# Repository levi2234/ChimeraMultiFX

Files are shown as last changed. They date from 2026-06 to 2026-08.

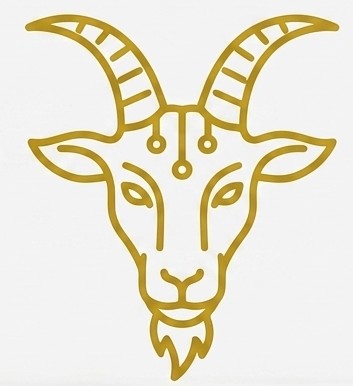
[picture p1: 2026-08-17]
hardware/boards/symbols/GOAT.jpg

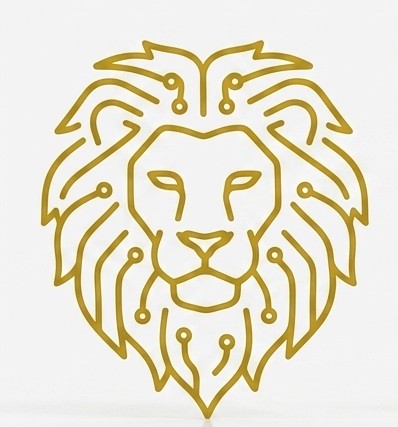
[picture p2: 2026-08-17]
hardware/boards/symbols/LION.jpg

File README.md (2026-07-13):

# ChimeraMultiFX

ChimeraMultiFX is a dual-MCU effects pedal platform. The Daisy Seed handles audio DSP while the ESP32 manages controls, Wi-Fi, and the browser-based UI.

## Repository layout

- [firmware/daisy](firmware/daisy) — Daisy Seed firmware built with libDaisy and DaisySP
- [firmware/esp32](firmware/esp32) — ESP32 control firmware and LittleFS web UI host
- [frontend](frontend) — Preact/Vite touch interface source
- [hardware/boards](hardware/boards) — KiCad PCB and schematic files
- [docs](docs) — repository notes and debugging write-ups

## Quick start

1. Review [firmware/daisy/README.md](firmware/daisy/README.md) for DSP build and flash steps.
2. Review [firmware/esp32/README.md](firmware/esp32/README.md) for ESP32 build, upload, and Wi-Fi setup.
3. Review [frontend/README.md](frontend/README.md) for local UI development.
4. Open [hardware/boards/daisyBoard.kicad_pro](hardware/boards/daisyBoard.kicad_pro) when working on hardware.

## Uploading code

- Daisy Seed: build with the Daisy make targets, then enter DFU bootloader mode and run the flashing command from [firmware/daisy/README.md](firmware/daisy/README.md).
- ESP32: build and upload from PlatformIO with the commands in [firmware/esp32/README.md](firmware/esp32/README.md).
- Frontend UI: build the web assets and upload them to the ESP32 filesystem using the steps in [frontend/README.md](frontend/README.md).

## Notes

- The ESP32 serves the built frontend from its LittleFS data partition.
- The Daisy and ESP32 communicate over UART; the ESP32 exposes a small HTTP/WebSocket bridge for the UI.

## License

MIT — see [LICENSE](LICENSE).

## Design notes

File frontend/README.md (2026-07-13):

# Frontend UI

This is the browser-based control surface for the pedal. It is built with Preact and Vite and is served by the ESP32 from LittleFS.

## Development

```bash
cd frontend
npm install
npm run dev
```

The Vite dev server is useful for UI work. Live DSP commands still depend on the ESP32 endpoints, so production testing should use the device URL.

## Build

```bash
cd frontend
npm run build
```

This writes the production bundle into [firmware/esp32/data](firmware/esp32/data), which the ESP32 serves as the web UI.

## Deploy

```bash
cd frontend
npm run build

cd ../firmware/esp32
pio run --target uploadfs
```

UI-only changes normally need only the filesystem upload step. If you changed the ESP32 firmware itself, run `pio run --target upload` as well.

## Structure

- [frontend/src/main.jsx](frontend/src/main.jsx) — app entry point
- [frontend/src/AppController.jsx](frontend/src/AppController.jsx) — main application state
- [frontend/src/components](frontend/src/components) — UI pieces such as lanes, knobs, and effect nodes

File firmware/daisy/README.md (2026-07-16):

# Daisy firmware

This firmware runs on the Daisy Seed and contains the DSP effect pipeline for the pedal.

## Build

```bash
git submodule update --init --recursive
cd firmware/daisy/deps/libDaisy
make
cd ../DaisySP
make
cd ../../
make
```

## QSPI boot setup

The application uses `BOOT_QSPI`, giving it nearly 8 MB of external flash. The
Daisy bootloader must be installed in internal flash once before QSPI
applications can run.

### DFU modes

The Seed has two different DFU implementations. Both can appear as USB device
`0483:df11`, but they expose different memory and are not interchangeable.

| DFU mode | Provided by | Memory exposed | Purpose | Command |
| --- | --- | --- | --- | --- |
| STM32 ROM DFU | Factory code inside the STM32 | Internal flash at `0x08000000` | Install or recover the Daisy bootloader | `make program-boot` |
| Daisy bootloader DFU | Daisy bootloader stored in internal flash | External QSPI flash from `0x90000000`, including the application at `0x90040000` | Upload the Chimera application | `make program-dfu` |

Enter STM32 ROM DFU by holding BOOT, pressing and releasing RESET, then
releasing BOOT. Enter Daisy bootloader DFU by pressing RESET without holding
BOOT, waiting for the user LED to pulse, then briefly pressing BOOT during the
two-second window.

Use `dfu-util -l` to tell them apart. STM32 ROM DFU reports `@Internal Flash
/0x08000000/...`; Daisy bootloader DFU reports an external `@Flash
/0x90000000/...` map. STM32 ROM DFU cannot upload the Chimera application to
QSPI, while the Daisy bootloader DFU is the normal mode for firmware updates.

### One-time bootloader installation

1. Connect the Daisy Seed to the computer over USB.
2. Enter the STM32 ROM DFU mode:
   - Hold the BOOT button.
   - Press and release RESET.
   - Release BOOT.
3. Install the Daisy bootloader:

```bash
cd firmware/daisy
make program-boot
```

## Upload code

The Daisy bootloader must be active before uploading a QSPI application. This
is different from the STM32 ROM DFU mode used to install the bootloader.

1. Connect the Daisy Seed over USB and release both buttons.
2. Press and release RESET only. Do not hold BOOT while pressing RESET.
3. Wait for the user LED to pulse during the Daisy bootloader's two-second DFU
   window, then briefly press BOOT to keep that window open.
4. Confirm that the Daisy bootloader is exposing QSPI flash:

```bash
dfu-util -l
```

The device description must contain an external flash map similar to:

```text
@Flash /0x90000000/64*4Kg/0x90040000/60*64Kg/...
```

If it reports only `@Internal Flash /0x08000000/...`, the Seed is in STM32 ROM
DFU mode and cannot write the QSPI application. Reset the Seed and repeat the
RESET-only, wait-for-pulse, then BOOT sequence above.

5. Build and upload the QSPI application:

```bash
cd firmware/daisy
make clean
make
make program-dfu
```

`program-dfu` writes the application to QSPI at `0x90040000`. `make program`
is intentionally unavailable for QSPI applications. If upload fails, confirm
that the Daisy bootloader is installed, its LED is pulsing, and `dfu-util` is
installed. The warning `Invalid DFU suffix signature` is harmless. An error
such as `Last page at 0x900... is not writeable`, together with an `Internal
Flash` interface name, means the Seed entered STM32 ROM DFU instead of the
Daisy bootloader.

For later uploads, the bootloader does not need to be reinstalled. If the Daisy
bootloader LED never pulses after a RESET-only press, enter STM32 ROM DFU using
the one-time setup sequence above and run `make program-boot` again.

## Quick test

The bridge protocol helper can exercise the UART command path from a host PC:

```bash
python Utils/bridge_protocol_test.py --serial-port COM9 ping info status "status lane 0"
```

State reads are intentionally split into bounded JSON responses:

- `status` returns only `lane_count` and `max_slots`.
- `status lane <lane>` returns routing and effect topology for one lane, without parameters.
- `status slot <lane> <slot>` returns live values and parameter definitions for one effect.

Clients should refresh only the lane or slot affected by a mutation. This keeps
response size independent of the total number of effect parameters in the rig.

The ESP32 firmware is the normal host for these commands in the finished system.

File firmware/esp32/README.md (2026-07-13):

# ESP32 control firmware

This firmware runs on the ESP32 and provides the pedal's control surface, Wi-Fi bridge, and browser UI host.

## What it does

- Connects to Wi-Fi and exposes a small HTTP/WebSocket API
- Bridges serial commands to the Daisy Seed over UART
- Serves the frontend from LittleFS so the UI can run without Node.js on the device

## Setup

1. Copy [firmware/esp32/src/wifi_credentials.example.h](firmware/esp32/src/wifi_credentials.example.h) to [firmware/esp32/src/wifi_credentials.h](firmware/esp32/src/wifi_credentials.h).
2. Add your local 2.4 GHz Wi-Fi credentials to the new file.
3. Install PlatformIO.

## Build and upload

```bash
cd frontend
npm install
npm run build

cd ../firmware/esp32
pio run
pio run --target upload
pio run --target uploadfs
```

### Upload steps

1. Connect the ESP32 board over USB.
2. Build the frontend assets if you changed the UI:
   ```bash
   cd frontend
   npm install
   npm run build
   ```
3. Upload the firmware:
   ```bash
   cd ../firmware/esp32
   pio run --target upload
   ```
4. Upload the web UI files to LittleFS:
   ```bash
   pio run --target uploadfs
   ```
5. Open the serial monitor if you want to confirm startup:
   ```bash
   pio run --target monitor
   ```

- `upload` flashes the ESP32 firmware.
- `uploadfs` updates the web UI assets in LittleFS.
- `pio run --target buildfs` builds the filesystem image without uploading it.

## Useful endpoints

- `GET /health`
- `GET /api/daisy/command?cmd=ping`
- `GET /api/bridge/selftest`

After boot, the board prints its IP address to the serial monitor. Use that address for the UI and API.

## Quick troubleshooting

If the Daisy bridge times out, run the protocol test from [firmware/daisy/Utils/bridge_protocol_test.py](firmware/daisy/Utils/bridge_protocol_test.py) and verify the UART wiring and ground connection between the two MCUs.

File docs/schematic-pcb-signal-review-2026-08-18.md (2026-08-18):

# ChimeraMultiFX Schematic, PCB, and Guitar Signal Review

**Date:** 2026-08-18  
**Design:** `hardware/boards/daisyBoard.kicad_sch` and `hardware/boards/daisyBoard.kicad_pcb`  
**Revision:** `d1bcdf6`  
**Scope:** Current schematic/PCB review, delta from the August 17 and August 18 reviews, and end-to-end risk of audible contamination of the guitar signal.

**2026-08-19 return-path recheck:** The current PCB has a GND via 0.875 mm from the `/SD_CLK_DAISY` transition and a GND via 1.09 mm from the `/SD_SCK` transition. Both provide a suitably short return path. `/SD_CLK_DAISY` now clears the analyzer; `/SD_SCK` remains reported only because the rule uses a hard 1.0 mm center-distance threshold and is treated as a false positive. No additional SD-clock return vias are required.

## Overview

ChimeraMultiFX is a dual-channel 48 kHz guitar-effects platform built around a Daisy Seed audio DSP and an ESP32 control/Wi-Fi processor. The carrier includes two buffered guitar inputs, two buffered audio outputs, a shared 2.5 V analog reference, expression inputs, two SD interfaces, socketed modules, and off-board audio jacks on a 100 mm x 100 mm four-layer PCB.

## Verdict

The analog signal path is now electrically plausible and should not strongly color the guitar band by itself. The 1 Mohm input bias preserves passive-pickup loading, the input RF poles are about 159 kHz, the output low-pass poles are about 21.9 kHz, and the coupling poles are below 2 Hz. The TL072H devices are valid at a nominal 5 V supply, and all unused op-amp channels are now biased as followers.

The design still has a **moderate, credible risk of audible Wi-Fi- or SD-correlated noise** in a prototype and a **significant unresolved risk for repeatable production or formal EMC testing**. The most likely symptoms are periodic ticks, buzz, discrete FFT spurs, startup pops, or a raised noise floor during ESP32 transmit and SD access. Gross loss of guitar tone is less likely than burst-correlated contamination or clipping on unusually hot inputs.

The static EMC score remains 37/100. This is a conservative layout-risk index, not a 37% pass probability. Sixty-nine of 118 EMC findings are heuristic reference-plane findings, so the score overstates the number of independent faults. The specific VREF, channel-2 audio, SD-clock, antenna, and cable-return mechanisms below remain physically credible.

## Critical Findings

| Priority | Finding | Guitar-signal impact | Required action |
|---|---|---|---|
| High | ESP32 is still represented by two headers with no exact body or antenna keepout | RF current can couple into the carrier, VREF, audio wiring, and enclosure; antenna behavior is not repeatable | Use the exact module/dev-board footprint and vendor keepout. Prefer antenna overhang and keep copper, traces, vias, wiring, and enclosure metal out of the specified volume. |
| High | VREF is 134.2 mm long, uses three layers and eight vias, with 51.3 mm on `In2.Cu` | Shared reference pickup appears at every analog stage and can become common-mode or output noise | Shorten the trunk, keep it over continuous GND, avoid the power layer, and add a GND return via beside each unavoidable transition. |
| Warning | `R24`, the 100 ohm VREF-buffer isolation resistor, was removed in the latest revision | Direct MCP6002 drive of a distributed capacitive net may reduce stability margin; exact load is unverified | Restore a small series isolation resistor close to U3 unless bench testing or a part-specific stability analysis proves direct drive is quiet and stable. Do not add large VREF capacitors downstream without validating the isolation network. |
| Warning | `/AUDIO_IN_2` and `/AUDIO_OUT_2` each change layers without nearby return stitching | RF return current detours can increase pickup and rectification in channel 2 | Keep each net on one outer layer or place a GND via next to the signal via. |
| Warning | `/SD_CLK_DAISY` and `/SD_SCK` change layers and remain on outer layers | Their adjacent GND vias provide short return paths, but clock ringing can still inject conducted or radiated energy | Keep the existing return vias and add source-series resistor footprints, nominally 22-47 ohm and selected from scope measurements. |
| High | Exact MPN coverage is 0% and no project datasheet cache exists | Ferrite current/DCR, bulk-cap effective value, module pinout, LED rating, and analog headroom are not reproducible | Populate Manufacturer/MPN/datasheet fields for all ICs, modules, ferrites, bulk capacitors, LEDs, SD sockets, and connectors. |
| Warning | Eleven via-in-pad findings remain in the ESP32 power/reference cluster | Open vias can wick solder and make power filtering inconsistent between assemblies | Move the vias outside lands or specify filled/capped via-in-pad fabrication. |
| Warning | `D1` with `R32 = 27 ohm` is estimated near 41 mA | Excess LED current can add supply/ground disturbance and threatens the LED | Select the LED and recalculate for about 1-5 mA unless high brightness is explicitly required. |

## Component Summary

The fresh schematic analysis found 112 non-power components across 163 nets: seven ICs, 31 resistors, 34 capacitors, 14 connectors, 19 test points, five LEDs, and two ferrite beads. The PCB contains 118 footprints and 104 physical nets. MPN coverage is 0/35 unique BOM parts, so component ratings and lifecycle status are not production-verified.

## Power Tree

```text
External +5 V
|-- FB2 -> VCC_Daisy
|   |-- Daisy Seed/module rails
|   |-- IC1-IC4 TL072H audio buffers
|   `-- U1-U2 MCP6002 expression buffers
|-- U3 MCP6002
|   `-- 100k/100k filtered midpoint -> U3A -> VREF
`-- FB1 -> VCC_ESP32
  `-- ESP32 module input and local 3.3 V regulation
```

The complete source current, module regulator limits, ferrite drop, and ESP32/SD peak demand cannot be checked without exact module and ferrite MPNs.

## Previous Review Delta

| Status | Item | Current result |
|---|---|---|
| Fixed | Standard TL072 below its minimum supply | `IC1`-`IC4` are `TL072HIDR`, whose family supports a 4.5 V minimum total supply. |
| Fixed | Floating unused TL072 channels | Pins 5 are on VREF and pins 6/7 form local followers on all four devices. |
| Fixed | Floating unused U3B channel | U3B is now a follower referenced to the filtered 2.5 V divider node. |
| Fixed | Residual analog via-in-pad at `C29:1` and `U3:8` | Neither is present in the fresh PCB findings. |
| Improved | Schematic/PCB consistency | No-connect markers fell from 25 to 10; cross-analysis findings fell from eight to seven. |
| Regressed | VREF isolation | `R24 = 100 ohm` was removed and U3A now drives VREF directly. |
| Regressed | VREF route length | The route increased from about 118.7 mm to 134.2 mm and now has eight vias. |
| Open | ESP32 antenna implementation | No keepout or rule area exists; only the two 1x15 header rows define the module. |
| Improved | SD/audio return transitions | Both SD clocks have acceptable adjacent GND vias. `/AUDIO_IN_2` now has a GND via 1.30 mm away; `/AUDIO_OUT_2` has no explicit GND via closer than 5.22 mm. |
| Open | Exact sourcing and ratings | Structured MPN coverage remains 0%. |
| Open | Native release evidence | No saved ERC/DRC report and no current Gerber release were found. |

## Signal Analysis Review

## End-to-End Audio Path

### Input channels

Each guitar input follows this topology:

```text
Jack tip
  -> 100 pF shunt RF capacitor
  -> 1 uF AC-coupling capacitor
  -> 1 kohm series resistor
  -> 1 nF shunt capacitor + 1 Mohm bias to VREF
  -> TL072H unity-gain buffer
  -> Daisy audio input
```

The nominal input coupling pole is:

$$
f_{HP,in} = \frac{1}{2\pi(1\,\text{M}\Omega)(1\,\mu\text{F})} \approx 0.16\,\text{Hz}
$$

The 1 kohm/1 nF RF pole is:

$$
f_{LP,in} = \frac{1}{2\pi(1\,\text{k}\Omega)(1\,\text{nF})} \approx 159\,\text{kHz}
$$

This is a good nominal guitar input impedance and should not remove audible bass or treble. The high-impedance node is nevertheless sensitive to RF, jack wiring, flux contamination, and VREF noise. Keep the off-board run shielded or use a twisted signal/return pair.

### Output channels

Each Daisy output follows this topology:

```text
Daisy audio output
  -> 3.3 kohm series resistor + 2.2 nF shunt capacitor
  -> 1 uF AC-coupling capacitor + 1 Mohm bias to VREF
  -> TL072H unity-gain buffer
  -> 100 ohm output resistor
  -> 1 uF output coupling capacitor
  -> 100 kohm pulldown
  -> output jack
```

The nominal reconstruction pole is:

$$
f_{LP,out} = \frac{1}{2\pi(3.3\,\text{k}\Omega)(2.2\,\text{nF})} \approx 21.9\,\text{kHz}
$$

The final 1 uF/100 kohm coupling pole is about 1.6 Hz. The 21.9 kHz first-order pole is approximately 0.8 dB down at 10 kHz and 2.6 dB down at 20 kHz. That is mild ultrasonic filtering, not severe guitar-band coloration, but capacitor tolerance should be included in an audio sweep.

### Route geometry

| Net | Length | Layers | Vias | Assessment |
|---|---:|---|---:|---|
| `/AUDIO_IN_1` | 70.35 mm | F.Cu | 0 | Long but single-layer; lower risk than channel 2 if continuously referenced to GND. |
| `/AUDIO_IN_2` | 63.49 mm | F.Cu/B.Cu | 1 | Add an adjacent return via. |
| `/AUDIO_OUT_1` | 55.09 mm | F.Cu | 0 | Single-layer and relatively low impedance. |
| `/AUDIO_OUT_2` | 46.58 mm | F.Cu/B.Cu | 1 | Add an adjacent return via. |
| `VREF` | 134.24 mm | F.Cu/B.Cu/In2.Cu | 8 | Highest shared analog coupling concern. |

No direct trace-proximity pairs were reported between audio/VREF and SD, UART, or ESP32 nets at the analyzer threshold. This reduces direct crosstalk risk. It does not cover far-field 2.4 GHz coupling, shared plane impedance, enclosure/cable coupling, or demodulation at op-amp inputs.

## Power and Ground

The four-layer order is `F.Cu / In1.Cu GND / In2.Cu power+GND / B.Cu`. The stored `In1.Cu` GND zone is filled at about 85.8% of board area and is the correct adjacent reference for top-side signals. The schematic calls the analog return `GNDA`, while the PCB intentionally implements it as the single `GND` net; there is not a physical split analog plane.

The connectivity analyzer reports seven GND islands, but most analog pads and 48 GND vias belong to one common island and the stored `In1.Cu` fill is one broad region. The isolated entries are concentrated around ESP power capacitors and SD socket pads and are likely union/zone-model artifacts. Do not accept or dismiss them solely from this analyzer: refill all zones and require native KiCad DRC to show zero unconnected items.

`FB1` isolates the ESP branch and `FB2` isolates the Daisy/analog branch, which is directionally good. Their impedance labels alone do not establish current capacity, DCR, DC bias behavior, or useful attenuation with the actual load-side capacitors. ESP32 current bursts and SD writes must be measured at `VCC_ESP32`, `VCC_Daisy`, and VREF simultaneously.

## PDN Impedance

The idealized analyzer model still indicates small anti-resonance regions near 5 MHz on `VCC_Daisy` and 7.9 MHz on `VCC_ESP32`. These are screening estimates only: generic capacitor parasitics, unknown DC-bias derating, unspecified ferrites, module-local capacitance, and mounting inductance prevent a verified impedance prediction.

## Power Budget

The schematic model estimates roughly 120 mA for the six analog ICs on `VCC_Daisy` and about 20 mA for U3 on +5 V. These coarse defaults exclude Daisy processing load, ESP32 transmit peaks, both SD cards, LEDs, and external loads. Size and measure the 5 V source and ferrites for simultaneous DSP, Wi-Fi transmit, and SD write activity.

## Sleep Current Audit

The design is not presently optimized as a battery-sleep product. Module current is not modeled, and the analyzer's state-based resistor-path estimate is not meaningful for product battery life without defined rail shutdown states. If battery operation is intended, add a hardware power-state budget and controllable rail isolation.

## Bus Topology

The board uses UART between ESP32 and Daisy, two independent SD/SPI-style interfaces, two audio input/output channels, and two expression ADC channels. The SD clocks are the highest-risk digital aggressors because both change layers without adjacent return vias; add source damping footprints and keep the interfaces over continuous GND.

## PCB Layout Analysis

- Board: 100 mm x 100 mm, four copper layers, 118 footprints, 104 PCB nets, 634 track segments, and 98 vias.
- Routing is represented as complete by the parser.
- Cross-analysis still reports `/SD_CLK_DAISY` crossing a `+3.3VD` plane boundary and audio nets crossing `+3.3VA` power-region boundaries. These are not proof of a broken GND return because `In1.Cu` is GND, but they indicate layer-3 power fragmentation and should be visually inspected.
- No enforceable antenna keepout exists anywhere on the PCB.
- `Card2` is reported only 0.32 mm from the board edge. Verify socket body, card insertion, copper clearance, and assembly panelization.
- No front-side fiducials were detected for 82 SMD components.
- Test-point coverage is about 11%. Add UART and both SD clocks; the existing audio, rail, VREF, and GND probes are useful.
- The remaining 11 via-in-pad cases are `C21`, `C22`, `C23`, `FB1`, `R22`, `R23`, and `TP21`, concentrated around ESP power and the reference-divider area.
- The existing fabrication archive predates this revision. It must not be ordered as the current board.

## EMC / Cross-Domain Analysis

The original FCC Class B-oriented static score was 37/100 from 118 findings across seven useful categories. After the return-path edits, a current rerun scores 46/100 with 117 findings. The credible subset is the missing return vias on VREF and `/AUDIO_OUT_2`, outer-layer clock routing, `/SD_CLK_DAISY` proximity to `J13`, and the absent ESP32 antenna keepout. `/AUDIO_IN_2` has a practical return via at 1.30 mm. The remaining `/SD_SCK` return warning is a threshold false positive because its GND via is 1.09 mm away. The repeated `GP-001` plane-coverage findings are heuristic and require visual/native DRC confirmation rather than literal counting.

## Thermal Analysis

The thermal analyzer ran at 40 C ambient but assessed zero components because no part had both quantifiable dissipation and usable MPN/datasheet data. This is a verification gap, not evidence that the ESP regulator, ferrites, SD cards, or analog devices will remain cool under sustained load.

## Test Coverage

Nineteen schematic test points cover about 11% of physical PCB nets, including useful audio, VREF, rail, and ground probes. Add accessible pads for UART, both SD clocks, and any module rail needed to correlate digital activity with audio artifacts.

## Assembly Complexity

The board has 82 front-side SMD components and no detected global fiducials. The main assembly risks are the 11 open via-in-pad cases, generic 100 uF footprints, unspecified socket/module geometry, and the SD socket edge placement rather than raw placement count.

## BOM Optimization

Further passive-value consolidation is not a priority. Preserve the intentional filter, bias, LED, and isolation values; focus BOM work on exact MPN qualification, capacitor technology/derating, ferrite current/DCR, and package consistency.

## How Real Is the Audible-Risk?

| Mechanism | Current risk | Why |
|---|---|---|
| Passive pickup loading / bass loss | Low | 1 Mohm input bias and approximately 0.16 Hz coupling pole. |
| Intended high-frequency rolloff | Low to moderate | About 0.8 dB at 10 kHz and 2.6 dB at 20 kHz from the output RC stage; verify component tolerance. |
| Normal op-amp hiss | Low to moderate | TL072H is appropriate for audio, but total noise depends on source impedance, resistor noise, gain staging, and Daisy converter noise. |
| Clipping with boosted/hot guitar levels | Moderate, unquantified | TL072H operates at 5 V, but input common-mode and output swing margin must be measured at the real load and VREF. |
| Wi-Fi burst ticking/buzz | Moderate | Physical separation and ferrite branches help; absent antenna keepout, long VREF, cable pickup, and shared return paths keep the mechanism credible. |
| SD-correlated tones | Moderate | Both clocks use layer transitions without adjacent return vias; `/SD_CLK_DAISY` also runs near `J13`. |
| Channel-to-channel mismatch | Low to moderate | Topologies match, but channel 2 has two additional signal transitions and different layer usage. |
| Assembly-induced noise/intermittence | Moderate | Eleven open via-in-pad findings and unspecified bulk/ferrite parts can create board-to-board variation. |

For a one-off enclosed prototype, a clean result is plausible and the board is not doomed to be noisy. For a repeatable product, the remaining risks are too dependent on exact module placement, cable routing, component selection, and enclosure bonding to call the audio path clean without measurement.

## Bench Acceptance Plan

1. Terminate the input with a pickup-like source impedance and record 20 Hz-20 kHz FFT/noise with Wi-Fi disabled, associated-idle, continuous transmit, and maximum configured transmit power.
2. Repeat while continuously reading and writing each SD interface. Compare channels separately to expose the channel-2 transition penalty.
3. Drive 100 Hz, 1 kHz, and 10 kHz tones; sweep input amplitude to find clipping at the input buffer, Daisy ADC/DAC, and output buffer. Record THD+N and maximum clean peak-to-peak level.
4. Sweep 20 Hz-24 kHz and compare measured response against the 21.9 kHz nominal output pole.
5. Probe VREF, `VCC_Daisy`, and `VCC_ESP32` during Wi-Fi and SD bursts. Look for correlated ripple, ringing, or sustained oscillation after the removal of `R24`.
6. Test boot, reset, firmware update, cable hot-plug, and Daisy clock loss for pops.
7. Repeat with the final shielded/twisted jack harness and final enclosure. Compare lid open/closed and antenna inside/overhanging the enclosure.
8. Use a near-field probe around the ESP power branch, antenna region, SD clocks, VREF buffer/trunk, and both input filters.

## Analyzer Verification

Fresh artifacts are under `analysis/2026-08-18_signal_review/`.

- Schematic analyzer: 112 components, 163 nets, 82 findings.
- Full PCB analyzer with proximity: 118 footprints, 104 nets, 634 segments, 98 vias, 69 findings.
- Schematic/PCB cross-analysis: seven findings.
- FCC Class B-oriented EMC analysis: 118 findings, 37/100 static score, seven useful categories.
- Thermal analyzer at 40 C: ran but assessed zero components because no usable MPN/dissipation data exist.
- Raw schematic, PCB, current Git delta, prior reports, and current zone/route metrics were inspected.

### Reviewer overrides

- The 69 `GP-001` findings are not 69 independent faults. The broad `In1.Cu` GND fill is real; local return discontinuities still require visual/native DRC inspection.
- The seven reported GND islands are not accepted literally because the connectivity model appears to separate pad/via/zone constructs in the ESP cluster. Native DRC is the deciding check.
- Several `DC-003` findings associate signal capacitors with unrelated IC decoupling. The dedicated local 100 nF capacitors remain the valid bypass evidence.
- Six schematic jacks absent from the PCB are treated as intentional off-board hardware. Mark them excluded from board and document the harness.

## Not Performed / Review Limits

- Native KiCad ERC/DRC was not independently run because `kicad-cli` is unavailable. The latest commit says DRC was checked, but no report is stored for review.
- SPICE was not run because ngspice, LTspice, and Xyce are unavailable.
- Datasheet extraction and lifecycle audit were not possible because no `datasheets/` cache exists and structured MPN coverage is 0%. Except for the previously established TL072H supply-family check, pin, rating, ferrite, and capacitor conclusions are consistency or plausibility checks.
- Thermal analysis had no modelable components; zero findings does not mean zero thermal risk.
- Current Gerbers were not available, so fabrication-layer and paste/drill checks apply only to the stale archive.
- Static analysis cannot predict absolute audible noise or regulatory margin. Final cables, enclosure, antenna placement, firmware activity, and source/load impedances require measurement.

## Recommended Order

1. Implement the exact ESP32 module footprint and antenna keepout/overhang.
2. Shorten VREF, remove it from `In2.Cu`, add transition return vias, and restore or validate output isolation at U3.
3. Keep the existing SD-clock return vias, add a closer return via for `/AUDIO_OUT_2`, and add source damping footprints for the clocks.
4. Qualify exact ferrites, bulk capacitors, modules, LEDs, sockets, and analog IC suffixes with structured MPN fields.
5. Correct `D1` current and resolve the remaining ESP-cluster via-in-pad construction.
6. Refill zones and save clean native ERC/DRC reports.
7. Regenerate and independently inspect Gerber, drill, BOM, and CPL outputs.
8. Pass the Wi-Fi/SD audio test matrix in the final enclosure before calling the signal path production-clean.

## Readiness

**Prototype bring-up:** reasonable after the antenna/VREF/return-via changes, with mandatory audio-noise and clipping tests.  
**Another fabrication order:** not recommended yet.  
**Production or FCC/CE readiness:** not demonstrated.

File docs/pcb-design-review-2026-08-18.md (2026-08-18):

# ChimeraMultiFX Schematic and PCB Review

**Date:** 2026-08-18  
**Design:** `hardware/boards/daisyBoard.kicad_sch` and `hardware/boards/daisyBoard.kicad_pcb`  
**Product intent:** Dual-channel 48 kHz Daisy Seed guitar-effects DSP with ESP32 Wi-Fi/control, browser UI, expression inputs, removable storage, and off-board audio jacks.

## Overview

The board combines a Daisy Seed audio engine, ESP32 network/control processor, dual analog audio conditioning, expression inputs, two SD interfaces, and off-board controls in a 100 mm x 100 mm four-layer design. The review prioritizes audio headroom and noise, reference stability, Wi-Fi/SD return paths, module integration, manufacturability, and repeatable sourcing.

## Verdict

**Not ready for fabrication yet, but materially improved.** `IC1`-`IC4` are now the 4.5 V-qualified `TL072HIDR`, all unused amplifier channels are safely biased, and the broad analog via-in-pad issue is almost completely resolved. Remaining pre-fabrication concerns are the missing ESP32 antenna keepout, two residual analog pad/via overlaps, long VREF routing, unqualified ferrites/bulk capacitors, absent structured MPN fields, and no current native DRC/ERC or Gerber release.

## Previous Review Delta

| Status | Item | Current result |
|---|---|---|
| Fixed | Local op-amp bypassing | All seven analog ICs now have a same-side 100 nF supply bypass about 2.2-3.1 mm from the package center. |
| Fixed | Layer order | `In1.Cu` is now the GND plane and `In2.Cu` is the power layer. The stored GND fill is one region with about 85.6% area coverage. |
| Fixed | TL072 supply range | `IC1`-`IC4` now specify `TL072HIDR`, whose 4.5 V minimum total supply includes the nominal 5 V rail. Pin 8 is VCC+ and pin 4 is GND in the selected SOIC-8 package. |
| Fixed | Unused op-amp channels | `IC1B`-`IC4B` pin 5 is on buffered VREF and each pin 6/7 pair shares a local feedback net. `U3B` pin 5 is on the filtered 2.5 V divider node and pins 6/7 share a local feedback net. |
| Improved | Analog via-in-pad | Analog-related VP-001 findings fell from 23 to 2; all four TL072H supply-pad overlaps were removed. |
| Improved | Overall via-in-pad | VP-001 findings fell from 84 to 13. Most remaining cases are in the ESP power cluster; `C29:1` and `U3:8` are the two remaining analog cases. |
| New | Analog rail ferrite | `FB2` replaces `NT1` between +5 V and VCC_Daisy. Connectivity is correct, but its current rating and DCR are unspecified. |
| Improved | EMC static score | Analyzer score increased from 13/100 to 37/100. This is a relative risk metric, not a compliance prediction. |
| Open | ESP32 antenna implementation | ESP32 remains two 1x15 headers with no body, antenna outline, courtyard, or copper/routing keepout. |
| Open | VREF distribution | About 118.7 mm long, six layer changes, and about 52.7 mm routed on the inner power layer. |
| Open | Sourcing/verification | MPN coverage remains 0%; exact pinout, ratings, capacitor derating, and ferrite suitability cannot be fully verified. |
| New | LED current | `D1` uses `R32 = 27 ohm`; static analysis estimates about 41 mA, excessive for a 0201 indicator LED. |

## Critical Findings

| Severity | Issue | Action before fabrication |
|---|---|---|
| High | No enforced ESP32 antenna keepout | Use the exact module/dev-board footprint and clear copper, tracks, vias, components, wiring, and enclosure metal around the antenna. Prefer antenna overhang. |
| High | No exact MPNs | Add MPN/manufacturer fields for ICs, modules, ferrites, LEDs, bulk capacitors, connectors, and SD sockets. |
| Warning | Two analog pad/via overlaps remain | Move the GND via out of `C29:1` and the supply via out of `U3:8`, or specify filled/capped via-in-pad. |
| Warning | `C18` and `C31` return vias are about 3.1/3.0 mm away | Bring each true bypass return via adjacent to the capacitor ground pad without putting the drill inside the solder land. |
| Warning | `FB2` is unqualified | Select an exact 0805 ferrite with sufficient current rating, low DCR, and impedance curve for the Daisy plus analog load. |
| Warning | VREF is long and changes layers six times | Keep it on an outer layer where practical, shorten the trunk, and place a GND return via beside each unavoidable transition. |
| Warning | Four nominal 100 uF capacitors use generic 1206 footprints | Select exact parts and validate package, polarity, voltage rating, effective capacitance under DC bias, leakage, and assembly orientation. |
| Warning | `D1` current is excessive | Recalculate for the chosen LED. A status LED usually needs roughly 1-5 mA, not about 41 mA. |
| Warning | Current Gerbers were not regenerated | Export a fresh fabrication set after all changes and inspect it in an independent CAM viewer. |

## Component Summary

The schematic analyzer found 113 non-power components: 7 ICs, 32 resistors, 34 capacitors, 14 connectors, 19 test points, 5 LEDs, and 2 ferrite beads across 174 schematic nets. The PCB contains 119 footprints, including intentional module/header and mechanical content. Exact sourcing data remain absent from structured MPN properties for all 35 unique BOM parts.

## Power Tree

```text
External +5 V
├── FB2, 600 ohm @ 100 MHz → VCC_Daisy
│   ├── Daisy Seed/module rails
│   ├── IC1-IC4 TL072HIDR audio op amps
│   └── U1-U2 expression buffers
├── U3 MCP6002
│   └── 100k/100k midpoint → U3A buffer → 100R → VREF
└── FB1 → VCC_ESP32
	└── ESP32 module input and local 3.3 V rail
```

The exact source current capability, ferrite drop, module regulator limits, and peak ESP32 demand remain unverified because source/module/ferrite MPNs are missing.

## Signal Analysis Review

Static analysis recognized the VREF divider/filter, analog RC networks, op-amp stages, SD/UART buses, and local decoupling. The op-amp configuration detector could not classify the stages reliably, so the critical analog conclusions below come from raw pin/net inspection rather than topology labels alone. SPICE confirmation is unavailable.

## VREF Review

The buffered-reference topology is directionally good:

- `R22 = 100 kohm` and `R23 = 100 kohm` create a nominal 2.5 V midpoint from 5 V.
- `C19 = 100 uF` and `C20 = 100 nF` filter the midpoint before `U3A`.
- `U3A` (MCP6002) is wired as the buffer.
- `R24 = 100 ohm` isolates the buffer output from the distributed VREF load and its parasitic capacitance.
- The four audio bias feeds use 1 Mohm resistors, so DC loading and drop across `R24` should be small.

With a 50 kohm Thevenin source and nominal 100 uF, the low-frequency pole is approximately:

$$
f_c = \frac{1}{2\pi(50\,\text{k}\Omega)(100\,\mu\text{F})} \approx 0.032\,\text{Hz}
$$

Do not add a large capacitor directly to the MCP6002 output by default. A capacitive load can reduce phase margin; the existing 100 ohm isolation resistor is the right kind of mitigation. If local VREF capacitors are added at remote stages, validate the total capacitance and isolation network against the exact op-amp datasheet or simulation.

### VREF layout observations

- Total routed length is about 118.7 mm: 51.4 mm on B.Cu, 14.9 mm on F.Cu, and 52.4 mm on `In2.Cu`.
- Six VREF transitions have no GND stitching via within 1 mm.
- Routing VREF on the power layer cuts and constrains power copper. Prefer a short outer-layer trunk over continuous `In1.Cu` GND.
- Keep VREF away from ESP32 antenna/current-burst paths and SD clocks.
- Probe VREF at `TP5` during Wi-Fi transmit and full-scale audio. Check DC level, startup settling, audio-band noise, and burst-correlated ripple.

## Local Decoupling

The new bypass network is a clear improvement and the net assignments are correct.

| IC | Bypass | Nets | Approx. distance | Assessment |
|---|---|---|---:|---|
| `IC1` | `C18`, 100 nF | VCC_Daisy-GND | 2.61 mm | Good |
| `IC2` | `C27`, 100 nF | VCC_Daisy-GND | 3.07 mm | Acceptable; move slightly closer if easy |
| `IC3` | `C26`, 100 nF | VCC_Daisy-GND | 2.31 mm | Good |
| `IC4` | `C28`, 100 nF | VCC_Daisy-GND | 2.51 mm | Good |
| `U1` | `C29`, 100 nF | VCC_Daisy-GND | 2.17 mm | Good |
| `U2` | `C30`, 100 nF | VCC_Daisy-GND | 2.78 mm | Good |
| `U3` | `C31`, 100 nF | +5V-GND | 2.17 mm | Good |

For the next layout pass:

- Prefer 0402 or 0603 for 100 nF high-frequency bypassing unless hand assembly dictates otherwise. A 1206 has higher connection inductance and is physically harder to place tight to SOIC supply pins.
- Route supply pin to capacitor first, then into the rail; connect the ground pad immediately to `In1.Cu` with an adjacent via.
- Avoid open vias centered in IC or capacitor lands. Tented opposite-side vias still can wick solder unless the fabricator fills/caps them.
- The revised layout clears this condition for nearly every analog IC and bypass capacitor. Move the remaining `C29:1` and `U3:8` vias as well.
- `C18` and `C31` are close to their ICs, but their nearest vias are now about 3.1 mm and 3.0 mm away. Put a GND via immediately beside each capacitor ground pad.
- Keep one local 1 uF per analog cluster and bulk capacitance at the rail entry.

## Op-Amp Suitability

### TL072HIDR

`IC1`-`IC4` now specify TI `TL072HIDR`. TI rates TL07xH for 4.5-40 V total supply, so nominal 5 V operation is valid. The selected `D` package is SOIC-8 and matches the existing footprint and pin map: pin 8 VCC+, pin 4 VCC-. The part is not rail-to-rail output, so clean input/output headroom around the 2.5 V reference still requires bench verification with worst-case boosted guitar levels.

The current schematic value identifies the exact part, but the structured MPN field remains empty and the Datasheet property incorrectly points to `tl074a`. Set Manufacturer=`Texas Instruments`, MPN=`TL072HIDR`, LCSC=`C4370389`, and Datasheet=`https://www.ti.com/lit/gpn/TL072H` on `IC1`-`IC4`.

### MCP6002

Microchip identifies MCP6002 as an in-production 1 MHz low-power op amp operating from 1.8 V. Its use at 5 V is plausible and the 100 ohm VREF output isolation is helpful. At about 28 nV/sqrt(Hz), it is not an especially low-noise audio amplifier, but it is reasonable for expression buffering and a low-current reference. Exact suffix/temperature/package MPNs are still required.

### Unused channels

All unused channels are now configured as followers at a valid 2.5 V bias. `IC1B`-`IC4B` have pin 5 on VREF and pins 6/7 on one local feedback net. `U3B` has pin 5 on the filtered divider node shared with `U3A` pin 3, `R22`, `R23`, `C15`, `C19`, and `C20`; pins 6/7 share one local feedback net. The unused outputs are not paralleled with VREF, which is correct.

## PCB Layout Analysis

### Positive findings

- Four-layer 100 mm x 100 mm board with `F.Cu / In1.Cu GND / In2.Cu power / B.Cu` ordering.
- Stored `In1.Cu` GND fill is one region and covers about 85.6% of the board area.
- ESP32 power remains isolated through `FB1` with local bulk and ceramic capacitance.
- Analog and digital regions are physically separated to a useful degree.
- Parser reports all routed nets complete.
- Analog-related via-in-pad findings dropped from 23 to 2; all TL072H solder lands are now clear of drilled vias.

### Remaining risks

- No keepout zones exist anywhere on the PCB. Copper remains under the probable ESP32 antenna area.
- VREF, audio, expression, and SD nets still change layers without nearby GND return vias.
- `/SD_CLK_DAISY` and `/SD_SCK` change layers without adjacent return vias and run on outer layers. Add source damping footprints if supported by the module interface and measured edge rate.
- The default net class permits 0.127 mm clearance and includes 0.127 mm routing. Use explicit classes for audio, power, SD clocks, and general signals instead of one permissive class.
- `Card2` is reported about 0.32 mm from the board edge. Verify the connector body, card insertion geometry, and fabricator copper-to-edge rules.
- No front-side fiducials were detected for 83 SMD parts. Add three global fiducials if using automated assembly.
- Test coverage is about 10%. Add accessible points for all rails, VREF, UART, SD clocks, and audio stage inputs/outputs.
- Two analog overlaps remain: `C29:1` and `U3:8`. Eleven additional VP-001 cases remain in the ESP power/reference cluster and should be reviewed before stencil assembly.

## EMC / Cross-Domain Analysis

The static FCC Class B-oriented risk score improved to 37/100 after the GND-first stack and local bypass changes. The remaining deterministic concerns are layer transitions without adjacent GND vias, outer-layer SD clocks, SD clock proximity to `J13`, and the absent ESP32 antenna keepout. The score cannot predict compliance or account for the final enclosure and cable harnesses; use it to prioritize bench and pre-compliance measurements.

### How impactful the 37/100 score is

The score is a conservative layout-risk index, not a percentage chance of passing, a 37% compliance result, or a measured dB margin. A value below 50 means the analyzer found enough common EMC failure patterns to justify another layout pass and bench testing. It does not by itself prove that this pedal will fail FCC or CE testing.

For this board, the score is more pessimistic than the raw layout evidence supports:

- 69 of 117 findings are `GP-001` reference-plane coverage findings: 59 errors and 10 warnings.
- The raw `In1.Cu` GND zone is filled as one region at about 85.8% board-area coverage, so the reported signal-by-signal plane gaps and 10 GND islands are not accepted literally.
- The scoring algorithm caps repeated findings from one rule, but `GP-001` still dominates the report and should be visually checked rather than counted as 69 independent faults.
- Only 7 of the analyzer's 18 EMC categories ran with useful data. The generated frequency-band plan reports no identified sources because exact module clocks, edge rates, switching frequencies, cable lengths, and enclosure geometry are unavailable. That is a coverage gap, not evidence of no emissions.

The credible residual risk is **moderate for a one-off enclosed prototype and significant for a product intended for sale or formal FCC/CE testing**. The likely first symptom is not necessarily a regulatory failure. For a guitar pedal, RF susceptibility and internal coupling can become audible before radiated emissions exceed a legal limit:

- Wi-Fi or SD activity can be demodulated by high-impedance audio inputs or VREF and appear as ticking, buzz, or a raised noise floor.
- Long guitar, amplifier, expression, USB, and power cables can carry common-mode current and become much better antennas than the 100 mm PCB itself.
- A metal enclosure can reduce direct electric-field radiation, but cable exits, unbonded jack grounds, seams, and the ESP32 antenna opening remain important.
- The ESP32 is an intentional 2.4 GHz radiator. Module approval helps only when the approved antenna/layout conditions are preserved; it does not certify the complete carrier, cables, clocks, or power network.

The highest-risk nets from the current analysis are `/SD_CLK_DAISY` with four rule hits and `/SD_SCK` with three. They combine outer-layer routing, reference-plane concerns, and missing return vias at layer changes. VREF, audio channel 2, expression inputs, and other SD signals have lower-severity transition findings that matter primarily because they can couple RF into the audio path.

### EMC improvement priority

1. **Implement the exact ESP32 antenna keepout.** Use the real module footprint, place the antenna at or beyond the board edge, and prohibit copper, traces, vias, components, wiring, and enclosure metal in the vendor-defined volume on every layer.
2. **Verify a continuous return plane under both SD clock routes.** Keep `/SD_CLK_DAISY` and `/SD_SCK` on one outer layer over uninterrupted `In1.Cu` GND where practical. Do not cross plane slots, power-zone boundaries, or antenna keepouts.
3. **Add return vias at every high-speed transition.** Put a GND via within about 1 mm of each SD/UART signal via. Also add nearby return vias for VREF, audio, and expression transitions to reduce RF loop area.
4. **Provide source-series damping footprints.** Place optional `22-47 ohm` resistors at the driving end of each SD clock and other fast single-ended lines. Start unpopulated or around 33 ohm, then select the value from oscilloscope edge/ringing measurements rather than treating one value as universal.
5. **Separate clocks from analog and connectors.** Increase spacing between SD clocks and VREF, audio inputs, expression inputs, and cable/header regions. The current `/SD_CLK_DAISY` proximity to `J13` is a credible coupling path.
6. **Finish the bypass-via cleanup.** Move `C29:1` and `U3:8` vias out of the lands and put the `C18` and `C31` GND vias directly beside their capacitor pads. Compact supply loops reduce both emissions and RF susceptibility.
7. **Control cable common mode.** Route each off-board audio/expression signal with an adjacent return conductor, preferably as shielded cable or twisted signal/ground. Add low-capacitance ESD protection at the connector and preserve the existing input RF filtering. Bond jack sleeves and enclosure deliberately instead of relying on incidental mechanical contact.
8. **Qualify `FB1` and `FB2`.** Select exact ferrites using impedance-versus-frequency, current rating, and DCR. Place local bulk plus 100 nF capacitance on the load side and verify that ESP32 transmit or Daisy load steps do not modulate analog rails.
9. **Add targeted ground stitching.** Stitch around connector regions and digital/analog boundaries. Near a 2.4 GHz antenna keepout boundary, approximately 3 mm spacing is a conservative RF fence target, but never place stitching inside the antenna keepout.
10. **Keep explicit net classes.** Give clocks, analog, and power intentional width/clearance rules rather than relying on the permissive default class.

### Practical EMC and audio-noise test plan

- Compare the audio FFT/noise floor with Wi-Fi disabled, associated but idle, continuous transmit, and maximum configured transmit power.
- Repeat while reading and writing both SD interfaces. Listen and measure specifically for clock-correlated tones and periodic bursts.
- Probe VREF, VCC_Daisy, VCC_ESP32, and the op-amp outputs simultaneously during Wi-Fi and SD load steps.
- Use a small H-field probe around the ESP power branch, SD clocks, FB1/FB2, VREF buffer, and audio input stages. Start with 30-300 MHz and inspect 2.4 GHz behavior with suitable equipment.
- Attach the final guitar, amplifier, expression, USB, and power cables during testing; cable radiation and susceptibility cannot be evaluated with the board alone.
- Test inside the final enclosure with all jack hardware and shields installed. Compare lid open/closed and antenna near/far from enclosure metal.
- Before commercial release, perform radiated and conducted pre-compliance scans. The static score is useful for prioritization but cannot replace measurement.

### Analyzer overrides

- The reported 10 GND islands are not accepted literally. The raw stored zone has one filled `In1.Cu` GND region at about 85.8% fill. The connectivity graph appears to count isolated pads/tracks as islands.
- Many GP-001 findings are similarly inflated. The corrected GND-first stack is real; local void crossings still need KiCad DRC and visual inspection.
- The two remaining analog via-in-pad warnings are geometric and real. Most prior findings were resolved by moving the vias beside the pads.
- Six schematic jacks (`J6`-`J11`) missing from the PCB appear to be off-board hardware. Mark them excluded from board and document the harness so this is intentional rather than ambiguous.

## Audio/Product Insights

- Preserve approximately 1 Mohm input impedance for passive guitar pickups. Verify the complete input network at audio frequencies, including ESD parts and jack wiring.
- Design analog headroom from worst-case guitar/boost-pedal levels, not nominal pickup output. Measure clipping onset at every analog stage and at the Daisy ADC.
- Add input protection that does not add excessive capacitance or leakage: series resistance, rail clamps/low-capacitance protection, and defined behavior for hot-plug transients.
- Keep Wi-Fi burst current out of analog supply and ground paths. Validate with Wi-Fi disabled, idle, and continuous maximum-power transmit while monitoring audio FFT, VCC_Daisy, and VREF.
- Route off-board audio as shielded or twisted signal/return pairs. Avoid sharing return conductors with LED, SD, or ESP32 currents.
- Consider relay or analog-switch mute behavior during boot, reset, firmware update, and loss of Daisy clocks to avoid loud pops.
- Document maximum input/output level, input impedance, output impedance, latency, sample rate, bypass behavior, and expression-pedal electrical standard as product requirements.

## Manufacturing and Sourcing

- MPN coverage is 0%, so the lifecycle audit and full pin/rating verification are blocked.
- `IC1`-`IC4` contain the correct `TL072HIDR` text value but still need Manufacturer/MPN/LCSC properties and the correct TI datasheet URL.
- `C13`, `C15`, `C19`, and `C21` are nominal 100 uF polarized capacitors assigned to generic 1206 footprints. Select real parts before relying on those values.
- `FB1` needs an exact impedance curve, current rating, saturation behavior, and DCR suitable for ESP32 transmit peaks.
- `FB2` needs the same qualification for the complete Daisy/analog branch. Its connectivity from +5 V to VCC_Daisy is correct.
- Set the intended copper finish; the KiCad stack currently records `None`.
- Add assembly notes for socketed Daisy/ESP32 modules, SD sockets, off-board jacks, and polarity/orientation-sensitive parts.

## PDN Impedance

The idealized model sees 9 capacitors totaling 100.8 uF on VCC_Daisy, 3 totaling 100.2 uF on VCC_ESP32, 10.1 uF on each modeled 3.3 V rail, and only 100 nF directly on +5 V at U3. It predicts small anti-resonances near 5.0 MHz on VCC_Daisy and 7.9 MHz on VCC_ESP32. Treat these values as screening estimates: generic package parasitics, missing MPNs, MLCC DC bias, ferrite impedance, module capacitance, and PCB mounting inductance are not modeled accurately.

## Power Budget

The analyzer estimates about 120 mA for the six analog ICs on VCC_Daisy and 20 mA for U3 on +5 V. These are coarse defaults, not datasheet totals, and exclude Daisy/ESP32 peak demand, SD-card transients, LEDs, and external loads. Measure the complete board and size the 5 V source and FB1 for ESP32 transmit and SD write peaks with margin.

## Sleep Current Audit

The heuristic worst case is 69.84 mA and the state-aware estimate is about 0.59 mA, dominated by pull paths. This pedal is not presently optimized as a battery-sleep product, and module currents are not modeled. If battery operation is planned, define a power-state budget and add hardware rail shutdown rather than relying on MCU sleep alone.

## Bus Topology

The schematic uses UART between ESP32 and Daisy, SD/SPI-style buses for removable storage, two audio channels, and two expression channels. No graphical KiCad bus objects are used. Give SD clocks explicit source-series resistor footprints, keep each bus over continuous GND, and document which MCU owns each card and chip-select during reset.

## Test Coverage

Nineteen test points cover 13 nets, including +5 V, VCC_Daisy, VCC_ESP32, VREF, expression references, audio jack pads, and ground. Missing key coverage includes +3.3VA, +3.3VD, ESP-3.3V, VIN, UART, and SD SPI nets. Add compact accessible pads before fabrication.

## Assembly Complexity

The analyzer rates assembly complexity low at 26/100: 111 SMD and 16 THT placements, mostly 0805, 1206, and SOIC. Five 0201-class parts are the hard placements. The via moves substantially reduce assembly risk; the residual concerns are 13 pad/via overlaps, ambiguous module geometry, generic 100 uF footprints, missing fiducials, and absent exact assembly part numbers.

## BOM Optimization

The passive set is already modest: 10 resistor values, 7 capacitor values, and one single-use passive value. Do not consolidate values at the expense of filter response, LED current, VREF noise, or stability. The priority is exact MPN qualification and package consistency, not further line-count reduction.

## Thermal Analysis

The thermal analyzer ran at 40 C ambient but assessed zero parts because no component had both quantifiable dissipation and usable MPN/datasheet data. This is a review gap, not evidence of low temperature. Check the 5 V source path, FB1, module regulators, SD cards, and any enclosure hot spots during sustained Wi-Fi and DSP load.

## Gerber Verification

The only complete fabrication archive is dated 2026-08-10 and predates the present revision. It contains all four copper layers, mask, paste, silk, edge cuts, PTH, and NPTH files. Analyzer warnings about differing copper extents and 43% front-paste-to-front-copper flash count require CAM inspection but may be benign. Regenerate all outputs after the design is frozen.

## Analyzer Verification

### Analyses performed

- Current schematic analyzer: 113 components, 174 nets, 78 findings.
- Current full PCB analyzer with proximity: 119 footprints, 115 PCB nets, 620 track segments, 98 vias, 72 findings.
- Schematic/PCB cross-analysis: 8 findings.
- FCC Class B-oriented EMC risk analysis: 117 findings, static risk score 37/100.
- Thermal analyzer at 40 C ambient: ran but skipped modeling because no MPN/power data were available.
- Archived Gerber/drill analyzer: three warnings; package is dated 2026-08-10 and predates this revision.
- Raw schematic, PCB, project settings, Git delta, firmware architecture, and manufacturer product pages inspected.

### Not performed / limits

- Native KiCad ERC and DRC were not run because `kicad-cli` is unavailable. Run both in KiCad after refilling all zones.
- SPICE was not run because ngspice, LTspice, and Xyce are unavailable.
- No project datasheet cache exists and no exact MPNs are populated. Most pin-level and rating checks are consistency-only.
- Thermal analysis produced no component temperatures because dissipative part data are missing.
- Lifecycle analysis was not meaningful with 0% MPN coverage.
- Current Gerbers do not exist; the reviewed fabrication archive is stale.

## Priority Order

1. Create the exact ESP32 module footprint and all-layer antenna keepout/overhang.
2. Move the remaining `C29:1` and `U3:8` vias; place the `C18` and `C31` GND vias adjacent to, but outside, their pads.
3. Add exact Manufacturer/MPN/LCSC/datasheet properties for TL072HIDR and qualify `FB2` current/DCR.
4. Shorten VREF, keep it off the inner power layer where practical, and add adjacent GND return vias.
5. Correct `D1` current and select exact bulk capacitors/ferrite/LED/module MPNs.
6. Add explicit net classes, fiducials, test points, and off-board harness documentation.
7. Refill zones, run native ERC/DRC, regenerate Gerbers/CPL/BOM, and inspect in CAM.
8. Perform bench noise, clipping, startup-pop, Wi-Fi transmit, RSSI, and final-enclosure tests.

## Final Readiness Checklist

- [x] TL072H supply range and SOIC-8 pin mapping valid at nominal 5 V
- [x] All unused amplifier channels safely biased
- [x] One local 100 nF bypass per analog IC
- [x] GND plane adjacent to F.Cu
- [ ] Exact ESP32 footprint and enforced antenna keepout
- [ ] No unapproved open via-in-pad construction (`C29:1` and `U3:8` still open in analog section)
- [ ] VREF transitions have adjacent return vias and reduced route length
- [ ] LED currents recalculated
- [ ] Exact MPNs and ratings populated
- [ ] Native ERC/DRC clean after zone refill
- [ ] Fresh Gerber, drill, BOM, and CPL files inspected
- [ ] Wi-Fi-correlated audio noise and final-enclosure RF tests passed

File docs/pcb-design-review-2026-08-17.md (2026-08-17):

# ChimeraMultiFX Schematic and PCB Review

**Date:** 2026-08-17  
**Design:** `hardware/boards/daisyBoard.kicad_sch` + `hardware/boards/daisyBoard.kicad_pcb`  
**Purpose reviewed:** Daisy Seed audio DSP, ESP32 Wi-Fi/control/UI, UART bridge, dual-channel audio input/output conditioning, expression inputs, and SD interfaces.

## Verdict

**Not ready for another fabrication run without changes.** The architecture matches the project purpose, and the ESP32 power branch already includes useful conducted-noise isolation. The principal blockers are:

1. Four ordinary TL072 devices are powered from a nominal 5 V single supply, below TI's 7 V minimum total supply specification.
2. All four unused TL072 B channels are left floating.
3. Local op-amp decoupling is inadequate: six analog ICs share only a small number of bypass capacitors placed far from several ICs.
4. The ESP32 dev-board antenna is not represented by a physical footprint or enforced keepout. Inner-layer copper extends beneath the probable antenna area.
5. Audio and reference nets change layers without nearby ground-return vias, and the four-layer stack has a fragmented power plane—not GND—adjacent to top-layer signals.

These issues can plausibly cause clipping/distortion, instability, idle noise, Wi-Fi-correlated ticking/buzzing, degraded ESP32 range, and board-to-board variation.

## Review Basis

### Analyses run

- KiCad schematic analyzer
- Full PCB analyzer with trace proximity and connectivity analysis
- Schematic ↔ PCB cross-analysis
- FCC Class B-oriented EMC risk analysis
- Thermal analyzer
- Gerber/drill analyzer on the archived production ZIP
- Raw schematic, PCB, BOM, CPL, project settings, and README inspection
- Manufacturer web documentation checks for TL072 supply range and ESP32 layout guidance

Generated evidence is under `analysis/2026-08-17_1502/`.

### Not performed / limits

- Native KiCad ERC and DRC were not run because `kicad-cli` is unavailable. Run both in KiCad before fabrication.
- SPICE was not run because ngspice, LTspice, and Xyce are unavailable.
- Thermal analysis ran but returned no modelable dissipative parts; this is a modeling gap, not proof of zero thermal risk.
- Lifecycle analysis was not useful because MPN coverage is effectively 0% in the schematic.
- Full per-component manufacturer pinout verification was not possible because no datasheet cache exists and most exact MPNs are absent.
- The exact ESP32 dev-board variant and antenna orientation are not encoded in the design. Antenna location is inferred from the header pin mapping and common 30-pin ESP32 DevKit geometry.

## Design Summary

- 100 mm × 100 mm, four-layer, nominal 1.6 mm FR-4 board.
- Stack: F.Cu / In1.Cu power / In2.Cu GND / B.Cu.
- 106 schematic components and 174 schematic nets.
- Daisy Seed and ESP32 are socketed modules with breakout headers.
- The ESP32 receives 5 V through `FB1`; `C21` (100 µF), `C22` (100 nF), and `C23` (100 nF) provide branch capacitance.
- `U3` buffers the midrail `VREF`; TL072 and MCP6002 stages condition audio/expression signals.
- Audio I/O routes between the analog stages and Daisy headers; physical jacks appear intended to be off-board/wired through test-point pads.

## Critical and High-Priority Findings

### 1. TL072 supply voltage is outside its specified operating range — CRITICAL

**Evidence basis:** raw schematic/PCB verified + TI product specification.

`IC1`–`IC4` have pin 8 on `VCC_Daisy` and pin 4 on analog ground. `VCC_Daisy` is tied to the nominal +5 V source through `NT1`. TI lists the standard TL072 minimum total supply voltage as 7 V. Therefore, 5 V single-supply operation is outside the guaranteed range.

This is not merely an audio-quality optimization. The op amps may have poor output swing, common-mode violations, distortion, phase reversal-like behavior, startup problems, or large unit-to-unit variation.

**Required action:**

- Replace `IC1`–`IC4` with a pin-compatible dual op amp explicitly specified for 5 V single-supply operation.
- Select for low noise, adequate GBW/slew rate, input common-mode range that includes the actual signal range around `VREF`, output swing under the real load, and stability at unity gain.
- Alternatively, redesign the analog supply to meet TL072 requirements, but this is less attractive for a 5 V digital/audio module system.
- Recalculate all stage headroom after selecting the replacement.

Reference: TI TL072 product page states a 7 V minimum total supply voltage: https://www.ti.com/product/TL072

### 2. Four unused TL072 amplifier channels float — HIGH

**Evidence basis:** raw PCB pad-net verification.

For each of `IC1`, `IC2`, `IC3`, and `IC4`, pads 5, 6, and 7 are unconnected. These are the B-channel non-inverting input, inverting input, and output. Floating unused op-amp inputs can allow oscillation or rail chatter, injecting noise into the shared supply and substrate.

**Required action:** configure each unused channel as a defined unity-gain follower:

- non-inverting input → `VREF`
- output → inverting input
- do not short the output directly to a rail

Follow the selected replacement op amp's unused-channel guidance.

### 3. Analog IC bypassing is inadequate and physically remote — HIGH

**Evidence basis:** schematic inventory + deterministic PCB placement checks.

The `VCC_Daisy` rail supplies four TL072s and two MCP6002s. The board does not provide one local 100 nF capacitor per IC. Existing rail capacitors `C16` and `C17` are near the Daisy/power area rather than beside every audio IC. Automated geometry checks found:

- no decoupling capacitor within 10 mm of `U2`
- nearest candidate to `U1` approximately 9.3 mm away
- nearest candidates to `IC1` and `IC2` approximately 5 mm away

Some automatically associated capacitors are actually signal-path parts, so the true bypass situation is worse than the raw detector summary.

**Required action:**

- Add one 100 nF X7R capacitor directly between pins 8 and 4 of every dual op amp.
- Place each capacitor on the same side, ideally within 2–3 mm of the pins.
- Give the ground pad an adjacent via to the In2.Cu GND plane.
- Add local 1 µF near each analog cluster and retain suitable bulk capacitance at the rail entry.
- Keep each bypass loop compact; do not route power from the IC pin to a remote capacitor and back.

This change is one of the highest-value ways to reduce Wi-Fi-correlated audio noise through shared impedance.

### 4. ESP32 antenna keepout is absent and copper extends beneath the likely antenna — HIGH

**Evidence basis:** raw PCB/analyzer geometry + Espressif layout guidance; antenna orientation is inferred.

The ESP32 is modeled only as two 1×15 socket rows (`J1` and `J2`). There is no module body, courtyard, antenna graphic, or copper/routing keepout. The PCB analyzer found zero keepout zones.

The probable module envelope spans approximately x=64.23–89.63 mm and y=53.51–89.07 mm. The `ESP-3.3V` plane on In1.Cu spans x=65.755–91.255 mm and y=50.28–90.78 mm, while the In2.Cu GND plane spans essentially the entire board. Therefore, both inner copper layers extend under the probable antenna end.

Espressif recommends putting a module antenna beyond the baseboard edge. If that is impossible, the antenna should be at the edge with baseboard material/copper cleared around and below it; at least 15 mm housing clearance is recommended in all directions.

**Required action:**

1. Identify and document the exact ESP32 dev-board model and orientation.
2. Replace the two-header-only representation with a real module/dev-board footprint containing:
   - complete body outline
   - pin-1/orientation marker
   - antenna outline
   - component courtyard
   - all-layer copper/track/via keepout under and around the antenna
3. Prefer letting the antenna end overhang the carrier-board edge.
4. If it cannot overhang, cut the carrier board back beneath/beside the antenna per the exact module guidance.
5. Keep metal enclosure walls, displays, cables, jack bodies, and wiring at least 15 mm away where practical.
6. Add GND stitching at the keepout boundary, but never put stitching vias inside the antenna keepout.

Reference: Espressif ESP32 Hardware Design Guidelines, module positioning and antenna keepout: https://docs.espressif.com/projects/esp-hardware-design-guidelines/en/latest/esp32/pcb-layout-design.html

### 5. Layer stack/reference arrangement increases coupling risk — HIGH

**Evidence basis:** raw-file/analyzer-derived.

Top-layer traces see In1.Cu first, but In1.Cu is a collection of power regions (`VCC_Daisy`, `ESP-3.3V`, etc.), not a continuous ground plane. The continuous GND plane is In2.Cu, farther from F.Cu. This creates reference changes and gaps for fast ESP32/SD/UART edges and weakens electrostatic shielding of high-impedance analog traces.

Cross-analysis reported signals crossing power/GND plane discontinuities, including audio, UART, SD clock/data, `VREF`, and expression ADC nets. The EMC score of 13/100 is pessimistic and includes false-positive amplification, but the stackup concern itself is real.

**Preferred action for the next revision:**

- Change the stack to F.Cu / solid GND / power or GND / B.Cu.
- Keep layer 2 unbroken except for the intentional antenna keepout.
- Route power as polygons/traces on layer 3, with GND fill in unused space.
- Do not route signals across power-island boundaries on the adjacent reference layer.
- Keep SD clock/data together over one continuous reference and add source series damping where supported by the module/interface.

This matches Espressif's recommended four-layer ordering: top signal, layer-2 solid GND, layer-3 power/GND, bottom signal.

### 6. Audio and `VREF` layer transitions lack adjacent return vias — HIGH

**Evidence basis:** deterministic PCB topology.

Detected transitions without a GND stitching via within 1 mm include:

- `/AUDIO_IN_2`
- `/AUDIO_OUT_2`
- `Net-(U1B-+)`
- six transitions on `VREF`
- both expression ADC inputs
- multiple SD/UART-related nets

At audio frequency this is not a transmission-line problem, but the same copper can receive or rectify 2.4 GHz RF. A tight high-frequency return path reduces the loop area and RF-to-audio conversion.

**Required action:**

- Keep high-impedance analog nets on one layer wherever possible.
- Add a GND via immediately beside every unavoidable analog signal via.
- Avoid long `VREF` routing. Treat it as a low-noise analog supply/reference, not an ordinary signal.
- Add local `VREF` bypassing at each destination cluster if permitted by `U3` stability requirements.

## ESP32-to-Audio Noise Assessment

### What is already good

1. **Physical partitioning is directionally good.** The likely antenna is near the top board edge; primary audio stages are mostly around y≈99–141 mm, providing useful separation.
2. **ESP32 conducted-noise branch exists.** `FB1` separates +5 V from `VCC_ESP32`, with 100 µF and two 100 nF capacitors on the ESP branch.
3. **A solid In2.Cu GND fill exists.** The zone itself is filled as one region with about 86% area coverage.
4. **Input networks include RF attenuation.** Series resistance and shunt capacitance around the analog inputs reduce demodulation of RF at op-amp inputs.
5. **Analog and digital supply nets are named and intentionally partitioned.** This is a good basis for controlled return-current design.

### What still allows audible Wi-Fi artifacts

- Unsupported TL072 operation and floating channels can rectify or amplify RF and supply disturbances.
- Sparse/remote bypassing raises analog supply impedance during ESP32 current bursts.
- Copper beneath the antenna alters the antenna and drives stronger RF currents into the carrier board.
- The top-layer adjacent reference is fragmented power, encouraging larger return loops.
- Long audio traces (approximately 48–70 mm) and the 121 mm `VREF` route offer coupling area.
- Analog layer changes lack local GND-return vias.
- Exact ferrite current rating and DCR are unknown because `FB1` has no MPN. A “600 Ω @ 100 MHz” value alone is insufficient; verify current rating for ESP32 transmit peaks and low enough DCR to avoid brownout.

### Recommended priority order

1. Replace the TL072s and terminate unused channels.
2. Add local bypassing to every analog IC.
3. Create and enforce the exact ESP32 antenna keepout/overhang.
4. Put solid GND on layer 2 and move power partitioning to layer 3.
5. Shorten/re-route high-impedance audio and `VREF`; add return vias.
6. Move the ESP ferrite/bulk network closer to the module 5 V entry if the dev board's own local input capacitance is insufficient.
7. Verify `FB1` current rating/DCR and measure the ESP branch at maximum TX power.

## Schematic Function Review

### Architecture fit

The schematic broadly matches the project:

- ESP32 handles Wi-Fi/control and communicates with Daisy.
- Daisy receives and outputs two audio channels.
- Analog front-end stages buffer/filter/level-shift external audio around `VREF`.
- Expression inputs are buffered before Daisy ADC inputs.
- Separate SD interfaces and module breakout headers support development and expansion.

### Additional schematic concerns

- Exact module MPNs are absent for the ESP32 dev board and Daisy Seed. Connector pinout correctness cannot be guaranteed without these identities.
- `FB1`–`FB3` have impedance values but no current/DCR/voltage ratings or manufacturer parts.
- Rail-source warnings exist because power inputs rely on passive connectors/net ties without explicit `PWR_FLAG` declarations. Add correct flags after verifying the intended source direction so ERC becomes useful.
- Six jack symbols (`J6`–`J11`) exist in the schematic but not on the PCB. This appears intentional for off-board jacks, but mark them explicitly as excluded from board and document the wiring harness/pinout.
- MPN coverage is below the pre-fabrication threshold. Exact parts are essential for pinout, package, voltage rating, ferrite current, and assembly verification.

## PCB / EMC Findings

### Ground-plane finding triage

The connectivity analyzer reported “42 GND islands,” but the raw GND zone is filled as one In2.Cu region. The island count likely includes isolated pads/tracks or an analyzer limitation and should not be treated literally without native KiCad DRC and visual inspection.

The following residual findings remain valid despite that likely overcount:

- In1.Cu is fragmented power and is adjacent to F.Cu.
- Multiple signals cross adjacent-layer power boundaries.
- GND return vias are absent beside many signal transitions.
- Copper exists under the probable ESP32 antenna.

### Routing and DFM

- Routing is represented as complete by the parser, but native KiCad DRC must confirm no unconnected copper.
- Several 0.127 mm analog/power traces are narrow but electrically adequate for op-amp signals; they are less robust for fabrication and return-path control than 0.20–0.25 mm routing.
- `Card2` is approximately 0.32 mm from the board edge and `Card1` approximately 0.82 mm. Verify connector-body and fab edge-clearance requirements.
- No front-side fiducials were detected despite 76 SMD placements. Add three global fiducials for automated assembly.
- Test-point coverage is approximately 10%. Add accessible points for ESP 5 V, ESP 3.3 V, Daisy 5 V, analog 5 V, `VREF`, GND, UART, SD clocks, and each audio stage input/output.
- The analyzer flagged many untented via-in-pad cases. Many are likely ordinary zone/via overlaps rather than true component-pad vias; inspect native DRC and fabrication outputs before accepting the warning.

## Gerber / Manufacturing Review

The archived production package contains:

- all four copper layers
- front/back mask, paste, and silkscreen
- edge cuts
- PTH and NPTH drill files
- 100 mm × 100 mm outline

Warnings requiring visual CAM confirmation:

1. Copper/edge extents vary by roughly 6.6 mm × 6.3 mm. This may be legitimate copper not reaching the board edge, so treat it as a likely analyzer false positive unless CAM visualization shows actual layer offsets.
2. Front paste flashes are 43% of front copper flashes. Through-hole pads and non-pasted copper explain much of this, but compare every SMD BOM item against paste apertures before ordering.
3. Project stackup says copper finish “None.” Explicitly set/document the intended finish (for example ENIG or lead-free HASL) before generating final outputs.
4. Re-export Gerbers after all electrical/layout corrections; the present archive is not suitable for ordering because it predates the required fixes.

## Verification and Bring-Up Plan

After revision:

1. Run KiCad ERC and DRC with all zones refilled.
2. Re-run schematic, PCB, cross, EMC, thermal, and Gerber analysis.
3. Power from a current-limited bench supply with the ESP32 removed; verify +5 V, `VCC_Daisy`, and `VREF`.
4. Install Daisy only and measure audio noise/distortion.
5. Install ESP32 and compare audio FFT/noise floor with Wi-Fi disabled, idle, continuous transmit, and maximum TX power.
6. Probe `VCC_ESP32`, `VCC_Daisy`, and `VREF` simultaneously. Look for Wi-Fi burst-correlated ripple.
7. Near-field probe the antenna area, ESP power branch, `VREF`, op-amp inputs, and audio connector wiring.
8. Check ESP32 throughput/RSSI with the final enclosure, display, wiring, and jacks installed.
9. Perform an A/B test with the ESP32 antenna physically outside the carrier edge. A large noise or RSSI improvement confirms antenna/copper coupling.

## Final Readiness Checklist

- [ ] TL072 replacement selected and validated at 5 V
- [ ] Every unused op-amp channel terminated safely
- [ ] 100 nF local bypass at every analog IC
- [ ] Exact ESP32 and Daisy module identities documented
- [ ] ESP32 footprint includes antenna/body/courtyard/keepout
- [ ] No copper/tracks/vias under antenna on any layer
- [ ] Antenna overhang or exact vendor-approved edge clearance implemented
- [ ] Layer 2 changed to solid GND or equivalent continuous adjacent reference demonstrated
- [ ] Analog signal transitions have adjacent GND vias
- [ ] `VREF` routing shortened and locally bypassed
- [ ] Ferrite MPN/current/DCR verified
- [ ] Off-board jack/harness intent documented
- [ ] Native ERC/DRC clean after zone refill
- [ ] Final Gerbers visually inspected and regenerated
- [ ] Wi-Fi TX audio-noise test passed in the final enclosure

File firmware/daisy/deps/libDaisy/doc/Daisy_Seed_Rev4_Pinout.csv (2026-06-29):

 | SCH name | Pin name | ADC | Arduino D# | Arduino A# | I2C | UART | SPI
1 | USB_HS_ID | PB12 | x | D0 |  |  | UART5_RX | SPI2_NSS/I2S2_WS | TIM1_BKIN |  |  | DFSDM1_DATIN1 | USART3_CK | FDCAN2_RX | OTG_HS_ULPI_D5 | ETH_MII_TXD0/ETH_RMII_TXD0 | OTG_HS_ID | TIM1_BKIN_COMP12 |  | EVENTOUT
2 | SDMMC1_D3 | PC11 | x | D1 |  |  | USART3_RX/UART4_RX | SPI3_MISO/ I2S3_SDI | HRTIM_FLT2 | DFSDM1_DATIN5 |  |  |  | QUADSPI_BK2_NCS | SDMMC1_D3 | DCMI_D4 | EVENTOUT
3 | SDMMC1_D2 | PC10 | x | D2 |  |  | USART3_TX/UART4_TX | SPI3_SCK/I2S3_CK | HRTIM_EEV1 | DFSDM1_CKIN5 |  |  |  | QUADSPI_BK1_IO1 | SDMMC1_D2 | DCMI_D8 | LCD_R2 | EVENTOUT
4 | SDMMC1_D1 | PC9 | x | D3 |  | I2C3_SDA |  |  | MCO2 | TIM3_CH4 | TIM8_CH4 |  | I2S_CKIN | UART5_CTS | QUADSPI_BK1_IO0 | LCD_G3 | SWPMI_SUSPEND | SDMMC1_D1 | DCMI_D3 | LCD_B2 | EVENTOUT
5 | SDMMC1_D0 | PC8 | x | D4 |  |  |  |  | TRACED1 | HRTIM_CHB1 | TIM3_CH3 | TIM8_CH3 | USART6_CK | UART5_RTS/UART5_DE | FMC_NE2/FMC_NCE | SWPMI_RX | SDMMC1_D0 | DCMI_D2 | EVENTOUT
6 | SDMMC1_CMD | PD2 | x | D5 |  |  | UART5_RX |  | TRACED2 | TIM3_ETR |  | SDMMC1_CMD | DCMI_D11 | EVENTOUT
7 | SDMMC1_CK | PC12 | x | D6 |  |  | UART5_TX | SPI3_MOSI/I2S3_SDO | TRACED3 | HRTIM_EEV2 |  |  |  | SDMMC1_CK | DCMI_D9 | EVENTOUT
8 | SPI1_NSS | PG10 | x | D7 |  |  |  | SPI1_NSS/I2S1_WS | HRTIM_FLT5 |  | LCD_G3 |  | FMC_NE3 | DCMI_D2 | LCD_B2 | EVENTOUT
9 | SPI1_SCK | PG11 | x | D8 |  |  |  | SPI1_SCK/I2S1_CK | LPTIM1_IN2 | HRTIM_EEV4 |  | SPDIFRX1_IN1 | SDMMC2_D2 | ETH_MII_TX_EN/ETH_RMII_TX_ EN | DCMI_D3 | LCD_B3 | EVENTOUT
10 | SPI1_MISO | PB4 | x | D9 |  |  | UART7_TX | SPI1_MISO/I2S1_SDI/SPI3_MISO/I2S3_SDI/SPI2_NSS/I2S2_WS/SPI6_MISO | NJTRST | TIM16_BKIN | TIM3_CH1 | HRTIM_EEV6 |  |  |  |  | SDMMC2_D3 |  | EVENTOUT
11 | SPI1_MOSI | PB5 | x | D10 |  |  | UART5_RX | SPI1_MOSI/I2S1_SDO/SPI3_MOSI/I2S3_SDO/SPI6_MOSI | TIM17_BKIN | TIM3_CH2 | HRTIM_EEV7 |  |  |  |  |  | FDCAN2_RX | OTG_HS_ULPI_D7 | ETH_PPS_OUT | FMC_SDCKE1 | DCMI_D10 |  | EVENTOUT
12 | I2C1_SCL | PB8 | x | D11 |  | I2C1_SCL/I2C4_SCL | UART4_RX |  | TIM16_CH1 | TIM4_CH3 | DFSDM1_CKIN7 |  |  | SDMMC1_CKIN |  | FDCAN1_RX | SDMMC2_D4 | ETH_MII_TXD3 | SDMMC1_D4 | DCMI_D6 | LCD_B6 | EVENTOUT
13 | I2C1_SDA | PB9 | x | D12 |  | I2C1_SDA/I2C4_SDA | UART4_TX | SPI2_NSS/I2S2_WS | TIM17_CH1 | TIM4_CH4 | DFSDM1_DATIN7 |  |  |  | SDMMC1_CDIR |  | FDCAN1_TX | SDMMC2_D5 |  | SDMMC1_D5 | DCMI_D7 | LCD_B7 | EVENTOUT
14 | USART1_TX | PB6 | x | D13 |  | I2C1_SCL/I2C4_SCL | USART1_TX/LPUART1_TX/UART5_TX |  | TIM16_CH1N | TIM4_CH1 | HRTIM_EEV8 |  | CEC |  |  |  | FDCAN2_TX | QUADSPI_BK1_NCS | DFSDM1_DATIN5 | FMC_SDNE1 | DCMI_D5 |  | EVENTOUT
15 | USART1_RX | PB7 | x | D14 |  | I2C1_SDA/I2C4_SDA | USART1_RX/LPUART1_RX |  | TIM17_CH1N | TIM4_CH2 | HRTIM_EEV9 |  |  |  |  | FDCAN2_TXFD_MODE | DFSDM1_CKIN5 | FMC_NL | DCMI_VSYNC | EVENTOUT
16 | AUDIO IN L | x | x | NC |  |  |  |  | x
17 | AUDIO INR | x | x | NC |  |  |  |  | x
18 | AUDIO OUT L | x | x | NC |  |  |  |  | x
19 | AUDIO OUT R | x | x | NC |  |  |  |  | x
20 | AGND | x | x | NC
21 | 3v3A | x | x | NC |  |  |  |  | x
22 | ADC_INP10 | PC0 | ADC12_INP10 | D15 | A0 |  |  |  | DFSDM1_CKIN0 | DFSDM1_DATIN4 |  | OTG_HS_ULPI_STP | FMC_SDNWE | LCD_R5 | EVENTOUT
23 | ADC_INP15 | PA3 | ADC12_INP15 | D16 | A1 |  | USART2_RX |  | TIM2_CH4 | TIM5_CH4 | LPTIM5_OUT | TIM15_CH2 |  | LCD_B2 | OTG_HS_ULPI_D0 | ETH_MII_COL | LCD_B5 | EVENTOUT
24 | ADC_INP5 | PB1 | ADC12_INP5 | D17 | A2 |  |  |  | TIM1_CH3N | TIM3_CH4 | TIM8_CH3N | DFSDM1_DATIN1 | LCD_R6 | OTG_HS_ULPI_D2 | ETH_MII_RXD3 | LCD_G0 | EVENTOUT
25 | ADC_INP7 | PA7 | ADC12_INP7 | D18 | A3 |  |  | SPI1_MOSI/I2S1_SDO/SPI6_MOSI | TIM1_CH1N | TIM3_CH2 | TIM8_CH1N |  |  | TIM14_CH1 | ETH_MII_RX_DV/ETH_RMII_CRS _DV | FMC_SDNWE | EVENTOUT
26 | ADC_INP3 | PA6 | ADC12_INP3 | D19 | A4 |  |  | SPI1_MISO/I2S1_SDI/SPI6_MISO | TIM1_BKIN | TIM3_CH1 | TIM8_BKIN |  |  | TIM13_CH1 | TIM8_BKIN_COMP12 | MDIOS_MDC | TIM1_BKIN_COMP12 | DCMI_PIXCLK | LCD_G2 | EVENTOUT
27 | ADC_INP11 | PC1 | ADC123_INP11 | D20 | A5 |  |  | SPI2_MOSI/I2S2_SDO | TRACED0 | SAI1_D1 | DFSDM1_DATIN0 | DFSDM1_CKIN4 |  | SAI1_SD_A | SAI4_SD_A | SDMMC2_CK | SAI4_D1 | ETH_MDC | MDIOS_MDC | EVENTOUT
28 | ADC1_INP4 | PC4 | ADC12_INP4 | D21 | A6 |  |  |  | DFSDM1_CKIN2 | I2S1_MCK | SPDIFRX1_IN3 | ETH_MII_RXD0/ETH_RMII_RXD0 | FMC_SDNE0 | EVENTOUT
29 | DAC1_OUT2 | PA5 | ADC12_INP19 | D22 | A7 |  |  | SPI1_SCK/I2S1_CK/SPI6_SCK | D2PWREN | TIM2_CH1/TIM2_ETR | TIM8_CH1N |  |  | OTG_HS_ULPI_CK | LCD_R4 | EVENTOUT
30 | DAC1_OUT1 | PA4 | ADC12_INP18 | D23 | A8 |  |  | SPI1_NSS/I2S1_WS/SPI3_NSS/I2S3_WS/SPI6_NSS | D1PWREN | TIM5_ETR |  |  | USART2_CK |  | OTG_HS_SOF | DCMI_HSYNC | LCD_VSYNC | EVENTOUT
31 | SAI2_MCLK_B | PA1 | ADC1_INP17 | D24 | A9 |  | UART4_RX |  | TIM2_CH2 | TIM5_CH2 | LPTIM3_OUT | TIM15_CH1N | USART2_RTS/USART2_DE |  | QUADSPI_BK1_IO3 |  | ETH_MII_RX_CLK/ETH_RMII_RE F_CLK | LCD_R2 | EVENTOUT
32 | SAI2_SD_B | PA0 | ADC1_INP16 | D25 | A10 |  | UART4_TX |  | TIM2_CH1/TIM2_ETR | TIM5_CH1 | TIM8_ETR | TIM15_BKIN | USART2_CTS/USART2_NSS |  | SDMMC2_CMD |  | ETH_MII_CRS | EVENTOUT
33 | SAI2_SD_A | PD11 | x | D26 |  |  |  |  | LPTIM2_IN2 |  | USART3_CTS/USART3_NSS | QUADSPI_BK1_IO0 |  | FMC_A16 | EVENTOUT
34 | SAI2_FS_B | PG9 | x | D27 |  |  | USART6_RX | SPI1_MISO/I2S1_SDI |  |  | SPDIFRX1_IN4 | QUADSPI_BK2_IO2 |  | FMC_NE2/FMC_NCE | DCMI_VSYNC | EVENTOUT
35 | SAI2_SCK_B | PA2 | ADC12_INP14 | D28 | A11 |  | USART2_TX |  | TIM2_CH3 | TIM5_CH3 | LPTIM4_OUT | TIM15_CH1 |  |  | ETH_MDIO | MDIOS_MDIO | LCD_R1 | EVENTOUT
36 | USB_HS_D_- | PB14 | x | D29 |  |  | USART1_TX | SPI2_MISO/I2S2_SDI | TIM1_CH2N | TIM12_CH1 | TIM8_CH2N |  |  | DFSDM1_DATIN2 | USART3_RTS/USART3_DE | UART4_RTS/UART4_DE | SDMMC2_D0 | OTG_HS_DM | EVENTOUT
37 | USB_HS_D_+ | PB15 | x | D30 |  |  | USART1_RX | SPI2_MOSI/I2S2_SDO | RTC_REFIN | TIM1_CH3N | TIM12_CH2 | TIM8_CH3N |  |  | DFSDM1_CKIN2 | UART4_CTS | SDMMC2_D1 | OTG_HS_DP | EVENTOUT
38 | 3v3D | x | x |  |  |  |  |  | x
39 | VIN | x | x |  |  |  |  |  | x
40 | GND | x | x |  |  |  |  |  | x
INTERNAL
MEM1 | QSPI | QSPI FLASH 8MB
MEM2 | SDRAM | SDRAM 64MB
 | USB FS D+ | USB FS
 | USB FS D- | USB FS
 |  |  |  |  |  |  |  |  |  |  |  |  |  | LPUART1_TX
internal SAI | I2C2 |  |  |  |  |  |  |  |  |  |  |  |  | LPUART1_RX
 | SAI1_MCLK_A | PE2 |  |  |  |  |  |  |  |  |  |  |  | UART4_RX
 | SAI1_SD_B | PE3 |  |  |  |  |  |  |  |  |  |  |  | UART4_TX
 | SAI1_FS_A | PE4 |  |  |  |  |  |  |  |  |  |  |  | UART5_RX
 | SAI1_SCK_A | PE5 |  |  |  |  |  |  |  |  |  |  |  | UART5_TX
 | SAI1_SD_A | PE6 |  |  |  |  |  |  |  |  |  |  |  | UART7_RX
 |  |  |  |  |  |  |  |  |  |  |  |  |  | UART7_TX
 |  |  |  |  |  |  |  |  |  |  |  |  |  | USART1_RX
On Board User LED | PC7 |  |  | D31 |  |  |  |  |  |  |  |  |  | USART1_TX
On Board Test Point | PG14 |  |  |  |  |  |  |  |  |  |  |  |  | USART2_RX
 |  |  |  |  |  |  |  |  |  |  |  |  |  | USART2_TX
BOOT | PG3 |  |  |  |  |  |  |  |  |  |  |  |  | USART3_RX
QSPI GPIO |  |  |  |  |  |  |  |  |  |  |  |  |  | USART3_TX
IO0 | PF8 |  |  |  |  |  |  |  |  |  |  |  |  | USART6_RX
IO1 | PF9
IO2 | PF7
IO3 | PF6
CLK | PF10
NCS | PG6

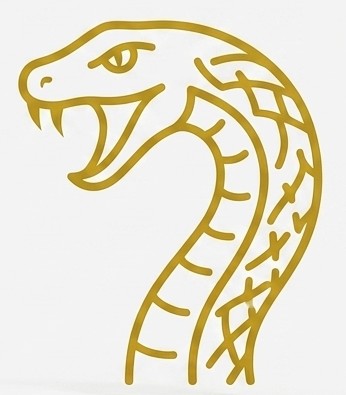
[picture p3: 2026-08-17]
hardware/boards/symbols/SNAKE.jpg

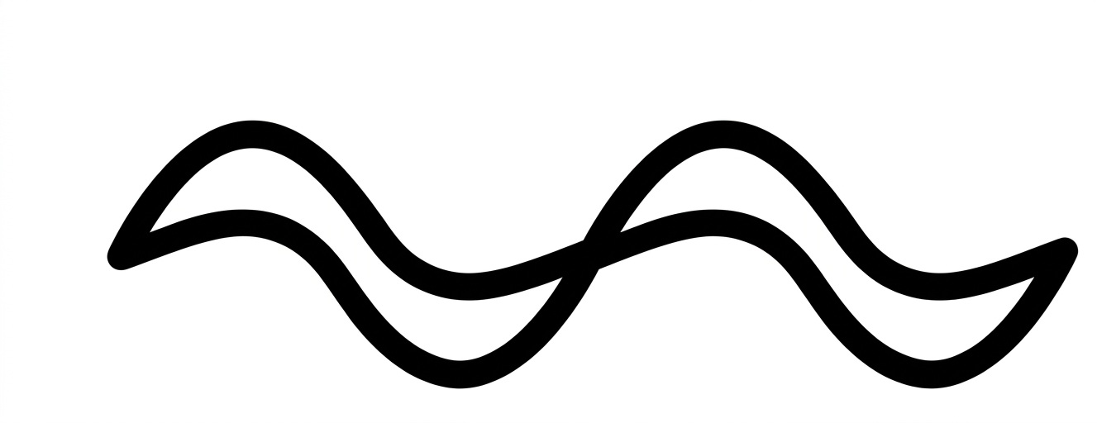
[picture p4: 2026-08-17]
hardware/boards/symbols/WAVE.jpg

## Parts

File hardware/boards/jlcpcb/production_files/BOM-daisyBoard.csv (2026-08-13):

Comment | Designator | Footprint | LCSC | Quantity
0.1uF | C14 | C_1206_3216Metric | C454377 | 1
100R | R11,R18,R21,R24,R7 | R_0805_2012Metric | C1015 | 5
100k | R12,R22,R23,R8 | R_0805_2012Metric | C25611 | 4
100n | C16,C17,C20,C22,C23 | C_1206_3216Metric | C24497 | 5
100p | C1,C4 | C_0805_2012Metric | C1790 | 2
100u | C13,C15,C19,C21 | C_1206_3216Metric | C15008 | 4
10K | R13,R14,R15,R16,R17,R25,R26,R27 | R_0805_2012Metric | C17414 | 8
10uF | C18 | C_1206_3216Metric | C13585 | 1
1M | R10,R2,R4,R6 | R_0805_2012Metric | C17514 | 4
1k | R1,R3 | R_0805_2012Metric | C17513 | 2
1n | C3,C6 | C_1206_3216Metric | C9196 | 2
1u | C11,C12,C2,C5,C8,C9 | C_1206_3216Metric | C1848 | 6
2M | R19,R20 | R_0805_2012Metric | C26112 | 2
2n2 | C10,C7 | C_1812_4532Metric | C2915766 | 2
600R @ 100MHz | FB1,FB2,FB3 | L_0805_2012Metric | C405006 | 3
Daisy PIN Breakout RIGHT | J16 | PinHeader_1x20_P2.54mm_Vertical | C124410 | 1
Daisy Pin Breakout LEFT | J15 | PinHeader_1x20_P2.54mm_Vertical | C124410 | 1
ESP32 Pin Breakout LEFT | J4 | PinHeader_1x15_P2.54mm_Vertical | C25503138 | 1
ESP32 Pin Breakout RIGHT | J3 | PinHeader_1x15_P2.54mm_Vertical | C25503138 | 1
LEFT Pin ROW | J1 | PinSocket_1x15_P2.54mm_Vertical | C2897378 | 1
LEFT Pin ROW Daisy | J13 | PinSocket_1x20_P2.54mm_Vertical | C53202183 | 1
MCP6002-xSN | U1,U2,U3 | SOIC-8_3.9x4.9mm_P1.27mm | C7377 | 3
RIGHT Pin ROW DAISY | J14 | PinSocket_1x20_P2.54mm_Vertical | C53202183 | 1
RIGHT Pin Row | J2 | PinSocket_1x15_P2.54mm_Vertical | C2897378 | 1
TL072 | IC1,IC2,IC3,IC4 | SOIC-8_3.9x4.9mm_P1.27mm | C1346149 | 4
Micro_SD_Card | J5 | microSD_HC_Molex_104031-0811 |  | 1
3R3 | R5 | R_0805_2012Metric |  | 1
3R3 | R9 | R_0805_2012Metric |  | 1
Micro_SD_Card | J12 | microSD_HC_Molex_104031-0811 |  | 1

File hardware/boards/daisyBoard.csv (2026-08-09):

Reference | Qty | Value | DNP | Exclude from BOM | Exclude from Board | Footprint | Datasheet
C1,C4 | 2 | 100p |  |  |  | Capacitor_SMD:C_1206_3216Metric
C2,C5,C8,C9,C11,C12 | 6 | 1u |  |  |  | Capacitor_SMD:C_1206_3216Metric
C3,C6 | 2 | 1n |  |  |  | Capacitor_SMD:C_1206_3216Metric
C7,C10 | 2 | 2n2 |  |  |  | Capacitor_SMD:C_1206_3216Metric
C13,C15,C19,C21 | 4 | 100u |  |  |  | Capacitor_SMD:C_1206_3216Metric
C14 | 1 | 0.1uF |  |  |  | Capacitor_SMD:C_1206_3216Metric
C16,C17,C20,C22,C23 | 5 | 100n |  |  |  | Capacitor_SMD:C_1206_3216Metric
C18 | 1 | 10uF |  |  |  | Capacitor_SMD:C_1206_3216Metric
FB1,FB2,FB3 | 3 | 600R @ 100MHz |  |  |  | Inductor_SMD:L_0805_2012Metric
IC1,IC2,IC3,IC4 | 4 | TL072 |  |  |  | Package_SO:SOIC-8_3.9x4.9mm_P1.27mm | http://www.ti.com/lit/ds/symlink/tl071.pdf
J1 | 1 | LEFT Pin ROW |  |  |  | Connector_PinSocket_2.54mm:PinSocket_1x15_P2.54mm_Vertical
J2 | 1 | RIGHT Pin Row |  |  |  | Connector_PinSocket_2.54mm:PinSocket_1x15_P2.54mm_Vertical
J3 | 1 | ESP32 Pin Breakout RIGHT |  |  |  | Connector_PinHeader_2.54mm:PinHeader_1x15_P2.54mm_Vertical
J4 | 1 | ESP32 Pin Breakout LEFT |  |  |  | Connector_PinHeader_2.54mm:PinHeader_1x15_P2.54mm_Vertical
J5,J12 | 2 | Micro_SD_Card |  |  |  | Connector_Card:microSD_HC_Molex_104031-0811 | https://www.we-online.com/components/products/datasheet/693072010801.pdf
J13 | 1 | LEFT Pin ROW Daisy |  |  |  | Connector_PinSocket_2.54mm:PinSocket_1x20_P2.54mm_Vertical
J14 | 1 | RIGHT Pin ROW DAISY |  |  |  | Connector_PinSocket_2.54mm:PinSocket_1x20_P2.54mm_Vertical
J15 | 1 | Daisy Pin Breakout LEFT |  |  |  | Connector_PinHeader_2.54mm:PinHeader_1x20_P2.54mm_Vertical
J16 | 1 | Daisy PIN Breakout RIGHT |  |  |  | Connector_PinHeader_2.54mm:PinHeader_1x20_P2.54mm_Vertical
R1,R3 | 2 | 1k |  |  |  | Resistor_SMD:R_0805_2012Metric
R2,R4,R6,R10 | 4 | 1M |  |  |  | Resistor_SMD:R_0805_2012Metric
R5,R9 | 2 | 3R3 |  |  |  | Resistor_SMD:R_0805_2012Metric
R7,R11,R18,R21,R24 | 5 | 100R |  |  |  | Resistor_SMD:R_0805_2012Metric
R8,R12,R22,R23 | 4 | 100k |  |  |  | Resistor_SMD:R_0805_2012Metric
R13,R14,R15,R16,R17,R25,R26,R27 | 8 | 10K |  |  |  | Resistor_SMD:R_0805_2012Metric
R19,R20 | 2 | 2M |  |  |  | Resistor_SMD:R_0805_2012Metric
TP1 | 1 | Global Ground - Functional |  |  |  | TestPoint:TestPoint_THTPad_D2.5mm_Drill1.2mm
TP2 | 1 | Global power 5V Input field - Functional |  |  |  | TestPoint:TestPoint_THTPad_D2.5mm_Drill1.2mm
TP5 | 1 | Reference voltage for the op amps - Probe |  |  |  | TestPoint:TestPoint_Pad_2.0x2.0mm
TP6 | 1 | Processed input power at 5V Daisy- Probe |  |  |  | TestPoint:TestPoint_Pad_2.0x2.0mm
TP7 | 1 | Jack Input 1 Pad |  |  |  | TestPoint:TestPoint_THTPad_D2.5mm_Drill1.2mm
TP8 | 1 | Jack Input 2 Pad |  |  |  | TestPoint:TestPoint_THTPad_D2.5mm_Drill1.2mm
TP9 | 1 | Jack Input 2 Pad GND |  |  |  | TestPoint:TestPoint_THTPad_D2.5mm_Drill1.2mm
TP10 | 1 | Jack Input 1 Pad GND |  |  |  | TestPoint:TestPoint_THTPad_D2.5mm_Drill1.2mm
TP11 | 1 | Jack Output 2 Signal Pad |  |  |  | TestPoint:TestPoint_THTPad_D2.5mm_Drill1.2mm
TP12 | 1 | Jack Output 2 GND Pad |  |  |  | TestPoint:TestPoint_THTPad_D2.5mm_Drill1.2mm
TP15 | 1 | Jack Output 1 GND Pad |  |  |  | TestPoint:TestPoint_THTPad_D2.5mm_Drill1.2mm
TP16 | 1 | Jack Output 1 Signal Pad |  |  |  | TestPoint:TestPoint_THTPad_D2.5mm_Drill1.2mm
TP17 | 1 | Exp Jack Input 1 Pad GND |  |  |  | TestPoint:TestPoint_THTPad_D2.5mm_Drill1.2mm
TP18 | 1 | Exp Jack Input 1 Signal |  |  |  | TestPoint:TestPoint_THTPad_D2.5mm_Drill1.2mm
TP19 | 1 | Exp Jack Input 2 GND |  |  |  | TestPoint:TestPoint_THTPad_D2.5mm_Drill1.2mm
TP20 | 1 | Exp Jack Input 2 Signal |  |  |  | TestPoint:TestPoint_THTPad_D2.5mm_Drill1.2mm
TP21 | 1 | Processed input power at 5V ESP32 - Probe |  |  |  | TestPoint:TestPoint_Pad_2.0x2.0mm
TP22 | 1 | EXPR REF 1 |  |  |  | TestPoint:TestPoint_THTPad_D2.5mm_Drill1.2mm
TP23 | 1 | EXPR Ref 2 |  |  |  | TestPoint:TestPoint_THTPad_D2.5mm_Drill1.2mm
U1,U2,U3 | 3 | MCP6002-xSN |  |  |  | Package_SO:SOIC-8_3.9x4.9mm_P1.27mm | http://ww1.microchip.com/downloads/en/DeviceDoc/21733j.pdf

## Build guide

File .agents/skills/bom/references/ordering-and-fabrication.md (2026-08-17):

# Ordering & Fabrication Reference

## Distributor Order Formats

Each distributor has a paste/upload format for adding parts to a cart. The `bom_manager.py order` subcommand generates these automatically.

### DigiKey — Bulk Add to Cart

Paste into the bulk-add box at [digikey.com/ordering/shoppingcart](https://www.digikey.com/ordering/shoppingcart):

```
3, 490-10698-1-ND, C1/C2/C5
1, ESP32-S3-WROOM-1-N16R8-ND, U1
5, 311-10.0KCRCT-ND, R1/R2/R3/R4/R5
```

Format: `quantity, DigiKey_PN, customer_reference` — comma or tab delimited, one line per part.

**FastAdd URL** — programmatic cart building:
```
https://www.digikey.com/classic/ordering/fastadd.aspx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
```
GET supports ~1700 chars; POST supports 400+ parts.

**BOM Manager** — [digikey.com/en/resources/bom-manager](https://www.digikey.com/en/resources/bom-manager). Upload CSV/XLS/XLSX, map columns interactively. Accepts both DigiKey PNs and MPNs.

### Mouser — Part List Import

Paste at [mouser.com/tools/part-list-import.aspx](https://www.mouser.com/tools/part-list-import.aspx) (requires login):

```
595-TPS63020DSJR|10
81-GRM155R71C104KA8D|3
```

Format: `Mouser_PN|quantity` — pipe delimited.

**FORTE BOM Tool** — [mouser.com/bomtool](https://www.mouser.com/bomtool/). Upload CSV/XLS/XLSX, auto-matching MPNs.

### LCSC / JLCPCB Assembly

Upload at [lcsc.com/bom](https://www.lcsc.com/bom) (max 800 lines):

```csv
Comment,Designator,Footprint,LCSC Part #
100nF,"C1,C2,C5",0402,C14663
ESP32-S3-WROOM-1,U1,ESP32-S3-WROOM-1,C2913202
```

Same format for JLCPCB assembly orders — see the `jlcpcb` skill.

### Newark / Farnell / element14

Paste at [newark.com/quick-order](https://www.newark.com/quick-order):

```
94AK6875,3
82AC7952,10
```

Format: `Newark_OrderCode, quantity` — comma or tab delimited.

**BOM Upload** — [newark.com/bom-upload-landing](https://www.newark.com/bom-upload-landing). Accepts both Newark PNs and MPNs.

### Arrow (Volume / Price Comparison)

**BOM Tool** — [arrow.com/en/bom-management-tool](https://www.arrow.com/en/bom-management-tool). Upload CSV/XLS/XLSX (max 3,000 lines). Accepts MPNs, Arrow PNs. Can purchase or request quotes directly.

### Quick Reference

| Distributor | Format | Delimiter |
|---|---|---|
| DigiKey | `qty, DK_PN, ref` | comma/tab |
| Mouser | `Mouser_PN\|qty` | pipe |
| LCSC | `Comment,Designator,Footprint,LCSC Part #` | comma |
| Newark | `OrderCode, qty` | comma/tab |
| Arrow | file upload only | — |

---

## Gerber & Stencil Export

### Required Gerber Layers

Export from KiCad: Fabrication > Plot (format: Gerber, coordinate format: 4.6 mm).

| KiCad Layer | Description |
|---|---|
| F.Cu / B.Cu | Front/back copper |
| F.Paste / B.Paste | Solder paste (stencil) |
| F.SilkS / B.SilkS | Silkscreen |
| F.Mask / B.Mask | Solder mask |
| Edge.Cuts | Board outline |

Also generate Excellon drill files (Fabrication > Generate Drill Files). Zip all together for upload.

### CPL (Component Placement List)

Export from KiCad: Fabrication > Generate Placement Files (CSV format).

| Column | Description |
|---|---|
| `Designator` | Reference designator |
| `Mid X` / `Mid Y` | Component center (mm) |
| `Rotation` | Angle (degrees) |
| `Layer` | `Top` or `Bottom` |

Both JLCPCB and PCBWay use the same CPL format.

### Stencil Ordering

Order a **framed stencil** alongside bare prototype PCBs (~$7 from JLCPCB). Generated from F.Paste gerber layer. Rigid frame for use with a stencil jig.

---

## Cost Summary Template

```
BOM Summary — Project: <name>
===================================
Unique parts:     23
Total components:  87
DNP:               3

Prototype (1 board, DigiKey):
  Parts:       $45.23
  PCB (JLC):   ~$7 (5 boards min, 2-layer)
  Stencil:     ~$7 (framed, from JLC)
  Shipping:    ~$5-12
  Total:       ~$64-71

Production (100 boards, JLCPCB assembled):
  Parts/board:     $8.50
  PCB fab/board:    $0.80
  Assembly/board:   $2.50
  Extended fees:    $0.09/board (3 extended x $3 / 100)
  Per board:        ~$11.89
  Total (100):      ~$1,189
```

Always query current pricing via the `digikey`, `mouser`, and `lcsc` skills — prices change frequently.

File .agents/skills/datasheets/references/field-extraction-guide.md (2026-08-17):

# Field Extraction Guide

How to find each schema field in a typical datasheet PDF. Covers section naming conventions by vendor, what language to look for, and common mistakes.

The extraction workflow starts with `datasheet_page_selector.py` identifying the relevant pages (pin table, absolute maximum ratings, operating conditions, electrical characteristics, application circuit). This guide describes what to look for once you have those pages.

Use `null` for any field the datasheet does not specify. Do not guess or interpolate.

---

## Page Selection Overview

The page selector uses a three-strategy approach:

1. **TOC present** — scans the first 1–3 pages for section headings with page numbers. TOC references to "Pin Configuration", "Absolute Maximum Ratings", "Electrical Characteristics", and "Typical Application" are automatically resolved to target pages.
2. **No TOC** — scores every page by keyword density. Pages containing "absolute maximum", "pin configuration", "electrical characteristics", and "application circuit" score highest.
3. **No pdftotext** — returns pages 1–5 plus evenly distributed pages.

Default page budget: 10 pages (15 for microcontrollers, FPGAs, SoCs). Always includes page 1 and the last page.

---

## Vendor Section Naming

Different manufacturers use different section titles for the same content. Recognizing these saves time.

### Texas Instruments (TI)

| Content | Typical Section |
|---|---|
| Pin table | §6 "Pin Configuration and Functions" or §7 |
| Absolute maximum ratings | §7.1 "Absolute Maximum Ratings" |
| Operating conditions | §7.2 "ESD Ratings" / §7.3 "Recommended Operating Conditions" |
| Electrical characteristics | §7.4 or §7.5 "Electrical Characteristics" |
| Application circuit | §9 "Application and Implementation" → §9.1 "Typical Application" |

### STMicroelectronics (ST)

| Content | Typical Section |
|---|---|
| Pin table | §4 "Pinouts" or "Pin definition" |
| Absolute maximum ratings | §5 or §6 "Absolute maximum ratings" |
| Operating conditions | Embedded in electrical characteristics table |
| Electrical characteristics | §6 or §7 "Electrical characteristics" |
| Application circuit | "Application schematics" or "Reference circuit" (late in doc) |

### NXP / Freescale

| Content | Typical Section |
|---|---|
| Pin table | §7 "Pinning information" |
| Absolute maximum ratings | §11 "Limiting values" or "Absolute maximum ratings" |
| Operating conditions | §12 "Recommended operating conditions" or "Characteristics" |
| Electrical characteristics | §12 "Characteristics" |
| Application circuit | "Application diagram" or "Typical application circuit" |

### Microchip / Atmel

| Content | Typical Section |
|---|---|
| Pin table | "Pin Diagrams" + "Pin Description" (separate pages) |
| Absolute maximum ratings | "Absolute Maximum Ratings*" (with footnote) |
| Operating conditions | Embedded in DC characteristics tables |
| Electrical characteristics | "DC Characteristics" / "AC Characteristics" |
| Application circuit | "Typical Application Circuit" or "Demo Board Schematic" |

### Espressif

| Content | Typical Section |
|---|---|
| Pin table | Pin description tables in early sections (often §2 or §3) |
| Absolute maximum ratings | "Absolute Maximum Ratings" — often a brief table |
| Operating conditions | "Recommended Operating Conditions" |
| Electrical characteristics | Peripheral-specific tables scattered through the document |
| Application circuit | "Typical Application Schematic" or hardware design guidelines doc |

Note: Espressif often separates the datasheet (pin specs, electrical) from a hardware design guidelines document (application circuit, decoupling). If the PDF is the datasheet only, the application circuit section may be minimal.

### Analog Devices / Maxim

| Content | Typical Section |
|---|---|
| Pin table | "PIN CONFIGURATION" + "PIN DESCRIPTION" (often on page 2) |
| Absolute maximum ratings | "ABSOLUTE MAXIMUM RATINGS" (all caps, early in doc) |
| Operating conditions | Part of main specifications table |
| Electrical characteristics | "ELECTRICAL CHARACTERISTICS" or "DC Specifications" |
| Application circuit | "Typical Application Circuit" or "Applications Information" |

---

## Field-by-Field Guidance

### `mpn`

Use the exact part number from the datasheet's title or ordering information page, including the package and temperature suffix (e.g., `TPS61023DRLR`, not `TPS61023`). Omit marketing names or family names.

### `manufacturer`

Use the company name as it appears on the datasheet header. For acquisitions (e.g., Maxim by Analog Devices, Linear Technology by Analog Devices), use the name on the datasheet being read, not the current parent company.

### `category`

Match to the category list in extraction-schema.md. The category determines which scoring rules apply. If the part spans categories (e.g., a PMIC with multiple regulators), use the primary function.

### `package`

Format: `"<package_name> (<pin_count>-pin)"`. Examples: `"TSSOP-14 (14-pin)"`, `"SOT-23-6 (6-pin)"`, `"QFN-32 (32-pin, 5x5mm)"`. The pin count is used to validate coverage in the scorer. Found in the ordering information or package outline section.

### `pins[].number`

Copy exactly as printed in the pin description table: `"1"`, `"2"`, `"A1"`, `"EP"` (exposed pad). Do not renumber or convert to integers.

### `pins[].name`

Copy from the pin name column. When the datasheet shows alternative names (e.g., `SW/VOUT`), use the primary name for the operating mode you're documenting.

### `pins[].type`

Map from the datasheet's function column:

| Datasheet language | Schema type |
|---|---|
| VDD, VCC, VIN, VSUPPLY | `power` |
| GND, AGND, PGND, VSS | `ground` |
| FB, COMP, VREF, VSET (analog) | `analog` |
| EN, SCL, SDA, TX, RX, CS, INT, ALERT | `digital` |
| NC, No Connect | `no_connect` |
| SDA/SCL (bidirectional bus), IO | `bidirectional` |

### `pins[].voltage_abs_max`

Found in the pin description table (individual pin limits) or the absolute maximum ratings table. Individual pin limits take precedence over the global abs max. Common traps:

- **SW pin on switching regulators**: often has a lower abs max than VIN (e.g., VIN = 6V, SW = 6V, but separate footnote limits SW to 5.6V during startup)
- **ESD clamp pins**: may have a negative lower limit (e.g., `-0.3V to 6V`) — store only the upper limit in this field
- **I/O pins on MCUs**: often have a separate `VDDIO` limit distinct from the main supply

### `pins[].threshold_high_v` / `pins[].threshold_low_v`

Look in the electrical characteristics table under "Logic Input Threshold" or similar. Common naming:

- `V_IH`, `VIH`, `V_IL`, `VIL` — standard logic threshold names
- `V_EN(H)`, `V_EN(L)` — enable pin thresholds (device-specific naming)
- `V_IN(H)`, `V_IN(L)` — input pin thresholds

Trap: Do not confuse `V_IH` (recommended minimum high input) with `V_OL`/`V_OH` (output levels). The extraction wants input thresholds — what the pin recognizes as logic high or low.

Trap: Some datasheets list thresholds as fractions of VDD (e.g., "0.7 × VDD"). Record the fraction notation in the description, and store the absolute value calculated at the nominal operating voltage in the field.

### `pins[].required_external`

This is the most important field for design review automation. Sources:

1. Pin description "External components required" columns
2. Application circuit notes referencing specific pins
3. Recommended operating conditions footnotes (e.g., "Bypass VIN to GND with 100nF")
4. Absolute maximum ratings notes (e.g., "Place clamp diode on boot pin for inductive loads")

Write in the datasheet's own language when possible. Include values and placement constraints where specified.

---

### `absolute_maximum_ratings`

Found in the "Absolute Maximum Ratings" table, usually near the front of the datasheet. Key naming conventions:

| Datasheet label | Suggested key | Unit |
|---|---|---|
| VIN(max), Input Voltage | `vin_max_v` | V |
| VOUT(max), Output Voltage | `vout_max_v` | V |
| TJ(max), Junction Temperature | `junction_temp_max_c` | °C |
| TSTG, Storage Temperature | `storage_temp_min_c`, `storage_temp_max_c` | °C |
| ESD (HBM) | `esd_hbm_v` | V |
| ESD (CDM) | `esd_cdm_v` | V |

Trap: **Absolute maximum ratings are not operating conditions**. Exposing a pin to its abs max continuously will shorten device lifetime. Do not use abs max values as operating targets.

Trap: Some datasheets list separate abs max for each pin in the pin description table. Capture those in `pins[].voltage_abs_max`, not here. The top-level absolute_maximum_ratings covers supply voltage and temperature.

---

### `recommended_operating_conditions`

Found in the "Recommended Operating Conditions" or "Operating Conditions" table. This is the range where the device is guaranteed to perform per the electrical characteristics.

Key traps:

- **VIN vs VOUT vs VDD**: multi-rail devices may have separate operating ranges for each supply. Use the most restrictive or the primary input.
- **Temperature grades**: datasheets may show industrial (−40 to +85°C) and commercial (0 to +70°C) variants in the same table. Extract for the grade you are using.
- **"Conditions" column**: some electrical characteristics tables embed operating conditions as conditions on specific rows. These are test conditions for that row, not the device operating range.

---

### `electrical_characteristics.*`

Found in the "Electrical Characteristics" table. This table is usually organized with columns: Parameter, Min, Typ, Max, Unit, Test Conditions.

Which value to record:

- Use **Typ** for `vref_v`, `switching_frequency_khz` (nominal specs)
- Use **Max** for threshold voltages, quiescent current limits, propagation delay
- Use **Min** for `dropout_mv` (worst case is what matters for design margin)
- Use **Typ** for SPICE model parameters (behavioral accuracy)

Key field lookup:

| Field | What to find in the table |
|---|---|
| `vref_v` | Reference voltage or feedback threshold; labeled "VREF", "VFB", "Feedback Voltage" |
| `switching_frequency_khz` | "Oscillator frequency", "Switching frequency", "fSW" |
| `quiescent_current_ua` | "IQ", "IDD (quiescent)", "Supply current (no load)" — exclude gate drive and switching losses |
| `dropout_mv` | "Dropout voltage" at rated output current; labeled "VDO", "VIN-VOUT" |
| `gbw_hz` | "Gain Bandwidth Product", "GBW", "Unity gain frequency" |
| `slew_vus` | "Slew rate", "SR" — use the slower of rising/falling |
| `prop_delay_ns` | "Propagation delay", "tPD" — use the worst case across all measurement conditions |
| `clamping_voltage_v` | "VC", "Clamping voltage" at the specified IEC 61000-4-2 test current |

Trap: **Gain Bandwidth vs Unity Gain Bandwidth**. Some datasheets list both. Use the unity-gain stable bandwidth for `gbw_hz`.

Trap: **Quiescent vs active supply current**. Record the quiescent (no-load, static) current, not the active switching current, unless the datasheet doesn't distinguish.

---

### `application_circuit.*`

Found in the typical application circuit section. This section often spans multiple pages with a reference schematic, a component table, and layout notes.

**topology**: Look for how the circuit is described in the section title or opening sentence: "boost converter", "buck converter", "buck-boost", "flyback", "SEPIC", "inverting buck-boost", "LDO". Use lowercase.

**inductor_recommended**: Usually in a "Inductor Selection" subsection or a component table. Capture value, saturation current requirement, and DCR guidance if given.

**input_cap_recommended / output_cap_recommended**: Labeled in the component table or application notes. Common format: `"10µF, X5R or X7R, 10V rating"`. Include dielectric and voltage rating if specified.

**vout_formula**: Look for a formula in the "Setting the Output Voltage" or "Programming Output Voltage" section. Record the exact formula; do not simplify.

**notes**: Capture layout-critical guidance: copper pour requirements, trace width recommendations, component placement distance constraints, feedback routing warnings.

Trap: Some datasheets have minimal application sections and instead reference an application note (SLVA XXXX, AN1234, etc.). If the datasheet itself has no circuit recommendations, set `application_circuit` to null and note the reference in `extraction_metadata`.

---

### `spice_specs.*`

SPICE specs come from the same electrical characteristics table as `electrical_characteristics`. The difference is that `spice_specs` uses the exact key names from `spice_part_library.py` for direct model generation.

For opamps: `gbw_hz`, `slew_vus`, `vos_mv`, `aol_db`, `rin_ohms` come from the electrical characteristics table. `supply_min`/`supply_max` come from recommended operating conditions. `rro`/`rri` come from the features list or the output swing specification (if the output swings within a few mV of the rail, `rro = true`).

For regulators: `vref` comes from the reference voltage spec. `dropout_mv` from the dropout table. `iq_ua` from quiescent current. `iout_max_ma` from the maximum output current rating.

---

## Common Mistakes

**Mixing abs max with operating conditions.** The schematic verifier compares pin voltages against `voltage_abs_max`; an incorrectly low value will generate false positives.

**Using the wrong table row.** Electrical characteristics tables often have multiple rows for the same parameter under different test conditions (temperature range, load current, VIN). Pick the row matching typical operation, not the extreme test condition.

**Leaving required fields null when the datasheet has them.** If the pin table has a voltage limit column, populate `voltage_abs_max` for every pin — not just the ones that look interesting. The scorer deducts points for name-only pins.

**Truncating the MPN.** `TPS61023` and `TPS61023DRLR` may have different specs (package parasitics, temperature grade). Extract from the correct datasheet and record the full part number.

**Copying from a different variant's table.** Datasheets often cover a family. Check that the table row applies to the specific part number you are extracting.

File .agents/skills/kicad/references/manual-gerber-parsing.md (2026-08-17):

# Manual Gerber & Drill Parsing (Script Fallback)

When `analyze_gerbers.py` fails (unsupported format, newer KiCad version, non-KiCad gerbers), fall back to direct file parsing. Gerber and Excellon are simpler line-oriented text formats compared to KiCad S-expressions, but correct coordinate handling and X2 attribute state tracking require care.

## Table of Contents

1. [When to Use Manual Parsing](#when-to-use-manual-parsing)
2. [Gerber RS-274X Parsing](#gerber-rs-274x-parsing)
3. [X2 Attribute Extraction](#x2-attribute-extraction)
4. [Excellon Drill Parsing](#excellon-drill-parsing)
5. [Layer Identification](#layer-identification)
6. [Gerber Job File (.gbrjob)](#gerber-job-file-gbrjob)
7. [Cross-Reference with KiCad Source](#cross-reference-with-kicad-source)
8. [Validation Methodology](#validation-methodology)

---

## When to Use Manual Parsing

Use manual parsing when:
- `analyze_gerbers.py` crashes or returns unexpected results
- The gerbers are from non-KiCad EDA tools (Altium, Eagle, OrCAD)
- You need to validate script output against raw file data
- You need specific data the script doesn't extract (arc geometry, region vertices)
- The file is partially corrupt but still readable

Always try the script first — it handles coordinate conversion, X2 attribute state tracking, drill classification, and layer identification automatically.

---

## Gerber RS-274X Parsing

Gerber files are line-oriented text. Each file represents one PCB layer. Parse line by line maintaining state.

### Step 1: Extract Format and Units

These appear in the file header and are required for coordinate conversion.

```python
import re

with open(gerber_path) as f:
    content = f.read()
    lines = content.splitlines()

# Format specification: %FSLAX46Y46*%
fs_match = re.search(r'%FS([LT])([AI])X(\d)(\d)Y(\d)(\d)\*%', content)
if fs_match:
    x_decimals = int(fs_match.group(4))  # typically 6
    y_decimals = int(fs_match.group(6))

# Units: %MOMM*% or %MOIN*%
units_mm = '%MOMM*%' in content  # True for mm, False for inch
```

**Coordinate conversion:** Raw integer coordinates divide by `10^decimals` to get the value in the declared unit. With `%FSLAX46Y46*%` and `%MOMM*%`:
- `X150000000` = 150000000 / 10^6 = 150.0 mm
- `X76687500Y-150250000` = (76.6875 mm, -150.25 mm)

With `%MOIN*%`, divide by 10^decimals to get inches, then multiply by 25.4 for mm.

### Step 2: Parse Aperture Definitions

Apertures define the "pen" shape for drawing and flashing. They appear in the header as `%AD` commands.

```python
apertures = {}
for line in lines:
    s = line.strip()
    m = re.match(r'%AD(D\d+)(\w+),?([^*]*)\*%', s)
    if m:
        d_code = m.group(1)      # e.g., "D10"
        shape = m.group(2)       # C (circle), R (rect), O (obround), RoundRect (macro)
        params = m.group(3)      # e.g., "0.200000" or "1.000000X0.600000"
        apertures[d_code] = {'shape': shape, 'params': params}
```

**Aperture shapes and dimensions:**

| Shape | Params | Dimension extraction |
|---|---|---|
| `C` | `diameter` | Trace width = diameter |
| `R` | `widthXheight` | Pad size (split on X) |
| `O` | `widthXheight` | Obround pad size |
| `RoundRect` | `radiusX...coords...` | Complex — 2x radius is a lower bound |

For trace width analysis, focus on `C` (circle) apertures used with D01 (draw) commands — the diameter directly gives the trace width.

### Step 3: Stateful Command Parsing

Parse draw/flash/move operations maintaining current position and aperture state.

```python
current_aperture = None
current_x, current_y = 0, 0
flash_count = 0
draw_count = 0
region_count = 0
x_min = y_min = float('inf')
x_max = y_max = float('-inf')

x_div = 10 ** x_decimals
y_div = 10 ** y_decimals

for line in lines:
    s = line.strip()

    # Aperture select: D10*
    m = re.match(r'D(\d+)\*$', s)
    if m and int(m.group(1)) >= 10:
        current_aperture = f"D{m.group(1)}"
        continue

    # Region start/end
    if s == 'G36*':
        region_count += 1

    # Coordinate + operation
    m = re.match(r'(?:X(-?\d+))?(?:Y(-?\d+))?D0([123])\*', s)
    if m:
        if m.group(1):
            current_x = int(m.group(1)) / x_div
        if m.group(2):
            current_y = int(m.group(2)) / y_div
        op = int(m.group(3))

        if op == 3:  # Flash
            flash_count += 1
        elif op == 1:  # Draw
            draw_count += 1
        # op == 2 is move (pen up)

        # Track extents
        x_min = min(x_min, current_x)
        x_max = max(x_max, current_x)
        y_min = min(y_min, current_y)
        y_max = max(y_max, current_y)
```

**Key operation codes:**

| Code | Name | Action |
|---|---|---|
| `D01` | Draw | Draw line from current position to coordinates |
| `D02` | Move | Move without drawing (pen up) |
| `D03` | Flash | Stamp aperture shape at coordinates |
| `D10+` | Select | Switch to aperture N |
| `G01` | Linear | Straight line interpolation (default) |
| `G02` | CW arc | Clockwise circular arc |
| `G03` | CCW arc | Counter-clockwise circular arc |
| `G36` | Region start | Begin filled polygon |
| `G37` | Region end | End filled polygon |
| `G75` | Multi-quadrant | Arc mode (usually set once) |

**Coordinates may omit X or Y** if unchanged from the previous command. `Y-150250000D03*` means flash at (previous_X, -150.25).

### Step 4: Arc Parsing

Arc commands use I/J offsets from the current position to the arc center:

```
G75*                         ; Multi-quadrant mode
G02*                         ; Clockwise
X160000000Y100000000I5000000J0D01*  ; Arc to (160,100) with center offset (5,0)
```

- `I` and `J` are offsets (not absolute coords) — arc center = (current_x + I, current_y + J)
- Arc radius = sqrt(I^2 + J^2)
- Arc appears in Edge.Cuts for rounded board corners and occasionally in copper for curved traces

For board outline analysis, you mainly need arc endpoints for bounding box calculation. For precise geometry (closed polygon verification), compute the arc center and trace the path.

---

## X2 Attribute Extraction

X2 attributes are the most valuable data in modern gerber files. They come in three levels: file (`TF`), aperture (`TA`), and object (`TO`).

### File Attributes (TF) — All KiCad Versions

File attributes identify the layer and provide metadata. **KiCad 5 and 6+ both emit them**, but in different syntax:

```python
x2_attrs = {}

# Modern format (KiCad 6+): %TF.Key,Value*%
for m in re.finditer(r'%TF\.(\w+),([^*]*)\*%', content):
    x2_attrs[m.group(1)] = m.group(2)

# KiCad 5 comment format: G04 #@! TF.Key,Value*
for m in re.finditer(r'G04 #@! TF\.(\w+),([^*]*)\*', content):
    key = m.group(1)
    if key not in x2_attrs:  # Don't override modern format
        x2_attrs[key] = m.group(2)
```

**Critical TF attributes:**

| Attribute | Example | Purpose |
|---|---|---|
| `FileFunction` | `Copper,L1,Top` | Layer identification |
| `FilePolarity` | `Positive` / `Negative` | Mask layers are Negative |
| `GenerationSoftware` | `KiCad,Pcbnew,9.0.7` | KiCad version detection |
| `CreationDate` | `2026-02-24T01:31:01-08:00` | File generation timestamp |
| `SameCoordinates` | `Original` | Alignment verification |

### Aperture Attributes (TA) — KiCad 6+ Only

Aperture attributes classify aperture function. They appear **before** the `%AD` definition they apply to:

```python
pending_aper_function = None
aperture_functions = {}  # D-code -> function string

for line in lines:
    s = line.strip()

    # TA sets pending function
    m = re.match(r'%TA\.AperFunction,([^*]*)\*%', s)
    if m:
        pending_aper_function = m.group(1)
        continue

    # AD consumes pending function
    m = re.match(r'%AD(D\d+)', s)
    if m and pending_aper_function:
        aperture_functions[m.group(1)] = pending_aper_function
        continue

    # TD clears pending
    if s == '%TD*%':
        pending_aper_function = None
```

**TA.AperFunction values and meaning:**

| AperFunction | Description | Analysis use |
|---|---|---|
| `SMDPad,CuDef` | SMD pad copper | Count unique apertures = pad variety |
| `ViaPad` | Via pad | Usually 1-2 apertures; count flashes = via count |
| `ComponentPad` | Through-hole pad | Cross-ref with drill ComponentDrill |
| `HeatsinkPad` | Thermal/exposed pad | QFN ground slugs, power pads |
| `Conductor` | Traces | Circle diameter = trace width |
| `NonConductor` | Non-electrical | Fiducials, logos |

**KiCad 5 has no TA attributes.** Classify heuristically: small circle apertures used with D01 = traces; apertures used with D03 only = pads.

### Object Attributes (TO) — KiCad 6+ Only

Object attributes map copper features to schematic components and nets. This is the most powerful X2 feature — it enables reverse-engineering the netlist from gerber files alone.

**TO attributes are stateful:** once set, they apply to all subsequent D01/D02/D03 commands until cleared by `%TD*%` or overwritten by a new `%TO*%`.

```python
current_component = None
current_net = None
components = {}       # ref -> {pads, nets}
pin_mappings = []     # [{ref, pin, pin_name, net}]

for line in lines:
    s = line.strip()

    # TO.C sets current component reference
    m = re.match(r'%TO\.C,([^*]*)\*%', s)
    if m:
        current_component = m.group(1)
        if current_component not in components:
            components[current_component] = {'pads': 0, 'nets': set()}
        continue

    # TO.N sets current net name
    m = re.match(r'%TO\.N,([^*]*)\*%', s)
    if m:
        current_net = m.group(1)
        if current_component and current_component in components:
            components[current_component]['nets'].add(current_net)
        continue

    # TO.P records pin mapping (ref, pin_number, pin_name)
    m = re.match(r'%TO\.P,([^,]*),([^,*]*)(?:,([^*]*))?\*%', s)
    if m:
        pin_mappings.append({
            'ref': m.group(1),
            'pin': m.group(2),
            'pin_name': m.group(3) or '',
            'net': current_net or '',
        })
        continue

    # TD clears all object attributes
    if s == '%TD*%':
        current_component = None
        current_net = None
        continue

    # On flash (D03), count pad for current component
    if 'D03' in s and current_component and current_component in components:
        components[current_component]['pads'] += 1
```

**Important state management rules:**
- `%TO.C,R1*%` sets component context — all subsequent features belong to R1
- `%TO.N,GND*%` sets net context — often changes within the same component
- `%TO.P,R1,1,PAD*%` records a pin mapping — pin 1 of R1 is named "PAD"
- `%TD*%` clears ALL TO attributes — resets component, net, and pin
- The same component may appear multiple times (e.g., different pads on different draw passes)
- TO attributes appear on **copper layers only** — mask/paste/silk layers don't have them

**KiCad 5 has no TO attributes.** Component and net mapping requires the `.kicad_pcb` source file.

### Component Side Detection

Components that appear only on B.Cu (back copper) TO.C attributes but not F.Cu are back-side components. Those appearing on F.Cu are front-side. Through-hole components appear on both layers (front pad + back pad).

```python
front_components = set()
back_components = set()

for gerber in parsed_gerbers:
    layer = gerber['layer_type']
    to_components = gerber.get('x2_objects', {}).get('component_refs', [])
    if layer == 'F.Cu':
        front_components.update(to_components)
    elif layer == 'B.Cu':
        back_components.update(to_components)

back_only = back_components - front_components  # True back-side SMD
```

---

## Excellon Drill Parsing

Drill files have a header (tool definitions) and body (drill hits). The coordinate format differs significantly between KiCad versions.

### Step 1: Detect Units

```python
units_mm = True  # default assumption

for line in lines:
    s = line.strip()
    if 'METRIC' in s:
        units_mm = True
    elif 'INCH' in s:
        units_mm = False
```

### Step 2: Parse Tool Definitions

Tools are defined in the header section (before `%` end-of-header marker):

```python
tools = {}
pending_aper_function = None

for line in lines:
    s = line.strip()

    # Per-tool TA function (KiCad 6+ only)
    ta_match = re.match(r';\s*#@!\s*TA\.AperFunction,(.*)', s)
    if ta_match:
        pending_aper_function = ta_match.group(1).strip()
        continue

    # Tool definition: T1C0.300 or T01C0.800000
    m = re.match(r'T(\d+)C([\d.]+)', s)
    if m:
        tool_num = int(m.group(1))
        diameter = float(m.group(2))
        if not units_mm:
            diameter *= 25.4  # Convert inches to mm
        tools[tool_num] = {
            'diameter_mm': diameter,
            'function': pending_aper_function,  # None for KiCad 5
            'hits': [],
        }
        pending_aper_function = None
```

### Step 3: Parse Drill Hits

```python
current_tool = None

for line in lines:
    s = line.strip()

    # Tool select: T1 or T01
    m = re.match(r'^T(\d+)$', s)
    if m:
        current_tool = int(m.group(1))
        continue

    # Drill hit coordinate
    m = re.match(r'X(-?[\d.]+)Y(-?[\d.]+)', s)
    if m and current_tool:
        x, y = float(m.group(1)), float(m.group(2))
        if not units_mm:
            x, y = x * 25.4, y * 25.4
        elif x > 1000:  # METRIC integer microns (no decimal point)
            x, y = x / 1000, y / 1000
        tools[current_tool]['hits'].append((x, y))
```

### KiCad 5 vs 6+ Coordinate Differences

| Aspect | KiCad 5 | KiCad 6+ |
|---|---|---|
| Units header | `INCH` | `METRIC` or `METRIC,TZ` |
| Format hint | `; FORMAT={-:-/ absolute / inch / decimal}` | `; FORMAT={-:-/ absolute / metric / decimal}` |
| Coordinate format | Decimal inches: `X1.3875Y-2.77` | Integer microns: `X150000Y100000` |
| Decimal point | Present | Absent |
| Negative Y values | Common (inverted Y-axis) | Rare |
| Tool size | Inches: `T1C0.0157` (=0.399mm) | mm: `T1C0.300` |

**Reliable detection:** If coordinates contain a decimal point (`.`), they're decimal inches/mm. If they're large integers without decimals, divide by 1000 for mm.

### Drill Classification

**With TA.AperFunction (KiCad 6+):**
- `Plated,PTH,ViaDrill` — via
- `Plated,PTH,ComponentDrill` — through-hole component pad
- `NonPlated,NPTH,BoardEdge` — board cutout or slot

**Without TA.AperFunction (KiCad 5) — use heuristics:**

| Diameter | Likely function |
|---|---|
| <= 0.45mm | Via drill |
| 0.45 - 1.3mm | Component hole (THT pads) |
| > 1.3mm | Mounting hole or connector |
| NPTH file | All holes are mounting/mechanical |

**Layer span** from `TF.FileFunction`:
- `Plated,1,2,PTH` — 2-layer board, holes span layers 1-2
- `Plated,1,4,PTH` — 4-layer board, through-holes span all layers

---

## Layer Identification

### From X2 FileFunction (Preferred)

Parse `TF.FileFunction` from file attributes (works for both KiCad 5 and 6+):

```python
file_function = x2_attrs.get('FileFunction', '').lower()

if 'copper' in file_function:
    if 'top' in file_function:
        layer = 'F.Cu'
    elif 'bot' in file_function:
        layer = 'B.Cu'
    else:
        # Inner copper: "copper,l2,inr" → In1.Cu
        m = re.search(r'copper,l(\d+),inr', file_function)
        if m:
            abs_pos = int(m.group(1))
            inner_idx = abs_pos - 1  # L2→In1, L3→In2
            layer = f'In{inner_idx}.Cu'
```

**Inner layer naming pitfall:** X2 FileFunction uses absolute copper position (`L2` = second copper layer from top), but KiCad names inner layers starting from `In1.Cu`. For a 4-layer board: L1=F.Cu, **L2=In1.Cu**, **L3=In2.Cu**, L4=B.Cu. Subtract 1 from the absolute position to get the KiCad inner layer index.

### From Filename Patterns (Fallback)

When X2 attributes are missing or unparseable:

```python
name = filename.lower()

# Check inner layers first (avoid false positive on "in" substring)
m = re.search(r'in(\d+)[_.]cu', name)
if m:
    layer = f'In{m.group(1)}.Cu'

# Outer layers and non-copper
patterns = {
    'f_cu': 'F.Cu', 'f.cu': 'F.Cu',
    'b_cu': 'B.Cu', 'b.cu': 'B.Cu',
    'f_mask': 'F.Mask', 'b_mask': 'B.Mask',
    'f_paste': 'F.Paste', 'b_paste': 'B.Paste',
    'f_silkscreen': 'F.SilkS', 'f_silks': 'F.SilkS',
    'b_silkscreen': 'B.SilkS', 'b_silks': 'B.SilkS',
    'edge_cuts': 'Edge.Cuts',
}
```

**KiCad version from filenames:** `_SilkS` suffix = KiCad 5, `_Silkscreen` suffix = KiCad 6+.

### Protel Extension Mapping

Some fabs prefer Protel-style extensions:

| Extension | Layer |
|---|---|
| `.GTL` | F.Cu |
| `.GBL` | B.Cu |
| `.G1`-`.G4` | Inner layers |
| `.GTS` | F.Mask |
| `.GBS` | B.Mask |
| `.GTP` | F.Paste |
| `.GBP` | B.Paste |
| `.GTO` | F.SilkS |
| `.GBO` | B.SilkS |
| `.GKO` / `.GM1` | Edge.Cuts |

---

## Gerber Job File (.gbrjob)

**KiCad 6+ only.** JSON format with board metadata. Parse before individual gerbers — it's the most reliable source for board dimensions, layer count, and design rules.

```python
import json

with open(gbrjob_path) as f:
    job = json.load(f)

specs = job.get('GeneralSpecs', {})
size = specs.get('Size', {})
board_width = size.get('X', 0)   # mm
board_height = size.get('Y', 0)  # mm
layer_count = specs.get('LayerNumber', 0)
thickness = specs.get('BoardThickness', 0)  # mm

# Design rules
for rule in job.get('DesignRules', []):
    min_trace = rule.get('MinLineWidth', 0)     # mm
    min_clearance = rule.get('PadToPad', 0)      # mm

# Expected files list
for f_attr in job.get('FilesAttributes', []):
    path = f_attr.get('Path', '')
    function = f_attr.get('FileFunction', '')
    polarity = f_attr.get('FilePolarity', '')

# Stackup
for layer in job.get('MaterialStackup', []):
    layer_type = layer.get('Type', '')      # "Copper" or "Dielectric"
    thickness = layer.get('Thickness', 0)   # mm (0.035 = 1oz copper)
    material = layer.get('Material', '')    # "FR4", etc.
```

**When .gbrjob is absent (KiCad 5):**
- Board dimensions: compute from Edge.Cuts gerber coordinate bounding box
- Layer count: count inner copper gerber files + 2 (F.Cu + B.Cu), or check drill `TF.FileFunction` layer span
- Design rules: not available from gerber files; check `.kicad_pro` source

---

## Cross-Reference with KiCad Source

### What Can Be Verified from Gerbers Alone

| Check | KiCad 5 | KiCad 6+ |
|---|---|---|
| Board dimensions | Edge.Cuts extents | .gbrjob or Edge.Cuts |
| Layer count | Inner copper file count + drill span | .gbrjob or same |
| Layer completeness | Filename matching | .gbrjob expected list |
| Drill sizes | Tool definitions | Same + TA classification |
| Trace widths | Aperture dimensions (heuristic) | TA.AperFunction Conductor |
| Component list | Not available | TO.C attributes |
| Net list | Not available | TO.N attributes |
| Pin-to-net map | Not available | TO.P + TO.N attributes |
| Pad count | Flash count (heuristic) | TA.AperFunction classification |

### Cross-Reference Against PCB Analyzer

When both gerber and PCB analysis outputs are available:

1. **Component count**: Gerber `component_analysis.total_unique` vs PCB footprint count. Difference = non-electrical footprints (logos, mounting holes without copper)
2. **Net count**: Gerber `net_analysis.total_unique` vs PCB net count. Should match closely (gerber may miss nets that are zone-only with no pads/traces)
3. **Via count**: Gerber drill `vias.count` vs PCB via count
4. **Trace widths**: Gerber `trace_widths.unique_widths_mm` vs PCB track width distribution
5. **Board dimensions**: Gerber `board_dimensions` vs PCB Edge.Cuts extents
6. **THT vs SMD ratio**: Gerber `pad_summary.smd_ratio` vs PCB component `attr` counts

### Cross-Reference Against Schematic Analyzer

1. **Component list**: Gerber component refs (from TO.C) should be a subset of schematic BOM. Missing = DNP components or power symbols (expected). Extra = fabrication-only components
2. **Net names**: Named nets from gerber TO.N should match schematic net names. Unnamed gerber nets (`Net-(...)`) are auto-generated and may differ
3. **Pin count per component**: Gerber pad count should match schematic pin count for each reference designator

---

## Validation Methodology

### Quick Sanity Checks

1. **File count**: Typical 2-layer board = 9 gerbers + 2 drills + 1 gbrjob. 4-layer = 11 gerbers + 2 drills + 1 gbrjob
2. **Coordinate alignment**: All `TF.SameCoordinates` values should be `Original`
3. **Date consistency**: All `TF.CreationDate` values should match — different dates = risk of misaligned files
4. **Software consistency**: All `TF.GenerationSoftware` should match
5. **Solder mask polarity**: Must be `Negative` (`TF.FilePolarity,Negative`)

### Layer Consistency Checks

- **Paste <= Mask**: F.Paste flash count should be <= F.Mask flash count (no paste on vias)
- **Empty B.Paste**: Correct for single-side assembly
- **B.Cu flashes ~ via count**: Back copper pad flashes should roughly equal PTH via drill count (plus any back-side SMD)
- **Copper balance**: F.Cu and B.Cu draw counts within ~10x of each other (extreme imbalance = potential warping)
- **Edge.Cuts non-empty**: Must have draws (board outline)

### Drill Verification

- **PTH minimum**: >= 0.2mm (JLCPCB standard)
- **NPTH minimum**: >= 0.5mm (JLCPCB standard)
- **Via count cross-check**: Drill via count should match B.Cu via pad flash count (when TA.AperFunction is available)
- **Layer span**: Drill `TF.FileFunction` span should match copper layer count (e.g., `Plated,1,4,PTH` for 4-layer)

### Known Edge Cases

- **KiCad 5 mask/paste uses regions**: D03 flash count may be 0 on mask/paste layers — count G36/G37 region pairs instead
- **Large B.Mask file size**: Normal when back has ground plane — mask must define tenting pattern over entire zone fill
- **Negative Y in KiCad 5 drills**: KiCad 5 used inverted Y-axis for drill coordinates
- **Non-KiCad gerbers**: May lack X2 attributes entirely; rely on filename patterns for layer identification
- **Merged drill files**: Some workflows produce a single drill file with both PTH and NPTH — check `TF.FileFunction` for `MixedPlating`
- **Protel extensions**: Some fabs require `.GTL`/`.GBL` extensions instead of KiCad's `-F_Cu.gbr` naming
- **Inner layer L2 != In2.Cu**: X2 FileFunction uses absolute position (L2 = second physical copper), KiCad uses inner-relative naming (In1.Cu = first inner copper). L2 maps to In1.Cu, L3 maps to In2.Cu

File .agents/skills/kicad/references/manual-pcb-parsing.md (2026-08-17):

# Manual PCB Parsing (Script Fallback)

When `analyze_pcb.py` fails (unsupported format, newer KiCad version, corrupted file), fall back to direct file parsing. This is more expensive (reading raw S-expressions) but always works as long as the file is valid KiCad.

## Table of Contents

1. [When to Use Manual Parsing](#when-to-use-manual-parsing)
2. [Performance: Line-by-Line Parsing](#performance-line-by-line-parsing)
3. [Net Extraction](#net-extraction)
4. [Footprint Extraction](#footprint-extraction)
5. [Track and Via Extraction](#track-and-via-extraction)
6. [Zone Extraction](#zone-extraction)
7. [Board Outline](#board-outline)
8. [Connectivity Analysis](#connectivity-analysis)
9. [KiCad 5 Legacy Format](#kicad-5-legacy-format)
10. [Validation Methodology](#validation-methodology)

---

## When to Use Manual Parsing

Use manual parsing when:
- `analyze_pcb.py` crashes or returns unexpected results on a file you know is valid
- The PCB is from a KiCad version newer than the script supports
- You need to validate script output against raw file data
- You need to extract data the script doesn't provide (e.g., specific filled_polygon vertices)
- The file is partially corrupt but still readable

Always try the script first — it handles coordinate transforms, via classification, connectivity analysis, and 25+ analysis stages automatically.

---

## Performance: Line-by-Line Parsing

KiCad PCB files can be 20K-70K+ lines, with zones containing thousands of polygon vertices. **Never use full-content regex with `re.DOTALL` on the entire file** — it causes catastrophic backtracking on large files. Use line-by-line state-machine parsing instead for top-level extraction. `re.DOTALL` is acceptable on small, pre-extracted blocks (e.g., a single footprint or pad block) where the input size is bounded.

### Buffer Accumulation Pattern

For simple blocks (segments, vias):

```python
import re

with open(pcb_file) as f:
    lines = f.readlines()

segments = []
buf = None
for line in lines:
    if '\t(segment' in line:
        buf = line
    elif buf:
        buf += line
        if line.strip() == ')':
            m_s = re.search(r'\(start\s+([\d.-]+)\s+([\d.-]+)\)', buf)
            m_e = re.search(r'\(end\s+([\d.-]+)\s+([\d.-]+)\)', buf)
            m_w = re.search(r'\(width\s+([\d.]+)\)', buf)
            m_l = re.search(r'\(layer\s+"([^"]+)"\)', buf)
            # KiCad ≤9: (net 7), KiCad 10: (net "NetName")
            m_n = re.search(r'\(net\s+(\d+)\)', buf) or re.search(r'\(net\s+"([^"]+)"\)', buf)
            if all([m_s, m_e, m_w, m_l, m_n]):
                net_val = m_n.group(1)
                segments.append({
                    'sx': float(m_s.group(1)), 'sy': float(m_s.group(2)),
                    'ex': float(m_e.group(1)), 'ey': float(m_e.group(2)),
                    'w': float(m_w.group(1)), 'layer': m_l.group(1),
                    'net': int(net_val) if net_val.isdigit() else net_val
                })
            buf = None
```

### Depth-Tracked Parsing

For nested blocks (footprints, zones), track parenthesis depth:

```python
footprints = {}
current_fp = None
fp_text = []
depth = 0

for line in lines:
    if line.startswith('\t(footprint '):
        current_fp = True
        fp_text = [line]
        depth = line.count('(') - line.count(')')
    elif current_fp:
        fp_text.append(line)
        depth += line.count('(') - line.count(')')
        if depth <= 0:
            block = ''.join(fp_text)
            # Extract data from the bounded block (regex is safe here)
            m_ref = re.search(r'\(property\s+"Reference"\s+"([^"]+)"', block)
            m_at = re.search(r'\n\t\t\(at\s+([\d.-]+)\s+([\d.-]+)(?:\s+([\d.-]+))?\)', block)
            if m_ref and m_at:
                ref = m_ref.group(1)
                footprints[ref] = {
                    'x': float(m_at.group(1)),
                    'y': float(m_at.group(2)),
                    'angle': float(m_at.group(3)) if m_at.group(3) else 0,
                    'block': block
                }
            current_fp = None
```

---

## Net Extraction

**KiCad ≤9:** Net declarations are single-line entries near the top of the file:

```python
nets = {}
for line in lines:
    m = re.match(r'\s*\(net\s+(\d+)\s+"([^"]*)"\)', line)
    if m:
        nets[int(m.group(1))] = m.group(2)
```

Net 0 is always the unconnected net (empty name).

**KiCad 10:** No net declarations section. Nets are referenced by name string directly in pads, tracks, vias, and zones. Collect unique net names from those elements instead.

Power nets typically have names like `GND`, `+3V3`, `+5V`, `VBUS`.

---

## Footprint Extraction

After extracting footprint blocks with depth-tracking (see above), extract pads from each block:

```python
for ref, fp in footprints.items():
    # KiCad ≤9: (net 5 "+3V3"), KiCad 10: (net "+3V3")
    pads = re.findall(
        r'\(pad\s+"([^"]+)"\s+(\w+)\s+\w+\s+'
        r'\(at\s+([\d.-]+)\s+([\d.-]+).*?\)'
        r'\s+\(size\s+([\d.-]+)\s+([\d.-]+)\).*?'
        r'\(net\s+(?:(\d+)\s+)?"([^"]*)"',
        fp['block'], re.DOTALL)
    # pads: list of (pad_num, type, rel_x, rel_y, size_w, size_h, net_id_or_empty, net_name)
```

### Absolute Pad Positions

Pad coordinates are relative to footprint origin. Transform to board coordinates:

```python
import math

def pad_to_absolute(fp_x, fp_y, fp_angle_deg, pad_rx, pad_ry):
    rad = math.radians(-fp_angle_deg)  # KiCad: CW positive in layout
    abs_x = fp_x + pad_rx * math.cos(rad) - pad_ry * math.sin(rad)
    abs_y = fp_y + pad_rx * math.sin(rad) + pad_ry * math.cos(rad)
    return abs_x, abs_y
```

### Key Footprint Fields

| Field | Where | Purpose |
|---|---|---|
| `(property "Reference" "U1")` | Footprint block | Component designator |
| `(property "Value" "STM32F407")` | Footprint block | Component value |
| `(at X Y ANGLE)` | 2nd-level child | Position and rotation |
| `(layer "F.Cu")` | 1st-level child | Board side (F.Cu = front, B.Cu = back) |
| `(attr smd)` | 1st-level child | SMD vs through-hole |
| `(path "/uuid")` | 1st-level child | Link to schematic symbol |
| `(sheetname "Power")` | 1st-level child | Source schematic sheet |
| `(pad ...)` | Nested children | Pads with net assignments |

### Courtyard Extraction

Courtyard shapes define the component's keep-out area:

```python
# From footprint block:
crtyd_lines = re.findall(
    r'\(fp_(?:line|rect)\s+\(start\s+([\d.-]+)\s+([\d.-]+)\)\s+'
    r'\(end\s+([\d.-]+)\s+([\d.-]+)\).*?'
    r'\(layer\s+"[FB]\.CrtYd"\)',
    fp['block'], re.DOTALL)
```

Build a bounding box from all courtyard primitives, then transform to absolute coordinates.

---

## Track and Via Extraction

### Tracks (Segments)

See the buffer accumulation pattern above. KiCad 7+ also has `(arc ...)` blocks with `(start)`, `(mid)`, `(end)` for curved tracks.

For arc length calculation:
```python
import math

def arc_length(sx, sy, mx, my, ex, ey):
    """Calculate arc length from start/mid/end points."""
    # Find circle center from 3 points
    ax, ay = sx - mx, sy - my
    bx, by = ex - mx, ey - my
    D = 2 * (ax * by - ay * bx)
    if abs(D) < 1e-10:
        return math.hypot(ex - sx, ey - sy)  # Degenerate: straight line
    ux = (by * (ax*ax + ay*ay) - ay * (bx*bx + by*by)) / D + mx
    uy = (ax * (bx*bx + by*by) - bx * (ax*ax + ay*ay)) / D + my
    radius = math.hypot(sx - ux, sy - uy)
    # Angle subtended
    a1 = math.atan2(sy - uy, sx - ux)
    a2 = math.atan2(ey - uy, ex - ux)
    angle = abs(a2 - a1)
    if angle > math.pi:
        angle = 2 * math.pi - angle
    return radius * angle
```

### Vias

```python
vias = []
buf = None
for line in lines:
    if '\t(via' in line and '(via' in line:
        buf = line
    elif buf:
        buf += line
        if line.strip() == ')':
            m_at = re.search(r'\(at\s+([\d.-]+)\s+([\d.-]+)\)', buf)
            m_sz = re.search(r'\(size\s+([\d.]+)\)', buf)
            m_dr = re.search(r'\(drill\s+([\d.]+)\)', buf)
            m_ly = re.search(r'\(layers\s+"([^"]+)"\s+"([^"]+)"\)', buf)
            # KiCad ≤9: (net 5) with numeric ID; KiCad 10: (net "NetName") with string
            m_n = re.search(r'\(net\s+(\d+)\)', buf)
            m_nn = re.search(r'\(net\s+"([^"]+)"\)', buf)
            via_type = 'through'
            if '(via blind' in buf: via_type = 'blind'
            elif '(via buried' in buf: via_type = 'buried'
            elif '(via micro' in buf: via_type = 'micro'
            if all([m_at, m_sz, m_dr]) and (m_n or m_nn):
                vias.append({
                    'x': float(m_at.group(1)), 'y': float(m_at.group(2)),
                    'size': float(m_sz.group(1)), 'drill': float(m_dr.group(1)),
                    'type': via_type,
                    'layers': (m_ly.group(1), m_ly.group(2)) if m_ly else ('F.Cu', 'B.Cu'),
                    'net': int(m_n.group(1)) if m_n else m_nn.group(1),
                    'free': '(free yes)' in buf
                })
            buf = None
```

### Annular Ring Check

```python
for via in vias:
    annular_ring = (via['size'] - via['drill']) / 2
    if annular_ring < 0.125:  # JLCPCB standard minimum
        print(f"Annular ring violation: {annular_ring:.3f}mm at ({via['x']}, {via['y']})")
```

---

## Zone Extraction

Zones are the trickiest part — they contain massive `filled_polygon` blocks. For most analyses, extract only the header:

```python
zones = []
in_zone = False
zone_info = {}
for line in lines:
    stripped = line.strip()
    if re.match(r'\(zone\s*$', stripped) or re.match(r'\(zone\s+\(', stripped):
        in_zone = True
        zone_info = {}
    elif in_zone:
        m = re.search(r'\(net\s+(\d+)\)', line)
        if m: zone_info['net'] = int(m.group(1))
        m = re.search(r'\(net_name\s+"([^"]*)"', line)
        if m: zone_info['net_name'] = m.group(1)
        m = re.search(r'\(layer\s+"([^"]+)"', line)
        if m: zone_info['layer'] = m.group(1)
        m = re.search(r'\(priority\s+(\d+)\)', line)
        if m: zone_info['priority'] = int(m.group(1))
        if '(keepout' in line:
            zone_info['is_keepout'] = True
        if '(polygon' in line or '(filled_polygon' in line:
            zones.append(zone_info)
            in_zone = False
```

### Zone Fill Polygon Extraction

Only extract filled polygon data when you actually need zone containment tests:

```python
def extract_zone_polygon(lines, zone_net, zone_layer):
    """Extract filled_polygon vertices for a specific zone."""
    in_target_zone = False
    in_filled_poly = False
    points = []
    depth = 0

    for line in lines:
        if '(zone' in line:
            in_target_zone = False
            # Check if this is our target zone
        if in_target_zone and '(filled_polygon' in line:
            if f'(layer "{zone_layer}")' in line:
                in_filled_poly = True
                depth = line.count('(') - line.count(')')
                continue
        if in_filled_poly:
            for m in re.finditer(r'\(xy\s+([\d.-]+)\s+([\d.-]+)\)', line):
                points.append((float(m.group(1)), float(m.group(2))))
            depth += line.count('(') - line.count(')')
            if depth <= 0:
                return points
    return points
```

---

## Board Outline

Extract graphical primitives on the `Edge.Cuts` layer:

```python
outline_segments = []
for line in lines:
    if 'Edge.Cuts' in line:
        # Check parent block for gr_line, gr_arc, gr_rect, gr_circle
        pass

# Simpler: use buffer accumulation for gr_line blocks
buf = None
for line in lines:
    if '(gr_line' in line or '(gr_arc' in line or '(gr_rect' in line:
        buf = line
    elif buf:
        buf += line
        if line.strip().endswith(')'):
            if 'Edge.Cuts' in buf:
                if '(gr_line' in buf:
                    m = re.search(r'\(start\s+([\d.-]+)\s+([\d.-]+)\).*?\(end\s+([\d.-]+)\s+([\d.-]+)\)', buf, re.DOTALL)
                    if m:
                        outline_segments.append({
                            'type': 'line',
                            'start': (float(m.group(1)), float(m.group(2))),
                            'end': (float(m.group(3)), float(m.group(4)))
                        })
            buf = None

# Bounding box from all outline segments
if outline_segments:
    all_x = [s['start'][0] for s in outline_segments] + [s['end'][0] for s in outline_segments]
    all_y = [s['start'][1] for s in outline_segments] + [s['end'][1] for s in outline_segments]
    width = max(all_x) - min(all_x)
    height = max(all_y) - min(all_y)
```

---

## Connectivity Analysis

### Unrouted Net Detection

Checking whether a net has *any* routing is insufficient — nets can be partially routed with breaks. A proper connectivity analysis builds a graph per net and checks if all pads are in a single connected component.

#### Algorithm

1. **Extract pad positions** (absolute coordinates) — transform relative pad coords using footprint position/angle
2. **Extract routing elements per net** — segments, vias, and zone filled polygons
3. **Build union-find graph** for each net:
   - Union segment endpoints (each segment connects its start and end)
   - Union coincident points within ~50µm tolerance on the same copper layer
   - Union pad-to-trace (segment endpoint within pad area)
   - Union via connections (vias exist on multiple layers)
   - Union zone connections (point-in-polygon for filled areas)
4. **Count connected components** among pad points:
   - All pads in same component → fully routed
   - Multiple components → net has breaks (ratsnest lines)

#### Common False Positives

- ESP32/QFN ground slug pads may appear disconnected if they're just outside the zone fill boundary
- Zone fills may need to be re-poured after component moves
- Nets named `unconnected-(...)` are explicitly marked no-connect — skip these

---

## KiCad 5 Legacy Format

KiCad 5 PCB files use `(module ...)` instead of `(footprint ...)`, and `(fp_text reference ...)` instead of `(property "Reference" ...)`.

### Key Differences

| Modern (KiCad 6+) | Legacy (KiCad 5) |
|---|---|
| `(footprint "Lib:Name" ...)` | `(module "Lib:Name" ...)` |
| `(property "Reference" "U1" ...)` | `(fp_text reference "U1" ...)` |
| `(property "Value" "STM32" ...)` | `(fp_text value "STM32" ...)` |
| `(uuid "...")` | `(tstamp HEXID)` |
| Layer numbers: F.Cu=0, B.Cu=2 | Layer numbers: F.Cu=0, B.Cu=31 |

### Net Classes (KiCad 5 only)

KiCad 5 stores net classes directly in the PCB file:

```
(net_class Default "Default net class"
  (clearance 0.2)
  (trace_width 0.25)
  (via_dia 0.6)
  (via_drill 0.3)
  (uvia_dia 0.3)
  (uvia_drill 0.1)
  (add_net "GND")
  (add_net "+3V3")
)
```

### Dimension Annotations (KiCad 5)

```
(dimension 50.0
  (width 0.12)
  (layer "F.SilkS")
  (gr_text "50 mm" (at X Y ANGLE) ...)
  (feature1 (pts (xy X1 Y1) (xy X2 Y2)))
  (feature2 (pts (xy X3 Y3) (xy X4 Y4)))
  (crossbar (pts (xy X5 Y5) (xy X6 Y6)))
)
```

---

## Validation Methodology

When verifying analyzer output (or your own manual parse):

### Component Count Validation

1. Count all `(footprint ...)` or `(module ...)` top-level blocks
2. Compare against the analyzer's footprint count — should match exactly
3. Check for `(attr board_only)` or `(attr virtual)` components that may be excluded from counts

### Net Count Validation

1. Count all `(net N "name")` declarations (subtract net 0)
2. Compare against analyzer's net count
3. Spot-check 3-5 nets by finding all pads/segments/vias with that net ID

### Routing Completeness

1. Collect all unique net IDs from pads
2. For each net, check if it has at least one segment, via, or zone
3. Nets with multiple pads but no routing elements are unrouted
4. Nets with routing but disconnected islands need the full union-find analysis

### Known Edge Cases

- **Test points**: Single-pad footprints appear as "unrouted" nets — they only have one endpoint, which is correct
- **Mounting holes**: Non-plated holes (`np_thru_hole`) have no net and should be excluded
- **Board-only components**: Logos, fiducials with `(attr board_only)` may not have nets
- **Zone-only routing**: Some nets (especially GND) are routed entirely through copper pours with no tracks — check zone net assignments
- **Multi-layer zones**: A zone on F.Cu doesn't connect to the same zone on B.Cu unless there are vias between them

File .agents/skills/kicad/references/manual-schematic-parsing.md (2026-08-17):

# Manual Schematic Parsing (Script Fallback)

When `analyze_schematic.py` fails (unsupported format, newer KiCad version, corrupted file), fall back to direct file parsing. This is more expensive (reading raw S-expressions) but always works as long as the file is valid KiCad.

## Table of Contents

1. [When to Use Manual Parsing](#when-to-use-manual-parsing)
2. [File Format Quick Reference](#file-format-quick-reference)
3. [Component Extraction](#component-extraction)
4. [Net Building](#net-building)
5. [Signal Analysis Patterns](#signal-analysis-patterns)
6. [Legacy .sch Format](#legacy-sch-format)
7. [Validation Methodology](#validation-methodology)

---

## When to Use Manual Parsing

Use manual parsing when:
- `analyze_schematic.py` crashes or returns 0 components on a file you know has content
- The schematic is from a KiCad version newer than the script supports
- You need to validate script output against raw file data
- The file is partially corrupt but still readable

Always try the script first — it handles coordinate transforms, multi-unit symbols, hierarchical sheets, and net building automatically.

---

## File Format Quick Reference

### Modern `.kicad_sch` (KiCad 6+)

S-expression format. Key sections in order:

```
(kicad_sch (version N) (generator ...) (uuid ...)
  (lib_symbols ...)        ; Library symbol definitions (pin data, shapes)
  (junction ...)           ; Wire junction points
  (no_connect ...)         ; Explicit no-connect markers
  (wire ...)               ; Wire segments (coordinate pairs)
  (label ...)              ; Local net labels
  (global_label ...)       ; Cross-sheet net labels
  (hierarchical_label ...) ; Sheet-to-sheet pin labels
  (symbol ...)             ; Placed component instances
  (sheet ...)              ; Sub-sheet references (hierarchical designs)
)
```

### Legacy `.sch` (KiCad 4/5)

Line-based format. Key block types:

```
EESchema Schematic File Version N
$Comp / $EndComp          ; Component blocks
Wire Wire Line / x1 y1 x2 y2  ; Wire segments
Text Label / Text GLabel   ; Labels
NoConn ~ x y              ; No-connect markers
$Sheet / $EndSheet         ; Sub-sheet references
```

---

## Component Extraction

### Modern Format

Each placed component is a `(symbol ...)` block after the `(lib_symbols)` section:

```lisp
(symbol (lib_id "Device:R") (at 152.4 176.53 90) (unit 1)
  (property "Reference" "R13" ...)
  (property "Value" "10k" ...)
  (property "Footprint" "Resistor_SMD:R_0402_1005Metric" ...)
  (property "Datasheet" "~" ...)
  (pin "1" (uuid ...))
  (pin "2" (uuid ...))
)
```

**Extract for each component:**
- `lib_id` — library:symbol name
- `at` — placement position (X, Y, rotation angle)
- `unit` — which unit of a multi-unit symbol (1-based, e.g., LM324 unit 1-4 + power unit 5)
- Properties: Reference, Value, Footprint, Datasheet, MPN, Manufacturer, etc.

**Filtering:**
- Skip power symbols: `lib_id` contains `:power:` or the lib_symbol has a `(power)` flag
- Skip power flag markers: Reference starts with `#PWR` or `#FLG`
- Respect DNP: check for `(dnp yes)` attribute or `"DNP"` property

**Multi-unit symbols (critical):**
Symbols like LM324 (quad op-amp), STM32 (multi-bank MCU), dual inductors, relays — each unit is a separate `(symbol ...)` placement sharing the same Reference. Count unique References for BOM, not placements.

The `lib_symbols` section contains sub-symbols named `SymName_U_V` where U = unit number. `_0_1` sub-symbols contain pins shared by ALL units (typically power pins).

### Legacy Format

Components are in `$Comp`/`$EndComp` blocks:

```
$Comp
L library:SymbolName Reference
U unit_number convert_num timestamp
P x y
F 0 "R1" ...          ; Reference
F 1 "10k" ...         ; Value
F 2 "footprint" ...   ; Footprint
F 3 "datasheet" ...   ; Datasheet
F 4 "custom" ...      ; Custom field (MPN, Manufacturer, etc.)
    1    x y
$EndComp
```

**Custom fields (F4+):** May contain MPN (`manf#`, `MPN`, `MFG Part`), Manufacturer (`Manufacturer`, `MFG`), distributor part numbers (`DigiKey`, `Mouser`, `LCSC`), or DNP flag.

---

## Net Building

### Coordinate-Based Union-Find (Modern Format)

KiCad schematics don't store netlists — connectivity is implicit through coordinate matching. Build nets by:

1. **Extract all wire endpoints** from `(wire (pts (xy X1 Y1) (xy X2 Y2)))` blocks
2. **Compute absolute pin positions** for each component (see `net-tracing.md` for transforms)
3. **Union-find**: merge coordinate groups connected by wires, junctions, and shared endpoints
4. **Assign net names** from labels (local, global, hierarchical) and power symbols at group endpoints

**Critical rules:**
- **Y-axis inversion**: `absolute_Y = symbol_Y - pin_Y` (not `+`)
- **Sheet isolation**: Each sheet has a separate coordinate space. Only global labels and power symbols connect across sheets. Local labels are scoped to their sheet.
- **Junctions**: Wires crossing at a point only connect if there's an explicit `(junction (at X Y))`. T-junctions (wire endpoint touching mid-wire) also connect.
- **Power symbols connect globally**: All instances of `GND`, `+3V3`, etc. are the same net regardless of sheet.

### Net Names

Nets are named by (priority order):
1. Power symbol name (e.g., `GND`, `+3V3`, `+5V`)
2. Global label name
3. Local label name
4. Hierarchical label name
5. Unnamed (auto-generated `__unnamed_N`)

### Legacy Format

Wires: `Wire Wire Line` followed by `X1 Y1 X2 Y2` on next line.
Labels: `Text Label X Y orientation 0 ~ 0 "NetName"` or `Text GLabel ...`.
No-connects: `NoConn ~ X Y`.

---

## Signal Analysis Patterns

When scripts can't detect subcircuits, look for these patterns manually in the component/net data.

### Power Regulators

**LDO pattern:** IC with pins named VIN, VOUT, GND (and optionally EN, PG, ADJ/FB). VIN and VOUT connect to different named power nets.

**Switching regulator pattern:** IC with SW/LX/PH pin connected to an inductor. May also have FB pin with voltage divider, BOOT/BST pin with bootstrap capacitor.

**Pin name variants:**
| Function | Pin names |
|---|---|
| Input | VIN, VI, IN, PVIN, AVIN, INPUT |
| Output | VOUT, VO, OUT, OUTPUT |
| Feedback | FB, VFB, ADJ, VADJ (may have numeric suffix: FB1, ADJ2) |
| Switch | SW, PH, LX (may have numeric suffix: SW1, SW2) |
| Enable | EN, ENABLE, ON, ~{SHDN}, SHDN, ~{EN} |
| Bootstrap | BOOT, BST, BOOTSTRAP, CBST |

**Custom library detection:** If the IC has both VIN and VOUT connected to distinct recognized power nets (e.g., +5V and +3V3), it's almost certainly a regulator even without keyword matches in the library name.

### Voltage Dividers

Two resistors in series: R1_pin1→Net_top, R1_pin2→R2_pin1→Mid_net, R2_pin2→Net_bottom. The mid-point net should NOT be a power rail with many connections (that's pull-ups sharing a bus, not a divider).

`ratio = R_bottom / (R_top + R_bottom)`

### Op-Amp Circuits

Look for ICs with `+IN`/`IN+`, `-IN`/`IN-`, `OUT` pins (or bare `+`, `-`, `~` pin names for KiCad standard library op-amps).

**Multi-unit op-amps (LM324, TL082, etc.):** Each unit has its own +IN/-IN/OUT pins with different pin numbers. When analyzing manually, check the `lib_symbols` section for `SymName_N_1` sub-symbols to identify which pins belong to which unit.

**Configurations:**
- **Buffer**: OUT connected directly to -IN
- **Inverting**: Feedback R from OUT to -IN, input R to -IN, +IN to reference/ground
- **Non-inverting**: Feedback R from OUT to -IN, +IN to signal, -IN to ground via R
- **Comparator/open-loop**: No feedback resistor from OUT to -IN

**Common false positives:**
- Current sense amps (INA180/181/185/186/190/199): Have IN+/IN- pins but are fixed-gain, not user-configurable op-amps
- Digital power monitors (INA219/226/229): Have I2C interface, not analog op-amp pins
- Analog front-ends (AD8233): Complex ICs with internal op-amps that don't follow standard topology

### Transistor Circuits

**N-channel MOSFET:** Look for Q references with `NMOS`/`N-Channel` in lib_id or ki_keywords. Gate→drive signal, Drain→load, Source→GND (low-side switch).

**P-channel MOSFET:** `PMOS`/`P-Channel` in lib_id or ki_keywords. Source→power rail, Drain→load, Gate→control (inverted logic). Used as high-side switches.

**Reliable P-channel detection (priority order):**
1. `ki_keywords` from lib_symbol containing "P-Channel" — most reliable
2. lib_id containing `pmos`, `p-channel`, `q_pmos`
3. Value containing unambiguous P-channel family names (DMP series from Diodes Inc)

**Bridge circuits:** Look for transistor pairs where one drain connects to another's source (half-bridge mid-point). Two such pairs = H-bridge. Three = 3-phase.

### Protection Devices

TVS/ESD diodes: Keywords `TVS`, `ESD`, `PESD`, `PRTR`, `USBLC`, `SMAJ`, `SMBJ`, `LESD` in value or lib_id. Connected between signal line and ground/power.

ESD protection ICs: `USBLC6`, `PRTR5V`, `SP0502`, `TPD4E05` etc. Multi-channel protection arrays.

### Bus Detection

**I2C:** Nets named `SDA`/`SCL` (or containing these substrings), or IC pins named `SDA`/`SCL`. Look for pull-up resistors (2.2k-10k) to VCC. Exclude `SCLK`/`SCK` pins (SPI, not I2C).

**SPI:** Nets named `MOSI`/`MISO`/`SCK`/`CS` or `COPI`/`CIPO`/`SCK`/`CS`.

**UART:** Nets named `TX`/`RX`/`TXD`/`RXD` (exclude nets also containing `CAN`, `SPI`, `I2C`).

**CAN:** Nets named `CANH`/`CANL` or CAN transceiver ICs (MCP2551, SN65HVD230, TJA1050, etc.). Don't confuse with RS-485 (SN65HVD75 is RS-485, not CAN).

---

## Legacy .sch Format

### What the Analyzer Provides

The analyzer now parses `.lib` files (cache libraries and project libs) to populate pin data for legacy schematics. When `.lib` files are available:

- All component references, values, footprints, lib_ids
- Pin positions, pin names, and pin types (from `.lib` files)
- Pin-to-net mapping via wire connectivity + pin positions
- Signal analysis (voltage dividers, regulators, op-amp circuits, etc.)
- Subcircuit detection (IC + 1-hop neighbors)
- Net names from labels, power symbols, and pin associations
- Custom properties (F4+ fields: MPN, manufacturer, distributor PNs)

### Remaining Limitations

- **Pin coverage depends on `.lib` availability** — components whose `.lib` files aren't in the repo (standard KiCad system libs like `power`, `device`, `conn`) use built-in fallbacks for common symbols (R, C, L, D, LED, transistors). Uncommon standard library symbols may lack pin data.
- **No ki_keywords** — P-channel detection relies on lib_id and value only

### Hierarchical Legacy Designs

Top-level `.sch` has `$Sheet` blocks with `F1 "subsheet.sch"` pointing to sub-sheet files. Parse all sub-sheets. Hierarchical labels in sub-sheets connect to pins on the sheet block in the parent.

---

## Validation Methodology

When verifying analyzer output (or your own manual parse) against the raw schematic:

### Component Count Validation

1. Count all `(symbol (lib_id ...))` blocks after `(lib_symbols)` section
2. Subtract power symbols (`#PWR`, `#FLG` references)
3. Result should exactly match the analyzer's `component_count`

### Net Count Validation

1. Count all `(wire ...)` blocks to verify wire count
2. The number of unique named nets should match approximately (unnamed nets may differ in grouping)
3. Spot-check 3-5 specific nets by tracing pins → wires → labels manually

### Signal Analysis Validation

For each detected subcircuit:
1. Verify the component IS what the analyzer says (check lib_id, value)
2. Verify the pin connections are as reported (trace through nets)
3. Check for false positives: is this detection actually correct?
4. Check for false negatives: are there obvious subcircuits the analyzer missed?

**Severity guide:**
- **HIGH**: Wrong component data (extraction bug) or grossly incorrect detection
- **MEDIUM**: Misleading detection (regulator classified wrong topology, wrong gain)
- **LOW**: Minor cosmetic issue (missing unit number, suboptimal configuration label)

### Known Edge Cases

- **Custom libraries**: Components from project-specific libraries may lack keywords that standard KiCad libraries have. Regulators, op-amps, and transistors from custom libs may not be detected.
- **Multi-unit symbols**: LM324 (quad op-amp), dual inductors, relays — each unit needs separate analysis. Pin numbers are unit-specific.
- **Unit-0 shared pins**: In KiCad lib_symbols, `_0_1` sub-symbols contain pins shared by all units (typically power: VCC, GND). These must be included with every placed unit.
- **Rescue libraries**: KiCad creates `*-rescue` libraries during migration. Check for `lib_prefix == "power"` exactly, not substring match (e.g., `dc-power-supply-rescue` is NOT a power library).
- **Eagle .sch files**: Not KiCad format — will output 0 components. These are XML or binary and require separate tools.

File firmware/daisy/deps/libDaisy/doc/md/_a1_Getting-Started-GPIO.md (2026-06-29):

# Getting Started - GPIO

GPIO stands for General Purpose Input/Output. These are common to microcontrollers of all sizes, and are one of the many ways to work with external components.

GPIO are used as the basis for several interface components including switches, LEDs, encoders, etc.

The Daisy exposes several GPIO on its pinout. Most of these pins can do much more than just be a digital input or output, but we'll keep it simple for now.

Below, we'll discuss the code, hardware, and provide a few examples of how to use the GPIO within the Daisy ecosystem.

## The CPP Objects Used

We'll be using the `DaisySeed`, `Pin`, and `GPIO` objects in the following sections.

If you're using a different Daisy SOM (i.e. DaisyPatchSM, etc.) this still applies, but some of the pin names will be different.

The `DaisySeed` object is a class that manages all of the hardware on the Seed board. All we need to do with it for now is initialize it.

The `Pin` class is used to describe a specific physical pin on the hardware. These objects are used to initialize GPIO, but are also used in the configuration of more complex peripherals and devices (i.e. ADCs, Shift Registers, etc.).

The `GPIO` class is used for the basic reading/writing of a digital signal.

When we talk about "digital" signals, we mean a signal that has only two states, HIGH and LOW.

## The Hardware Connections

For the examples below we'll be using a few components. These can be replaced with a number of similar alternatives.

* [Mini Pushbutton](https://www.electro-smith.com/parts/pushbuttons)
* [3mm LED](https://www.electro-smith.com/parts/3mm-leds)
* Resistor(s) any low value (1-10K should work okay in the examples discussed below)

## GPIO Input

One of the simplest uses of a GPIO is to read the state of a button.

For this example we'll use a simple [mini pushbutton](https://www.electro-smith.com/parts/pushbuttons) to read the state of a button.

The easiest way to wire up a switch like this is to connect one set of legs (pins 1 and 2) to the GPIO input, and connect the other two legs (pins 3 and 4) to GND.

A very short example of a program to do this looks like:

```cpp
#include "daisy_seed.h"

using namespace daisy;
using namespace daisy::seed;

DaisySeed hw;

int main(void) {
  // Initialize the Daisy Seed
  hw.Init();

  // Create a GPIO object
  GPIO my_button;

  // Initialize the GPIO object
  my_button.Init(D0, GPIO::Mode::INPUT, GPIO::Pull::PULLUP);

  while(1) {
    // And let's store the state of the button in a variable called "button_state"
    bool button_state = my_button.Read();
  }
}
```

If you haven't followed the guides on [setting up your development environment](https://github.com/electro-smith/DaisyWiki/wiki/1.-Setting-Up-Your-Development-Environment) and [creating a new project](https://github.com/electro-smith/DaisyWiki/wiki/How-To:-Create-a-New-Project) now would be a perfect time to catch up, and create a new project to work with the GPIO.

Compiling this example, you might get a warning, for an "unused variable button_state", but we'll get to using that shortly!

## Breaking Down the Init function

Let's look at that GPIO init function in a bit more detail, shall we? First, we'll breakdown the full Initialization definition:

```cpp
void Init(Pin p, Mode m=Mode::INPUT, Pull pu=Pull::NOPULL, Speed sp=Speed::LOW);
```

The first thing you may be wondering, if you're not used to C++ is the `::` characters all over the place. These are used for the configuration settings so that the compiler will only allow you to use the correct inputs instead of being able to pass the wrong thing to the input, or even just mis-order the arguments, and end up scratching your head for hours wondering what's not working.

These `::` are also used for namespaces, which we handle in the above example with the `using namespace` lines. Without that we'd have to use `daisy::GPIO` instead of `GPIO`, `daisy::seed::D0` instead of `D0`, etc.

### Pin Argument

So, the first argument: `Pin p` describes the daisy pin to assign to our GPIO, this ties our new GPIO object to some of the actual hardware on the Daisy Seed. By using `D0` (or more explicitly, `daisy::seed::D0`), we're saying we want to use that pin for our GPIO.

### Mode Argument

The second argument: `Mode m` can be any of the following:

* `Mode::INPUT` - configures the pin as an input
* `Mode::OUTPUT` - configures the pin as an output (in push pull configuration)
* `Mode::OUTPUT_OD` - also an output, but the transistor connection to pull the signal to GND is not connected, this is less commonly used.
* `Mode::ANALOG` - configures the GPIO for connection to the ADC or DAC peripherals within the micro controller.

If you only supply the `Pin` argument, the GPIO will default to `Mode::INPUT` configuration.

### Pull Argument

The third argument: `Pull pu` is used to select whether the GPIO will use an internal (around 30-50k) resistor as a pull up or pull down resistor.

A pull up resistor will keep the GPIO idling at 3V3 unless something pulls it down, while a pull down resistor will keep a GPIO idling at 0V unless something pulls it up.

The options for this argument are:

* `Pull::NOPULL` - no pull up or pull down resistor is connected.
* `Pull::PULLUP` - pull up resistor is connected to the GPIO line.
* `Pull::PULLDOWN` - pull down resistor is connected to the GPIO line.

This argument will default to `Pull::NOPULL` if you only supply a `Pin` and a `Mode`

So when, and why do we need pull up or pull down resistors anyway?

Well, if we connect a wire to one of Daisy's GPIO pins, and there are no internal or external resistors attached, there's no definite way to know what voltage the wire is sitting at.

Now, if we connect the wire to a button, as we did in the above example, and connect the other side of the button to 3V3 then we _do_ know the voltage at the pin when the button pressed.
However, when the button is not pressed, we still have an "undefined" state, as we can't guarantee that the pin will be at 0V when the button isn't pressed.

To solve this unknown state issue, we can add a resistor to the pin that "pulls" the signal to GND when the button isn't actively pulling the voltage up to 3V3 (while pressed).

Instead of adding an external resistor to do this, we can use the built-in pull-down feature to accomplish the same thing.

In the example above, we did the same thing except we used the pull up resistor, and wired the button to GND. This usually just requires less wires, but the function is the same.

### Speed Argument

The final argument, `Speed sp` is a special configuration for Output modes that control the slew rate, or the speed at which it can switch from 0V to 3V. We won't go super in depth on that in this, but you'll always want it to be the lowest speed possible for a given application to reduce the amount of electrical noise emitted.

## GPIO Output

So you've got your button reading code, your board wired up, and you're probably thinking, "Great! So how can I tell if I've done this correctly!?".

Well, let's set up a second pin as an output to light up an LED when we push our button. That way we can tell everything we've done so far is working.

Setting up the GPIO output isn't much more work.

On your hardware, you'll want to take the second pin (right above the square D0 pin), and connect a resistor, and an LED in series. You'll want the **cathode** of the LED connected to GND, with the **anode** connected to the resistor, [as described here](https://makecode.adafruit.com/learnsystem/pins-tutorial/devices/led-connections).

Once you've got that set up we can add a few lines to our example.

In the Initialization section:

```cpp
GPIO my_led;

my_led.Init(D1, GPIO::Mode::OUTPUT);
```

And then we can use the `button_state` variable we were reading from the button earlier to control the state of the LED:

```cpp
while(1)
{
  // And let's store the state of the button in a variable called "button_state"
  bool button_state = my_button.Read();
  my_led.Write(button_state);
}
```

And that's it! Easy, right?

So you get that all set up, and you might be thinking, "Well, this is great, but the LED turns off when I push the button instead of turning it on, what the heck?"

That's because of the way we set up the button in the first step. Because we used the internal pull up resistor, to avoid adding extra parts to our board, the GPIO is returning true while the button is not pressed instead of what we might expect. Well, C++ has a very easy way of flipping that over.

```cpp
bool button_state = my_button.Read(); // state is false while button is pressed
bool button_pressed = !button_state; // "!" is a "not" operator, which will flip a bool var.
```

So all together, our short little light switch program will look something like:

```cpp
#include "daisy_seed.h"

using namespace daisy;
using namespace daisy::seed;

DaisySeed hw;

int main(void) {
  // Initialize the Daisy Seed
  hw.Init();

  // Create our GPIO object
  GPIO my_button;
  GPIO my_led;

  // Initialize the GPIO object for our button */
  my_button.Init(D0, GPIO::Mode::INPUT, GPIO::Pull::PULLUP);

  // Initialize the GPIO object for our LED
  my_led.Init(D1, GPIO::Mode::OUTPUT);

  while(1) {
    // And let's store the state of the button in a variable called "button_state"
    bool button_state = my_button.Read();

    // And we want to light up the LED while we're pressing the button 
    // so let's use the "!" to flip over the button_state
    my_led.Write(!button_state);
  }
}
```

## Further Reading

Topics coming soon:

* Working with ADCs
* Serial Printing over USB
* Using the Switch and LED classes instead of GPIO, and Why?

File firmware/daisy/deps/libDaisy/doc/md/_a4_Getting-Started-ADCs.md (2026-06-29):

# Getting Started - ADCs

ADC stands for Analog to Digital Converter. These are used to read in a variable signal. These variable signals can be anything from a potentiometer, photoresistor, external control voltage, etc.

On the Daisy, the ADC inputs expect a signal in the range of 0V to 3.3V, unless otherwise stated (e.g. The CV inputs on the Daisy Patch SM are set up to expect -5V to 5V, a common range for Modular Synthesizers).

In this tutorial we'll be using the Daisy Seed hardware, and we will go through the process of connecting a few inputs to one of the many available ADC pins.

## The CPP Objects Used

We'll be using the `DaisySeed`, it's internal `AdcHandle`, `Pin`, and `AdcChannelConfig` objects in the following sections.

If you're using a different Daisy SOM (i.e. DaisyPatchSM, etc.) this is handled within the board support files for all available inputs.

The `DaisySeed` object is a class that manages all of the hardware on the Seed board. All we need to do with it for now is initialize it.

The `AdcHandle` is a handler for the microcontroller's embedded Analog to Digital Converter. It is up to 16-bits, and can handle multiplexing several inputs.

The `Pin` class is used to describe a specific physical pin on the hardware. These objects are used to initialize GPIO, but are also used in the configuration of more complex peripherals and devices (i.e. ADCs, Shift Registers, etc.).

The `AdcChannelConfig` object is used to define each of the connections to the ADC, and the order in which the inputs will be read.

## The Hardware Connections

For this tutorial all we'll need is:

* a few potentiometers like these [9mm Plastic Shaft Pot with Pointers](https://www.electro-smith.com/parts/trimmer), but any potentiometer should do the trick.

To wire up the pot we'll want to connect pin 1 of the pot to GND, and pin 3 of the pot to 3v3_A, and the middle leg (pin 2) will now output a variable voltage from 0V to 3.3V; perfect for our expected input range.

When working with the Daisy and external hardware, **always connect the DGND and AGND pins outside of the Daisy**

## ADC Channel Config

libDaisy uses the STM32 ADC1 peripheral, which is a single ADC with several multiplexed inputs.

This makes setting it up a little different than something like a GPIO, because the ADC will scan through all of the configured inputs in the background without taking up CPU time.

To define what connections are made we will use the `AdcChannelConfig` class.

The AdcChannelConfig has two possible initialization functions:

* `InitSingle` - For configuring a single input to a single pin on the Daisy
* `InitMux` - For configuring several inputs from an external multiplexer (like CD4051) to a single pin on the Daisy

Below we'll only be using the `InitSingle` function, but stay tuned for a guide for connecting a ton of controls using external multiplexer in the future.

The `InitSingle` function takes an old version of the Daisy's `Pin` object, but it is compatible with the new pins. So anywhere you see, `dsy_gpio_pin` you can use the `Pin` object instead.

This structure, and the number of channels can then be passed to the `AdcHandle` to set everything up.

## A Single Input

Alright, enough talk. Let's plug some stuff in, and write some code!

We can take a look at all of the available ADC pins by looking at the [Pinout Diagram](https://github.com/electro-smith/DaisyWiki/wiki/2.-Daisy-Seed-Pinout). The ADC Pins are all labeled and colored in yellow.

Let's get started with pin `A0` (also known as `D15`), and wire up our potentiometer.

See the wiring mentioned above in the [Hardware Connections](#The-Hardware-Connections) for how to connect all of the legs of the pot, and take the wiper (middle leg), and connect that to the `A0` pin on the Daisy.

And here's a short program that will setup, and read from an ADC:

```cpp
#include "daisy_seed.h"

using namespace daisy;
using namespace daisy::seed;

// Create out Daisy Seed Hardware object
DaisySeed hw;

int main(void) {
  // Initialize the Daisy Seed hardware
  hw.Init();

  // Start logging for printing over serial
  hw.StartLog();

  // Create an ADC Channel Config object
  AdcChannelConfig adc_config;

  // Set up the ADC config with a connection to pin A0
  adc_config.InitSingle(A0);

  // Initialize the ADC peripheral with that configuration
  hw.adc.Init(&adc_config, 1);

  // Start the ADC
  hw.adc.Start();

  while(1) {
    // Read the first ADC that's configured. In our case, this is the only input.
    int value = hw.adc.Get(0);

    // In order to know that everything's working let's print that to a serial console:
    hw.PrintLine("ADC Value: %d", value);

    // Wait half a second (500 milliseconds)
    System::Delay(500);
  }
}
```

To find out more about the serial printing, and what software to use, see our [tutorial on working with Serial Printing](_a2_Getting-Started-Serial-Printing.md).

With the above program, you should see a number printing that moves from 0 to 65536 as you rotate the pot. Now, pots, and electronics aren't perfect.
So there's a chance that this may not reach those extremes, or it might reach them slightly before the edges of the potentiometer's range.
This will largely depend on the potentiometer you're using.

Now that's great and all, but it would be nicer to work with a number that is scaled between 0 and 1 instead (since that's more useful for doing other things).

We can actually get the value in that range instead by changing the line where we were doing:

```cpp
int value = hw.adc.Get(0); // value will be 0-65536
```

to this Instead:

```cpp
float value = hw.adc.GetFloat(0); // value will be 0.0 to 1.0
```

floating point numbers have a few peculiarities because of the hardware and memory requirements of an embedded project, but you can keep the serial printing by adding the following to the project Makefile:

```make
LDFLAGS += -u _printf_float
```

This isn't included by default because it increases the flash size by several kilobytes, and there are other ways to print floating point numbers (more info on this in the [serial printing tutorial](tutorial)).

## Multiple Inputs

Most things get better when you add more of whatever it is. The same goes for controls!

Now we've set up a single pot. So let's look at what it would look like to hook up two (or more).

Nearly everything will stay the same except instead of using a single `AdcChannelConfig`, we'll want to create one for each control we want to use. C and C++ have a mechanism for dealing with this known as an array. If you're not familiar, it is basically just an ordered list.

So for setting up two pots we'll change the initialization code to look a little more like:

```cpp
// Create an array of two AdcChannelConfig objects
const int num_adc_channels = 2;
AdcChannelConfig my_adc_config[num_adc_channels];
// Initialize the first one connected to A0
my_adc_config[0].InitSingle(A0);
// Initialize the second one connected to A4
my_adc_config[1].InitSingle(A4);
```

And finally when we go to initialize the ADC itself, we can now omit the `&` that we had to use before because it's an array of objects, and we want to make sure to update the total count that we passed in before:

```cpp
hw.adc.Init(my_adc_config, num_adc_channels);
```

Now you can read from either input. If you want to read the pot connected to A0 you would use `hw.adc.Get(0)`, or `hw.adc.GetFloat(0)`, and if you want to read from the pot connected to A4, you would use `hw.adc.Get(1)`, or `hw.adc.GetFloat(1)`.

You'll notice that you access them by the order in which you initialized them, not by the number associated with the Pin.

## Order To Chaos - Naming ADC Channels

Once you have a lot of ADC channels, it can be difficult to remember which channel corresponds to which control. To solve this, you can use `enum`s to assign names to channels like this:

```cpp
enum AdcChannel {
   pitchKnob = 0,
   pitchCv,
   gainKnob,
   gainCv,
   NUM_ADC_CHANNELS
}
```

Here, the first value is assigned to `0`and the others increment automatically. Interestingly, this logic can be used to automatically get the total number of channels you use, by adding one last value `NUM_ADC_CHANNELS`. Of course you could also specify the individual values by hand, just add `myKnob = 3,`.

Now you can make your code much easier to read - and maintain, should you decide to change the hardware connections later:

```cpp
AdcChannelConfig my_adc_config[NUM_ADC_CHANNELS];
// ...
my_adc_config[pitchCv].InitSingle(A0);
// ...
hw.adc.Init(my_adc_config, NUM_ADC_CHANNELS);
// ...
const float pitchCvValue = hw.adc.GetFloat(pitchCv);
```

## Using Different Kinds of Inputs

OK. So now we know what to do with one, or a few inputs that already conform to the expected input range.

In a future guide we'll look at using active and passive circuits to condition a signal to the best range for sending to the Daisy.

## Further Reading

Topics coming soon:

* Printing with USB
* HID classes (Switch, Led, AnalogControl) and why we use them

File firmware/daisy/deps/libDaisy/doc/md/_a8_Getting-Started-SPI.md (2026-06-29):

# SPI

SPI stands for Serial Peripheral Interface, and is a way for devices to talk to one another.
The protocol is used with one device as the main device or the leader.
All other devices are followers.

There are four pins generally used:
- MOSI: Main Out Serial In
- MISO: Main In Serial Out
- SCLK: Serial Clock
- NSS: Serial Select (Chip Select)

## How to Use SPI

First create your SpiHandle object and a Config struct to configure it.
Set any configurations you want to change in the config object, then initialize the spi peripheral with it.

A typical Daisy Seed configuration might look like this

```cpp
// SpiHandle object and Spi Configuration object
SpiHandle spi_handle;
SpiHandle::Config spi_conf;

// Set some configurations
spi_conf.periph = SpiHandle::Peripheral::SPI_1;
spi_conf.mode = SpiHandle::Mode::MASTER;
spi_conf.direction = SpiHandle::Direction::TWO_LINES;
spi_conf.nss = SpiHandle::NSS::NSS_HARD_OUTPUT;
spi_conf.pin_config.sclk = Pin(PORTG, 11);
spi_conf.pin_config.miso = Pin(PORTB, 4);
spi_conf.pin_config.mosi = Pin(PORTB, 5);
spi_conf.pin_config.nss = Pin(PORTG, 10);

// Initialize the handle using our configuration
spi_handle.Init(spi_conf);
```

### Configuration

The default configuration sets the common defaults for SPI peripherals. However some peripherals may require changing these. Some other configurations you'll have to set every time you use SPI.

`spi_conf.peripheral`
The peripheral to be used. Must be specified by the user. For example `SpiHandle::Config::Peripheral::SPI_2`.
The Daisy has 6 different SPI peripherals available, each of which uses different pins. Refer to the pinout diagram for more details.

`spi_conf.mode`
Master or slave. The main device is in charge of the bus (sets the clock, and NSS), the other devices follow along. Most of the time the Daisy will be in charge of the bus.
- `SpiHandle::Config::Mode::MASTER`. The Daisy runs the bus.
- `SpiHandle::Config::Mode::SLAVE`. The Daisy follows another device.

`spi_conf.pin_config`
The pins to be used by this SPI peripheral. These will have to match the peripheral you choose. Must be specified by the user.

- `spi_conf.pin_config.miso`: Main In Serial Out: The main device reads from this pin, and the others write to it.
- `spi_conf.pin_config.mosi`: Main Out Serial In: The main device writes to this pin, and the others read from it.
- `spi_conf.pin_config.sclk`: Serial Clock. The main device outputs a clock signal on this pin.
- `spi_conf.pin_config.nss`: Serial Select. The main device uses this to indicate data is being sent. Usually active low.

If you're not using a pin (e.g. software NSS, or simplex communication) you can set it to `Pin()`.

`spi_conf.direction`
Which direction data will travel. Must be specified by the user.

- `SpiHandle::Config::Direction::TWO_LINES`. Data goes both ways. Each line only goes one direction. i.e. MOSI -> MISO and MISO <- MOSI. This is full duplex. 
- `SpiHandle::Config::Direction::TWO_LINES_TX_ONLY`. The Daisy will only send data. If Daisy's the main device: MOSI->. If the Daisy's a follower MISO->. This is simplex TX.
- `SpiHandle::Config::Direction::TWO_LINES_RX_ONLY`. The Daisy will only read data. If Daisy;s the main device MISO<-. If Daisy's a follower MOSI<-. This is simplex RX.
- `SpiHandle::Config::Direction::ONE_LINE`. Data goes both ways over one line. i.e. MOSI <-> MISO. This is half duplex.

`spi_conf.data_size`
How many bits in each transmission. Defaults to 8.
Must be in the range [4, 32] inclusive.

`spi_conf.clock_polarity`
Is the clock active low or high? 
(Determines if the "first" and "second" edges are rising or falling.)

- `SpiHandle::Config::ClockPolarity::HIGH`. The clock is active high.
- `SpiHandle::Config::ClockPolarity::LOW`. The clock is active low.

Defaults to `SpiHandle::Config::ClockPolarity::LOW`.

`spi_conf.clock_phase`
When is the data ready to be read?
The "first edge" is when we transition __to__ the clock polarity.
The "second edge" is when we transition __away from__ the clock polarity.

So if the polarity is low, the first edge is when the clock goes low.
Again, if the polarity is low, the second edge is when the clock goes high.

- `SpiHandle::Config::ClockPhase::ONE_EDGE` Data is read on the first edge.
- `SpiHandle::Config::ClockPhase::TWO_EDGE`. Data is read on the second edge.

Defaults to `SpiHandle::Config::ClockPhase::ONE_EDGE`.

`spi_conf.nss`
Serial select mode. Must be set by the user.

- `SpiHandle::Config::NSS::SOFT`. Serial select is handled in software. You can ignore the NSS pin.
- `SpiHandle::Config::NSS::HARD_INPUT`. The NSS pin is in use, and the Daisy is a follower.
- `SpiHandle::Config::NSS::HARD_OUTPUT`. The NSS pin is in use, and the Daisy is a leader.

`spi_conf.baud_prescaler`
Division of the default clock rate. 
The clock rate is always 25MHz. 
So with a prescaler of 4 for example, the final clock rate is 25MHz / 4 = 6.25MHz.

Defaults to `SpiHandle::Config::BaudPrescaler::PS_8`

## Blocking Transmit and Receive

Send / receive data in a blocking fashion. The code waits while the transmissions are taking place.

```cpp
// send 4 bytes
uint8_t buffer[4] = {0, 1, 2, 3};
spi_handle.BlockingTransmit(buffer, 4);
```

```cpp
// receive 4 bytes
uint8_t buffer[4];
spi_handle.BlockingReceive(buffer, 4);
```

```cpp
// send and receive 4 bytes
uint8_t tx_buffer[4] = {0, 1, 2, 3};
uint8_t rx_buffer[4];
spi_handle.BlockingTransmitAndReceive(tx_buffer, rx_buffer, 4);
```

## DMA Transmit and Receive

Send / receive data using DMA (Direct Memory Access). 
This allows the hardware to handle the transmission in the background while the code is doing other things.
i.e. it is non blocking.

You can also pass along a callback to be called when the transfer starts, another for when the transfer is over, and a pointer to some data to send those callbacks.

**Note:** Your buffer has to be in the DMA section of memory, as well as in a global scope.

```cpp
// buffer for sending data
uint8_t DMA_BUFFER_MEM_SECTION buffer[4];

// fill the buffer 0, 1, 2, 3
for(uint8_t i = 0; i < 4; i++)
{
    buffer[i] = i;
}

// transmit the data
spi_handle.DmaTransmit(buffer, 4, NULL, NULL, NULL);
```

```cpp
// receive 4 bytes. No callbacks or callback data.
uint8_t DMA_BUFFER_MEM_SECTION buffer[4];
spi_handle.DmaReceive(buffer, 4, NULL, NULL, NULL);
```

```cpp
// send and receive 4 bytes. No callbacks or callback data.
uint8_t DMA_BUFFER_MEM_SECTION tx_buffer[4];
uint8_t DMA_BUFFER_MEM_SECTION rx_buffer[4];

// fill the TX buffer 0, 1, 2, 3
for(uint8_t i = 0; i < 4; i++)
{
   tx_buffer[i] = i;
}

// transmit and receive
spi_handle.DmaTransmitAndReceive(tx_buffer, rx_buffer, 4, NULL, NULL, NULL);
```

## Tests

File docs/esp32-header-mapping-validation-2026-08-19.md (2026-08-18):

# ESP32 Header Mapping Validation

**Date:** 2026-08-19  
**Carrier:** `hardware/boards/daisyBoard.kicad_sch` and `daisyBoard.kicad_pcb`  
**Expected plug-in board:** 30-pin DOIT ESP32 DevKit V1-style board using ESP32-WROOM-32  
**Firmware target:** PlatformIO `esp32dev`

## Verdict

The two 1x15 socket rows match the common 30-pin DOIT ESP32 DevKit V1 pin order, dimensions, and opposing row orientation. The active SD and UART assignments are correct for ESP32-WROOM-32, and the duplicate breakout headers preserve the physical row order.

This is not a footprint for the bare 38-pad ESP32-WROOM-32 module or a 38-pin ESP32-DevKitC. Before assembly, confirm that the purchased development board is the 30-pin variant and that its printed end pins match `VIN/GND` and `3V3/GND` as listed below.

## Physical Geometry

- Header row spacing: 25.40 mm.
- Pin pitch: 2.54 mm.
- Fourteen pitch intervals per row: 35.56 mm.
- Power/USB end: J1 pin 1 `VIN` aligns with J2 pin 15 `3V3`.
- Antenna end: J1 pin 15 `EN` aligns with J2 pin 1 `GPIO23`.

That geometry and opposing numbering direction match the common 30-pin DevKit V1 layout.

## J1 Left Row

| J1 pin | Expected DevKit signal | Carrier net | Status |
|---:|---|---|---|
| 1 | VIN / regulated 5 V input | `VCC_ESP32` | Pass; supplied from +5 V through FB1 |
| 2 | GND | `GND` | Pass |
| 3 | GPIO13 | Breakout only | Pass |
| 4 | GPIO12 / MTDI | Breakout only | Pass; strapping pin, avoid an external high level at reset |
| 5 | GPIO14 | Breakout only | Pass |
| 6 | GPIO27 | Breakout only | Pass |
| 7 | GPIO26 | Breakout only | Pass |
| 8 | GPIO25 | Breakout only | Pass |
| 9 | GPIO33 | Breakout only | Pass |
| 10 | GPIO32 | Breakout only | Pass |
| 11 | GPIO35 | Breakout only | Pass; input-only, no internal pull resistors |
| 12 | GPIO34 | Breakout only | Pass; input-only, no internal pull resistors |
| 13 | GPIO39 / VN | Breakout only | Pass; input-only, no internal pull resistors |
| 14 | GPIO36 / VP | Breakout only | Pass; input-only, no internal pull resistors |
| 15 | EN | Breakout only | Pass |

## J2 Right Row

| J2 pin | Expected DevKit signal | Carrier net/use | Status |
|---:|---|---|---|
| 1 | GPIO23 | `/SD_MOSI` | Pass; standard VSPI MOSI |
| 2 | GPIO22 | Breakout only | Pass |
| 3 | GPIO1 / TX0 | Breakout only | Pass; used by USB serial during programming/logging |
| 4 | GPIO3 / RX0 | Breakout only | Pass; used by USB serial during programming |
| 5 | GPIO21 | Breakout only | Pass |
| 6 | GPIO19 | `/SD_MISO` | Pass; standard VSPI MISO |
| 7 | GPIO18 | `/SD_SCK` | Pass; standard VSPI clock |
| 8 | GPIO5 | `/SD_CS` | Pass; R26 provides a 47 kohm pull-up to `ESP-3.3V` |
| 9 | GPIO17 / TX2 | `/ESP_TO_DAISY` | Pass; firmware UART2 TX |
| 10 | GPIO16 / RX2 | `/DAISY_TO_ESP` | Pass; firmware UART2 RX |
| 11 | GPIO4 | Breakout only | Pass |
| 12 | GPIO2 | Breakout only | Pass; strapping pin |
| 13 | GPIO15 / MTDO | Breakout only | Pass; strapping pin |
| 14 | GND | `GND` | Pass |
| 15 | 3V3 | `ESP-3.3V` and ESP SD-card supply | Pass, subject to the exact DevKit regulator current rating |

## Breakout Headers

J3 and J4 intentionally reverse connector numbering so their physical top-to-bottom order mirrors the corresponding socket rows:

- J3 pin 1 through pin 15 connects to J2 pin 15 through pin 1.
- J4 pin 1 through pin 15 connects to J1 pin 15 through pin 1.

This is electrically correct, but assembly and debug documentation should show signal names because equal pin numbers do not connect between the socket and breakout headers.

## Peripheral Validation

### ESP32 SD card

The SD card uses the conventional VSPI assignment:

```text
GPIO23 -> MOSI
GPIO19 <- MISO
GPIO18 -> SCK
GPIO5  -> CS
```

Card2 is correctly wired in SPI mode: DAT3/CS, CMD/MOSI, CLK/SCK, DAT0/MISO, 3.3 V, and GND. DAT1 and DAT2 are unconnected as expected for SPI mode.

GPIO5 is a strapping pin sampled during reset. The SD card's CS pin should be high or high-impedance while the ESP32 boots. Existing `R26 = 47 kohm` pulls `/SD_CS` up to `ESP-3.3V`, keeping the card deselected and reinforcing the normal GPIO5 boot state. No additional pull-up is required.

### Daisy UART

Firmware uses UART2 with RX=GPIO16 and TX=GPIO17:

```text
ESP32 GPIO17 TX -> /ESP_TO_DAISY -> Daisy RX
ESP32 GPIO16 RX <- /DAISY_TO_ESP <- Daisy TX
```

This agrees with `DaisyBridge::DefaultRxPin = 16` and `DefaultTxPin = 17`. GPIO16 and GPIO17 are available on ESP32-WROOM-32. They may be occupied by PSRAM on ESP32-WROVER variants, so do not substitute a WROVER board without rechecking.

## Pin Restrictions

- GPIO34, GPIO35, GPIO36, and GPIO39 are input-only and have no software-controlled pull-up or pull-down.
- GPIO2, GPIO5, GPIO12, and GPIO15 are boot-strapping pins. External circuits must not force an invalid level during reset.
- GPIO1 and GPIO3 are UART0 and are used by USB serial for flashing and logs.
- GPIO6 through GPIO11 are connected to module flash and are correctly absent from these headers.
- ADC2 pins cannot be used for ADC measurements while Wi-Fi is active. Use ADC1 pins GPIO32-39 for future analog controls.

## Remaining Verification

The carrier does not identify an exact development-board manufacturer or MPN. `ESP32-WROOM-32` identifies the RF module, not the surrounding 30-pin USB/regulator board. Before ordering or soldering sockets:

1. Confirm the board has exactly 15 pins per side.
2. With USB at the power end, confirm one row begins `VIN, GND, GPIO13` and the other end aligns with `3V3, GND, GPIO15` according to the table.
3. Confirm 25.40 mm row spacing and 35.56 mm pin-span length.
4. Confirm the board uses ESP32-WROOM-32 rather than ESP32-WROVER, ESP32-S2, ESP32-S3, or ESP32-C3.
5. Add the exact board MPN and a body/antenna footprint with the vendor-defined keepout.

## Result

**Electrical mapping:** Pass for the common 30-pin DOIT ESP32 DevKit V1-style ESP32-WROOM-32 board.  
**Firmware mapping:** Pass.  
**Mechanical interchangeability:** Conditional on confirming the exact 30-pin board variant.  
**Boot-strapping support:** Pass; GPIO5 `/SD_CS` already has the required pull-up through R26.

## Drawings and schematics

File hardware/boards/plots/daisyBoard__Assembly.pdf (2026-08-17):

TP23 | C19 C20 J2 | R23 R5 | C22
J4 | C7

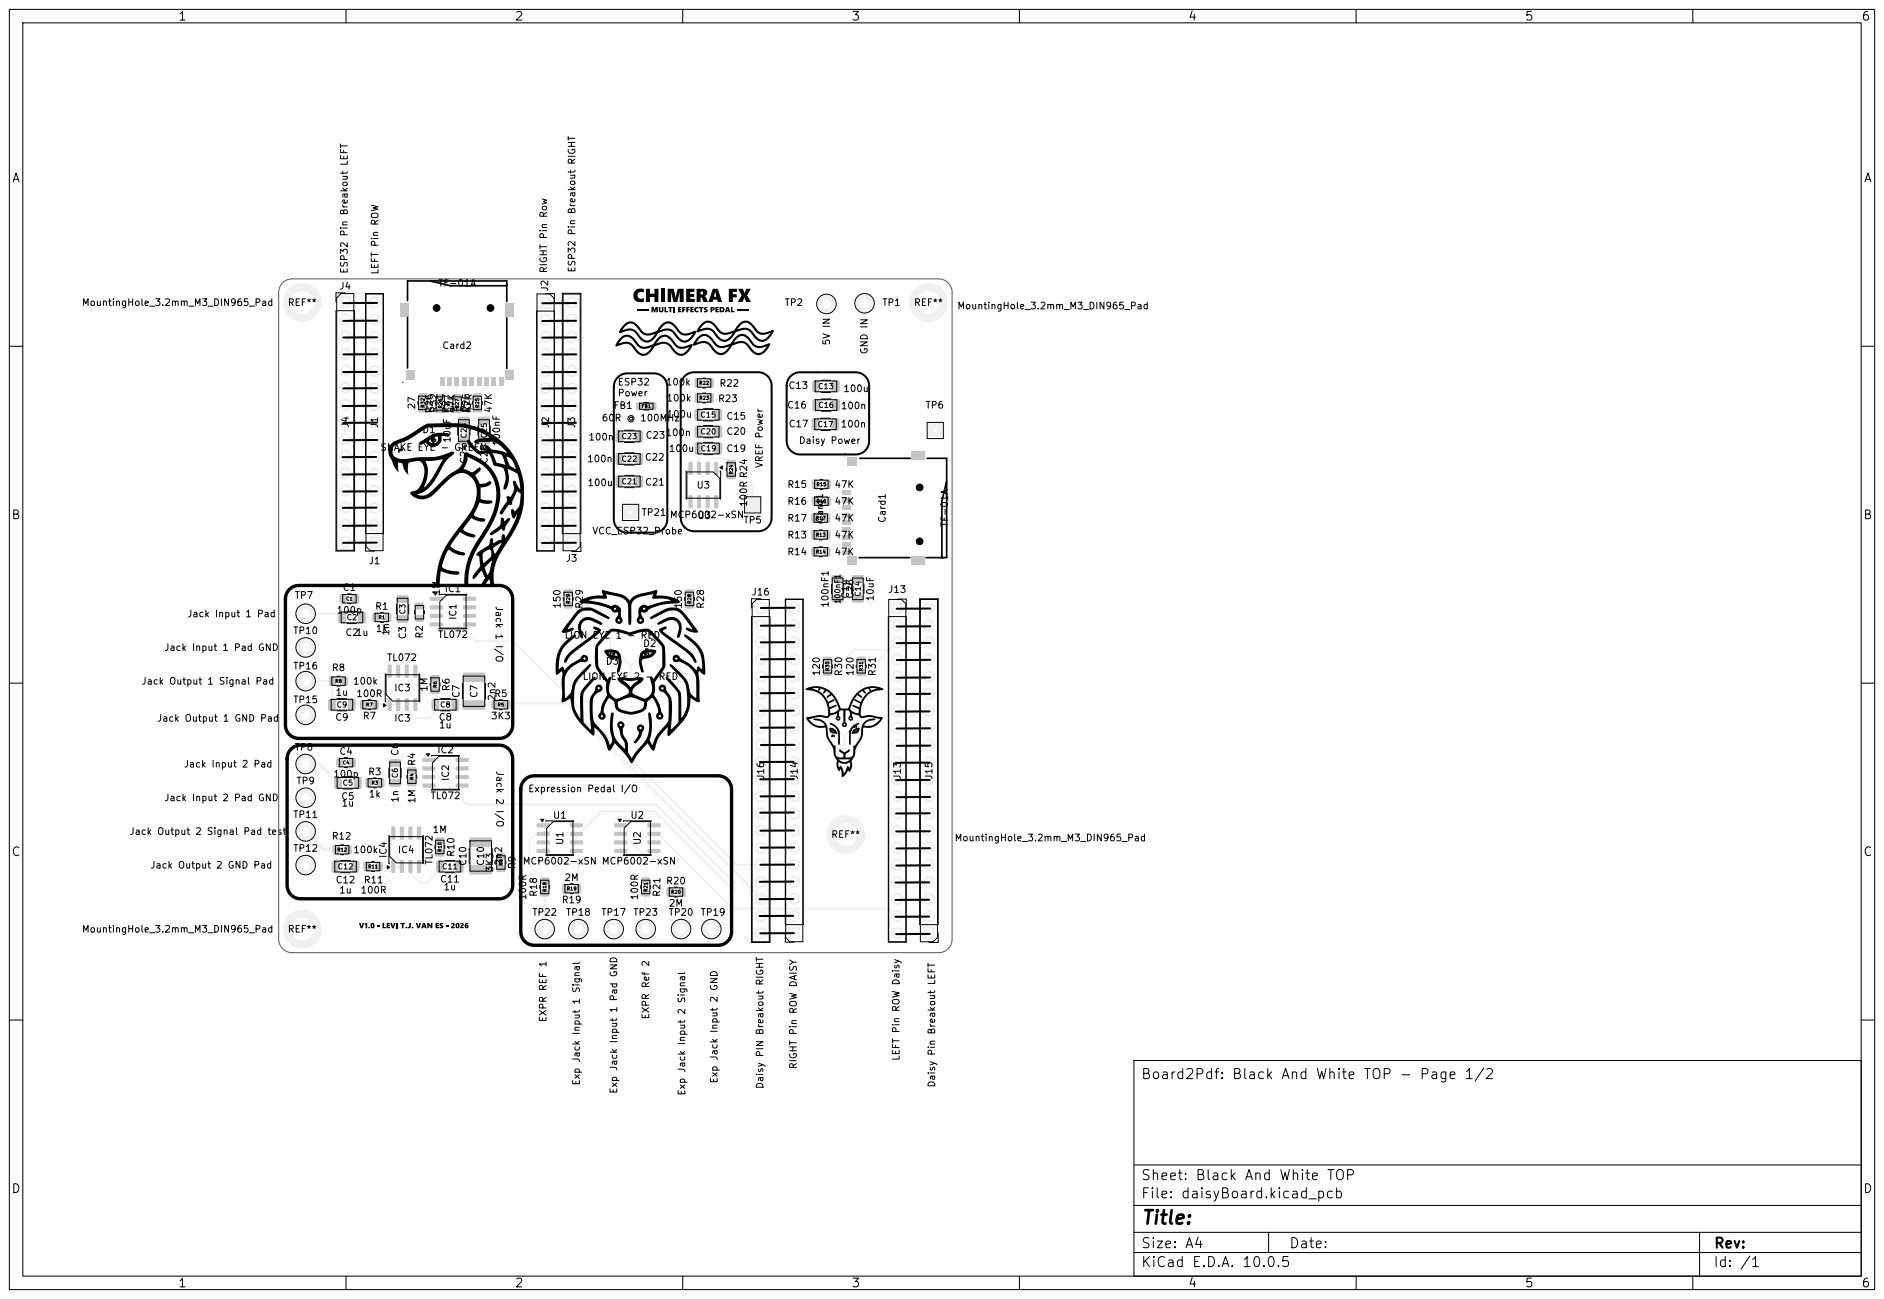
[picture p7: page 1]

Jack Input 1 Pad GND

Jack Output 1 Signal Pad

Board2Pdf: Black And White TOP - Page 1/2

Sheet: Black And White TOP
File: daisyBoard.kicad_pcb
Title:
KiCad E.D.A. 10.0.5

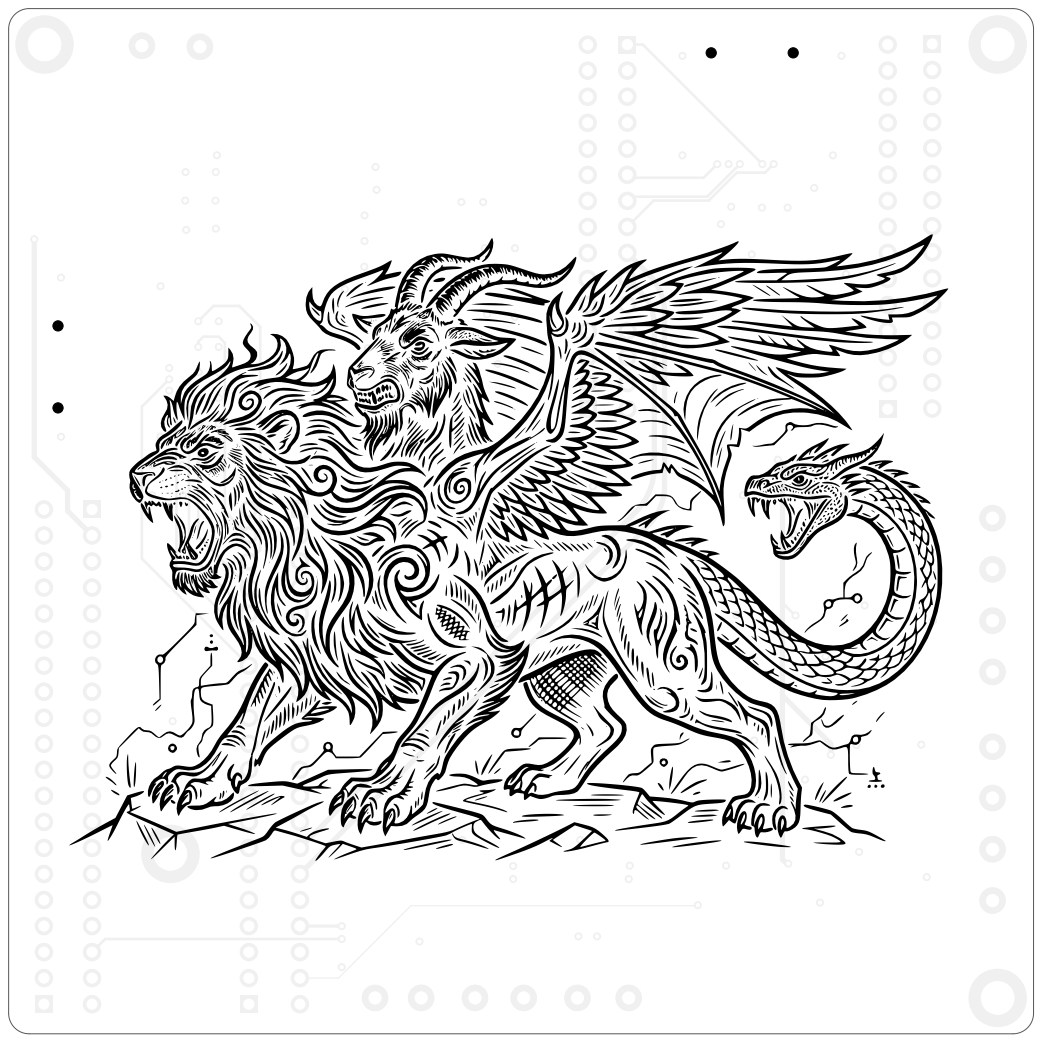
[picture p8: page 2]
D Date:; Size: A4; Rev:

Board2Pdf: Black And White BOT - Page 2/2

Sheet: Black And White BOT
File: daisyBoard.kicad_pcb
Title:
KiCad E.D.A. 10.0.5

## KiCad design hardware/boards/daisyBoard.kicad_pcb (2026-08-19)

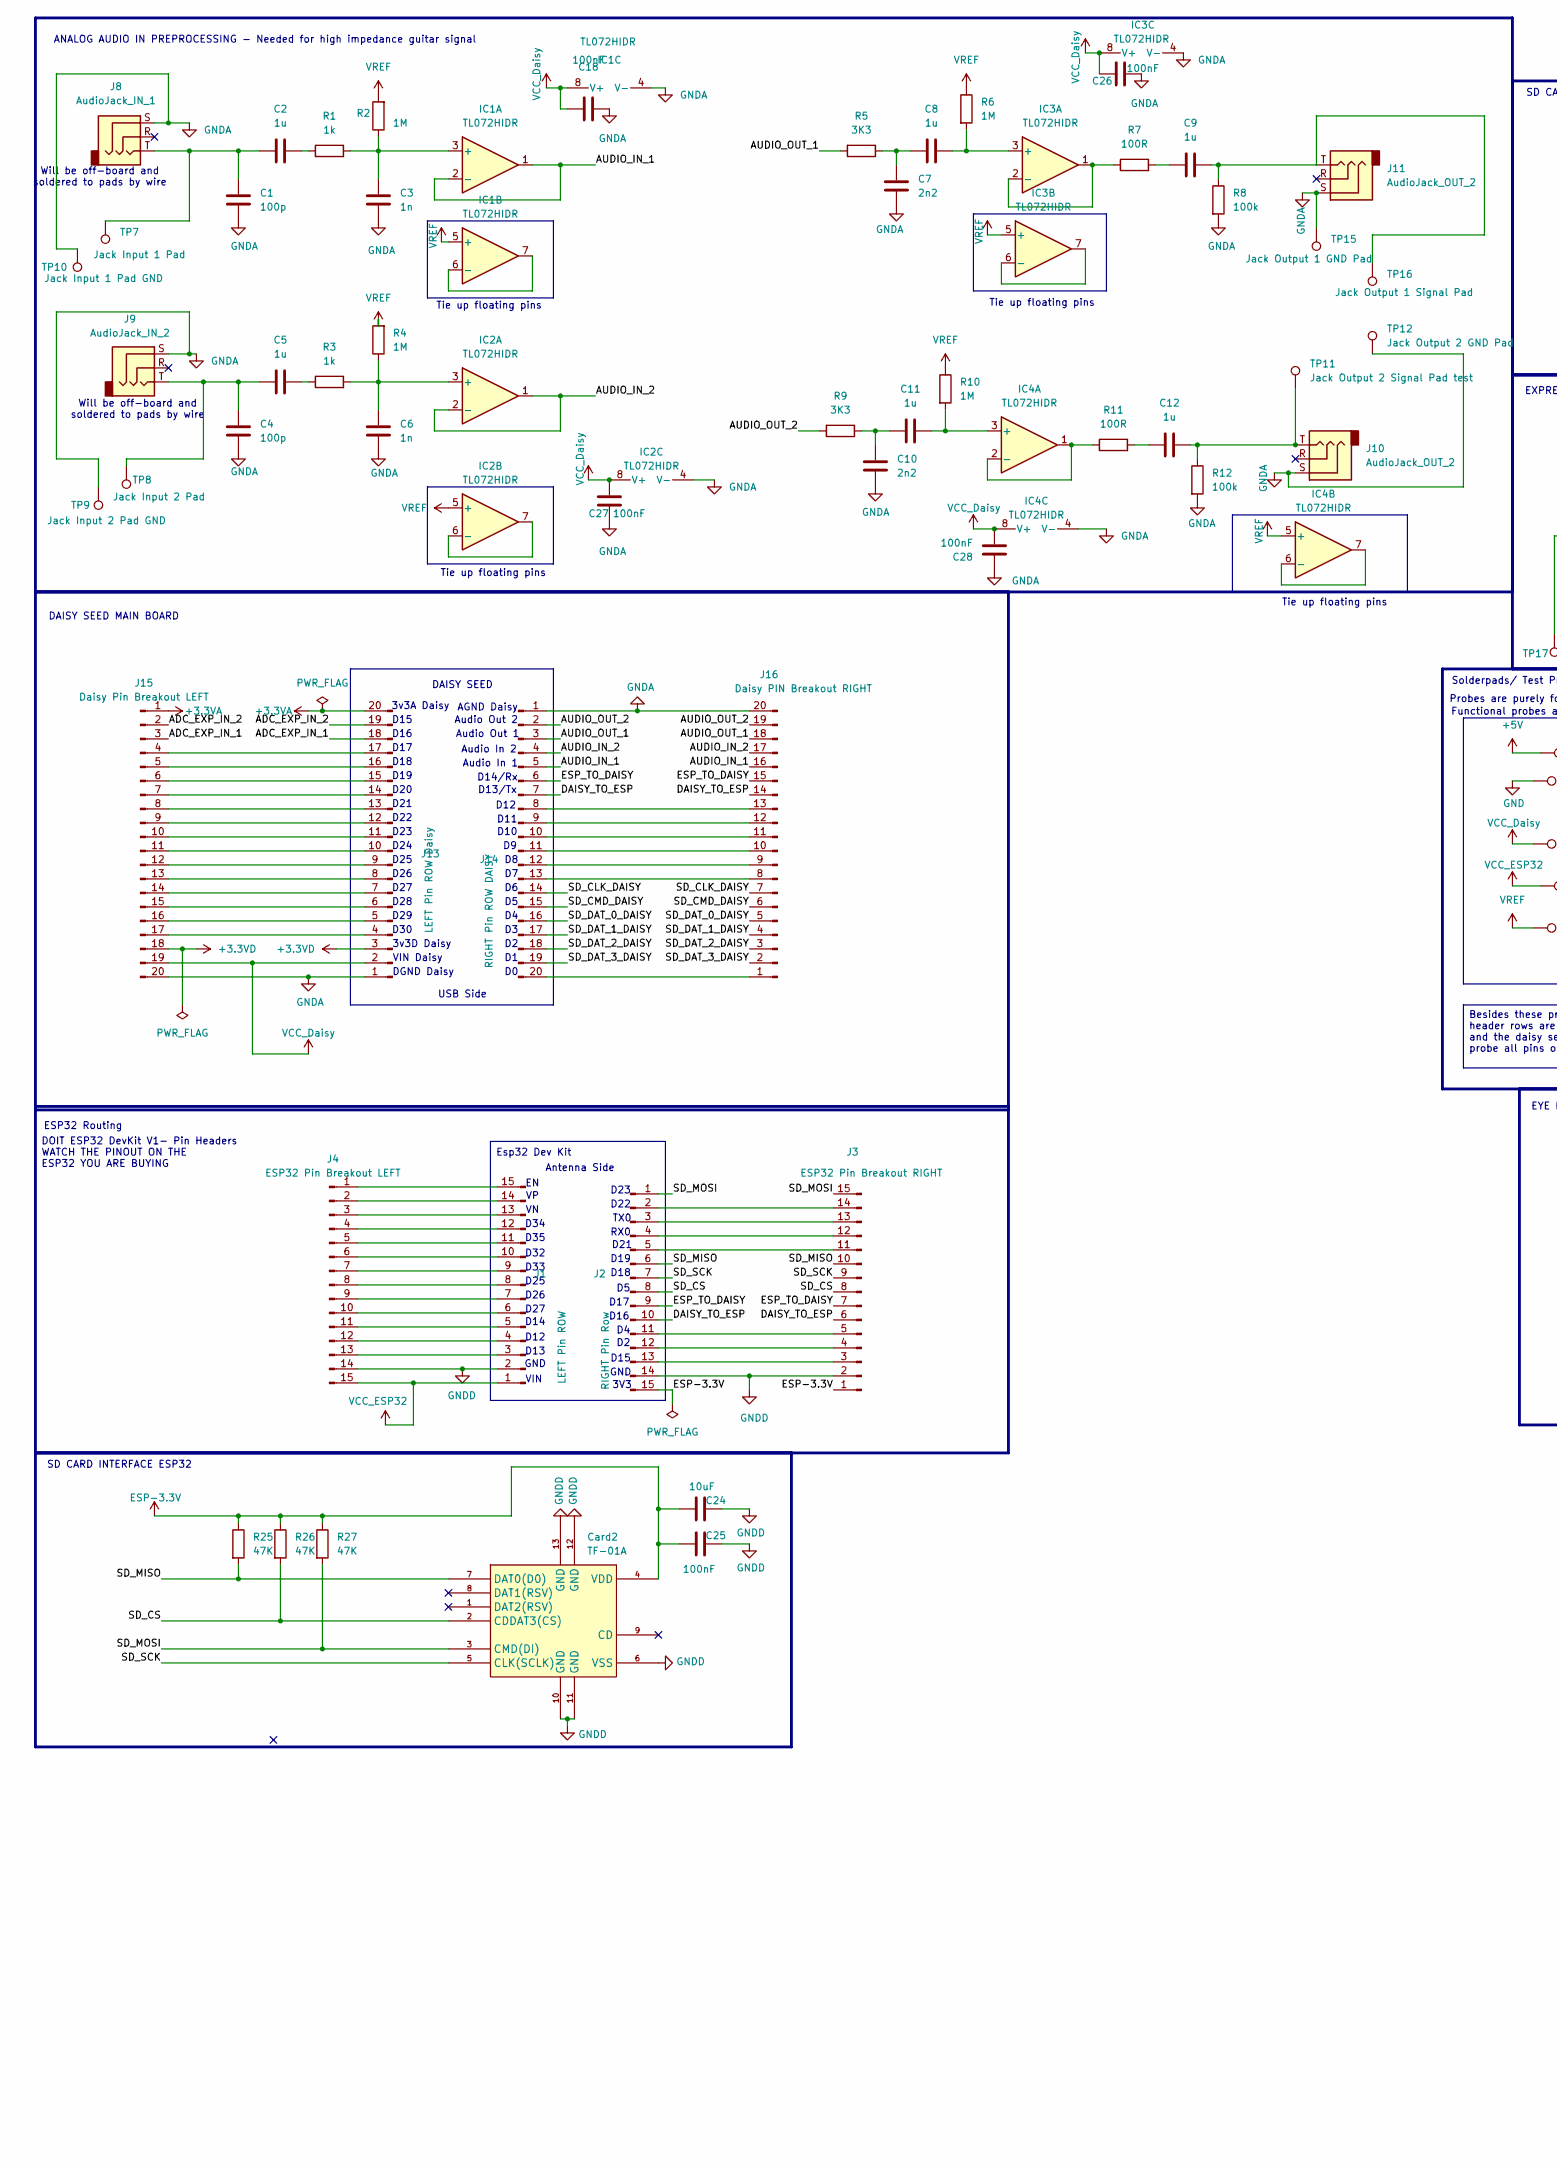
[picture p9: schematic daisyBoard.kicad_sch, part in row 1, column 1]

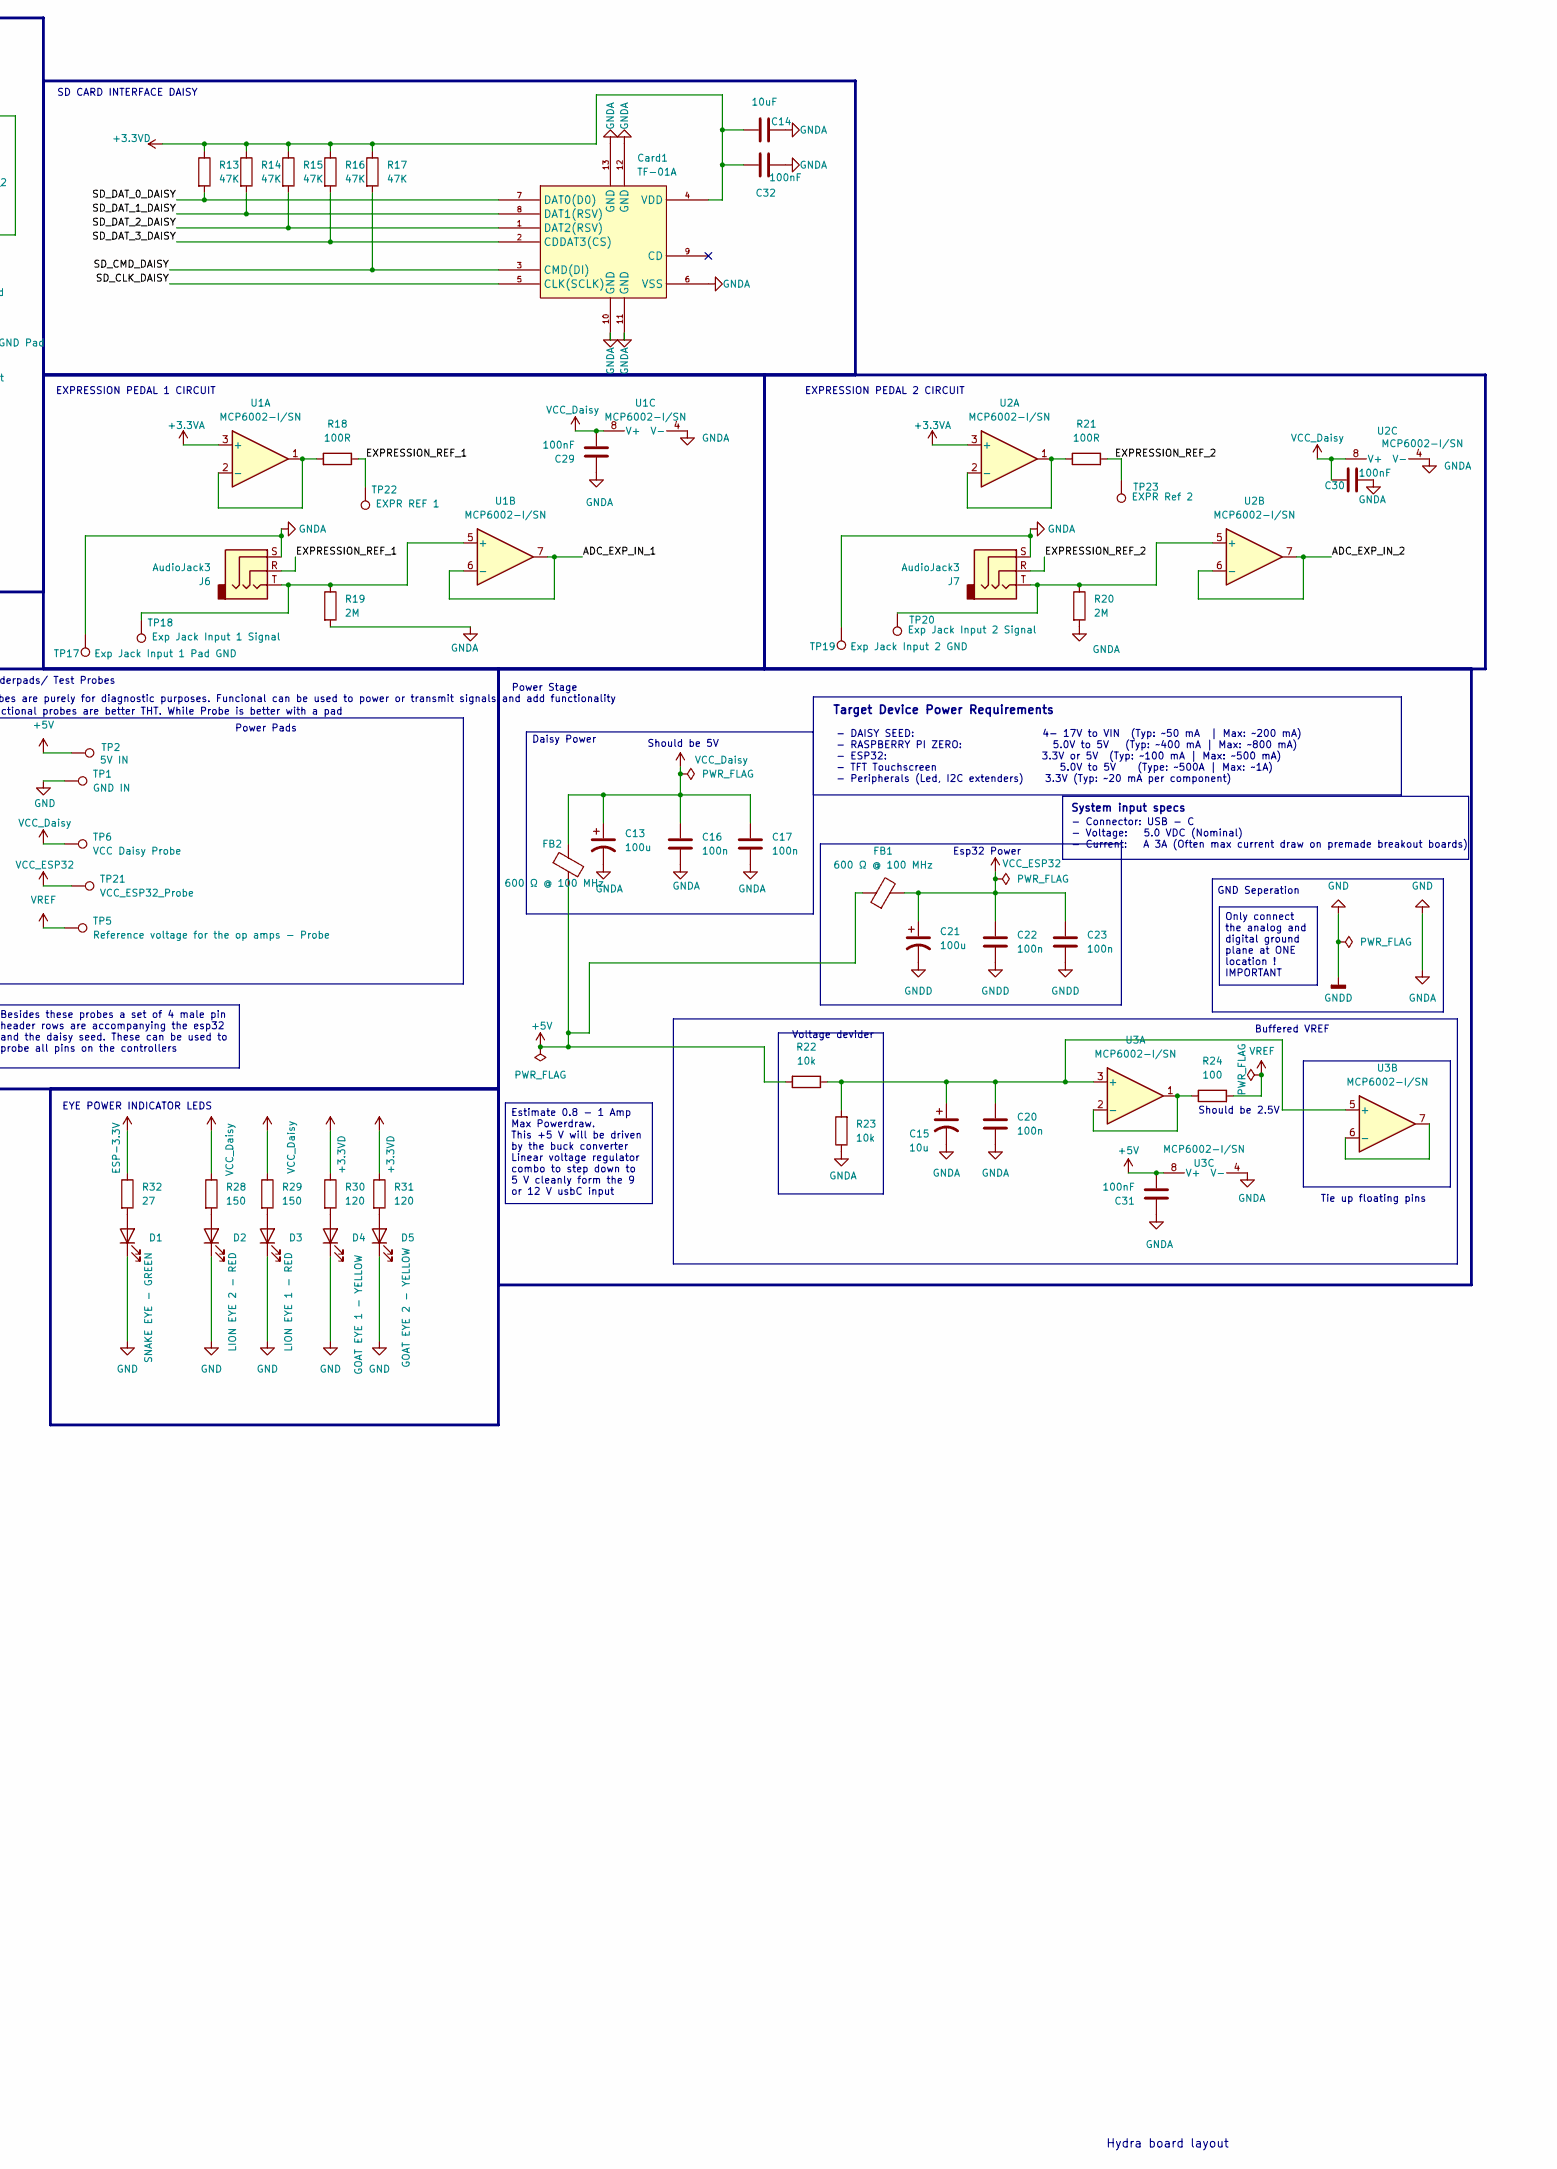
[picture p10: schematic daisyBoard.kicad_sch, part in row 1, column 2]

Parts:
C1, C4: 100p; C_0805_2012Metric
C2, C5, C8, C9, C11, C12: 1u; C_1206_3216Metric
C3, C6: 1n; C_1206_3216Metric
C7, C10: 2n2; C_1812_4532Metric
C13, C21: 100u; C_1206_3216Metric
C14, C24: 10uF; C_1206_3216Metric
C15: 10u; C_1206_3216Metric
C16, C17, C20, C22, C23: 100n; C_1206_3216Metric
C18, C25, C26, C27, C28, C29, C30, C31, C32: 100nF; C_1206_3216Metric
Card1, Card2: TF-01A; C91145_TF-SMD_TF-01A; LCSC C91145
D1: SNAKE EYE - GREEN; LED_0201_0603Metric
D2: LION EYE 2 - RED; LED_0201_0603Metric
D3: LION EYE 1 - RED; LED_0201_0603Metric
D4: GOAT EYE 1 - YELLOW; LED_0201_0603Metric
D5: GOAT EYE 2 - YELLOW; LED_0201_0603Metric
FB1, FB2: 600 Ω @ 100 MHz; L_0805_2012Metric
IC1, IC2, IC3, IC4: TL072HIDR; SOIC-8_3.9x4.9mm_P1.27mm
J1: LEFT Pin ROW; PinSocket_1x15_P2.54mm_Vertical
J2: RIGHT Pin Row; PinSocket_1x15_P2.54mm_Vertical
J3: ESP32 Pin Breakout RIGHT; PinHeader_1x15_P2.54mm_Vertical
J4: ESP32 Pin Breakout LEFT; PinHeader_1x15_P2.54mm_Vertical
J6, J7: AudioJack3
J8: AudioJack_IN_1
J9: AudioJack_IN_2
J10, J11: AudioJack_OUT_2
J13: LEFT Pin ROW Daisy; PinSocket_1x20_P2.54mm_Vertical
J14: RIGHT Pin ROW DAISY; PinSocket_1x20_P2.54mm_Vertical
J15: Daisy Pin Breakout LEFT; PinHeader_1x20_P2.54mm_Vertical
J16: Daisy PIN Breakout RIGHT; PinHeader_1x20_P2.54mm_Vertical
R1, R3: 1k; R_0805_2012Metric
R2, R4, R6, R10: 1M; R_0805_2012Metric
R5, R9: 3K3; R_0805_2012Metric
R7, R11, R18, R21: 100R; R_0805_2012Metric
R8, R12: 100k; R_0805_2012Metric
R13, R14, R15, R16, R17, R25, R26, R27: 47K; R_0805_2012Metric
R19, R20: 2M; R_0805_2012Metric
R22, R23: 10k; R_0805_2012Metric
R24: 100; R_0805_2012Metric
R28, R29: 150; R_0805_2012Metric
R30, R31: 120; R_0805_2012Metric
R32: 27; R_0805_2012Metric
TP1: GND IN; TestPoint_THTPad_D2.5mm_Drill1.2mm
TP2: 5V IN; TestPoint_THTPad_D2.5mm_Drill1.2mm
TP5: Reference voltage for the op amps - Probe; TestPoint_Pad_2.0x2.0mm
TP6: VCC Daisy Probe; TestPoint_Pad_2.0x2.0mm
TP7: Jack Input 1 Pad; TestPoint_THTPad_D2.5mm_Drill1.2mm
TP8: Jack Input 2 Pad; TestPoint_THTPad_D2.5mm_Drill1.2mm
TP9: Jack Input 2 Pad GND; TestPoint_THTPad_D2.5mm_Drill1.2mm
TP10: Jack Input 1 Pad GND; TestPoint_THTPad_D2.5mm_Drill1.2mm
TP11: Jack Output 2 Signal Pad test; TestPoint_THTPad_D2.5mm_Drill1.2mm
TP12: Jack Output 2 GND Pad; TestPoint_THTPad_D2.5mm_Drill1.2mm
TP15: Jack Output 1 GND Pad; TestPoint_THTPad_D2.5mm_Drill1.2mm
TP16: Jack Output 1 Signal Pad; TestPoint_THTPad_D2.5mm_Drill1.2mm
TP17: Exp Jack Input 1 Pad GND; TestPoint_THTPad_D2.5mm_Drill1.2mm
TP18: Exp Jack Input 1 Signal; TestPoint_THTPad_D2.5mm_Drill1.2mm
TP19: Exp Jack Input 2 GND; TestPoint_THTPad_D2.5mm_Drill1.2mm
TP20: Exp Jack Input 2 Signal; TestPoint_THTPad_D2.5mm_Drill1.2mm
TP21: VCC_ESP32_Probe; TestPoint_Pad_2.0x2.0mm
TP22: EXPR REF 1; TestPoint_THTPad_D2.5mm_Drill1.2mm
TP23: EXPR Ref 2; TestPoint_THTPad_D2.5mm_Drill1.2mm
U1, U2, U3: MCP6002-I/SN; SOIC-8_3.9x4.9mm_P1.27mm

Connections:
+3.3VA: J13.20, J15.1, U1.3 (+), U2.3 (+)
+3.3VD: C14.2, C32.2, Card1.4 (VDD), J13.3, J15.18, R13.1, R14.1, R15.1, R16.1, R17.1, R30.1, R31.1
+5V: C31.2, FB1.1, FB2.2, R22.2, TP2.1 (1_1), U3.8 (V+)
/ADC_EXP_IN_1: J13.18, J15.3, U1.6 (-), U1.7
/ADC_EXP_IN_2: J13.19, J15.2, U2.6 (-), U2.7
/AUDIO_IN_1: IC1.1, IC1.2 (-), J14.5, J16.16
/AUDIO_IN_2: IC2.1, IC2.2 (-), J14.4, J16.17
/AUDIO_OUT_1: J14.3, J16.18, R5.2
/AUDIO_OUT_2: J14.2, J16.19, R9.2
/DAISY_TO_ESP: J2.10, J3.6, J14.7, J16.14
/ESP_TO_DAISY: J2.9, J3.7, J14.6, J16.15
/EXPRESSION_REF_1: J6.R, R18.1, TP22.1 (1_1)
/EXPRESSION_REF_2: J7.R, R21.2, TP23.1 (1_1)
/SD_CLK_DAISY: Card1.5 (CLK(SCLK)), J14.14, J16.7
/SD_CMD_DAISY: Card1.3 (CMD(DI)), J14.15, J16.6, R17.2
/SD_CS: Card2.2 (CDDAT3(CS)), J2.8, J3.8, R26.2
/SD_DAT_0_DAISY: Card1.7 (DAT0(D0)), J14.16, J16.5, R13.2
/SD_DAT_1_DAISY: Card1.8 (DAT1(RSV)), J14.17, J16.4, R14.2
/SD_DAT_2_DAISY: Card1.1 (DAT2(RSV)), J14.18, J16.3, R15.2
/SD_DAT_3_DAISY: Card1.2 (CDDAT3(CS)), J14.19, J16.2, R16.2
/SD_MISO: Card2.7 (DAT0(D0)), J2.6, J3.10, R25.2
/SD_MOSI: Card2.3 (CMD(DI)), J2.1, J3.15, R27.2
/SD_SCK: Card2.5 (CLK(SCLK)), J2.7, J3.9
ESP-3.3V: C24.2, C25.2, Card2.4 (VDD), J2.15, J3.1, R25.1, R26.1, R27.1, R32.1
GND: C1.2, C3.1, C4.2, C6.1, C7.2, C10.2, C13.2, C14.1, C15.2, C16.2, C17.2, C18.1, C20.2, C21.2, C22.2, C23.2, C24.1, C25.1, C26.1, C27.1, C28.1, C29.1, C30.2, C31.1, C32.1, Card1.6 (VSS), Card1.10 (GND), Card1.11 (GND), Card1.12 (GND), Card1.13 (GND), Card2.6 (VSS), Card2.10 (GND), Card2.11 (GND), Card2.12 (GND), Card2.13 (GND), D1.1 (K), D2.1 (K), D3.1 (K), D4.1 (K), D5.1 (K), IC1.4 (V-), IC2.4 (V-), IC3.4 (V-), IC4.4 (V-), J1.2, J2.14, J3.2, J4.14, J6.S, J7.S, J8.S, J9.S, J10.S, J11.S, J13.1, J14.1, J15.20, J16.20, R8.2, R12.2, R19.2, R20.2, R23.1, TP1.1 (1_1), TP9.1 (1_1), TP10.1 (1_1), TP12.1 (1_1), TP15.1 (1_1), TP17.1 (1_1), TP19.1 (1_1), U1.4 (V-), U2.4 (V-), U3.4 (V-); also elsewhere on the board
unnamed: C1.1, C2.1, J8.T, TP7.1 (1_1)
unnamed: C2.2, R1.1
unnamed: C4.1, C5.1, J9.T, TP8.1 (1_1)
unnamed: C5.2, R3.1
unnamed: C7.1, C8.1, R5.1
unnamed: C9.1, R7.2
unnamed: C9.2, J11.T, R8.1, TP16.1 (1_1)
unnamed: C10.1, C11.1, R9.1
unnamed: C12.1, R11.2
unnamed: C12.2, J10.T, R12.1, TP11.1 (1_1)
unnamed: D1.2 (A), R32.2
unnamed: D2.2 (A), R28.2
unnamed: D3.2 (A), R29.2
unnamed: D4.2 (A), R30.2
unnamed: D5.2 (A), R31.2
unnamed: C3.2, IC1.3 (+), R1.2, R2.1
unnamed: IC1.6 (-), IC1.7
unnamed: C6.2, IC2.3 (+), R3.2, R4.1
unnamed: IC2.6 (-), IC2.7
unnamed: C8.2, IC3.3 (+), R6.2
unnamed: IC3.1, IC3.2 (-), R7.1
unnamed: IC3.6 (-), IC3.7
unnamed: C11.2, IC4.3 (+), R10.2
unnamed: IC4.1, IC4.2 (-), R11.1
unnamed: IC4.6 (-), IC4.7
unnamed: J1.3, J4.13
unnamed: J1.4, J4.12
unnamed: J1.5, J4.11
unnamed: J1.6, J4.10
unnamed: J1.7, J4.9
unnamed: J1.8, J4.8
unnamed: J1.9, J4.7
unnamed: J1.10, J4.6
unnamed: J1.11, J4.5
unnamed: J1.12, J4.4
unnamed: J1.13, J4.3
unnamed: J1.14, J4.2
unnamed: J1.15, J4.1
unnamed: J2.2, J3.14
unnamed: J2.3, J3.13
unnamed: J2.4, J3.12
unnamed: J2.5, J3.11
unnamed: J2.11, J3.5
unnamed: J2.12, J3.4
unnamed: J2.13, J3.3
unnamed: J13.4, J15.17
unnamed: J13.5, J15.16
unnamed: J13.6, J15.15
unnamed: J13.7, J15.14
unnamed: J13.8, J15.13
unnamed: J13.9, J15.12
unnamed: J13.10, J15.11
unnamed: J13.11, J15.10
unnamed: J13.12, J15.9
unnamed: J13.13, J15.8
unnamed: J13.14, J15.7
unnamed: J13.15, J15.6
unnamed: J13.16, J15.5
unnamed: J13.17, J15.4
unnamed: J14.8, J16.13
unnamed: J14.9, J16.12
unnamed: J14.10, J16.11
unnamed: J14.11, J16.10
unnamed: J14.12, J16.9
unnamed: J14.13, J16.8
unnamed: J14.20, J16.1
unnamed: R18.2, U1.1, U1.2 (-)
unnamed: J6.T, R19.1, TP18.1 (1_1), U1.5 (+)
unnamed: R21.1, U2.1, U2.2 (-)
unnamed: J7.T, R20.1, TP20.1 (1_1), U2.5 (+)
unnamed 95: C15.1, C20.1, R22.1, R23.2, U3.3 (+), U3.5 (+); also elsewhere on the board
unnamed: R24.1, U3.1, U3.2 (-)
unnamed: U3.6 (-), U3.7
VCC_Daisy: C13.1, C16.1, C17.1, C18.2, C26.2, C27.2, C28.2, C29.2, C30.1, FB2.1, IC1.8 (V+), IC2.8 (V+), IC3.8 (V+), IC4.8 (V+), J13.2, J15.19, R28.1, R29.1, TP6.1 (1_1), U1.8 (V+), U2.8 (V+)
VCC_ESP32: C21.1, C22.1, C23.1, FB1.2, J1.1, J4.15, TP21.1 (1_1)
VREF: IC1.5 (+), IC2.5 (+), IC3.5 (+), IC4.5 (+), R2.2, R4.2, R6.1, R10.1, R24.2, TP5.1 (1_1)

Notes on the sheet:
Target Device Power Requirements
D34
D23
D33
Tie up floating pins
D14/Rx
D30
Buffered VREF
D15
D13/Tx
D32
D16
RX0
TX0
GND
D14
D25
Audio Out 1
USB Side
DGND Daisy
DAISY SEED
D21
EYE POWER INDICATOR LEDS
D29
D22
Audio In 2
Power Stage
3v3A Daisy
DOIT ESP32 DevKit V1- Pin Headers WATCH THE PINOUT ON THE ESP32 YOU ARE BUYING
3v3D Daisy
Antenna Side
ESP32 Routing
- DAISY SEED: 4- 17V to VIN (Typ: ~50 mA | Max: ~200 mA) - RASPBERRY PI ZERO: 5.0V to 5V (Typ: ~400 mA | Max: ~800 mA) - ESP32: 3.3V or 5V (Typ: ~100 mA | Max: ~500 mA) - TFT Touchscreen 5.0V to 5V (Type: ~500A | Max: ~1A) - Peripherals (Led, I2C extenders) 3.3V (Typ: ~20 mA per component)
Should be 2.5V
D35
SD CARD INTERFACE ESP32
D17
Solderpads/ Test Probes
Audio Out 2
D13

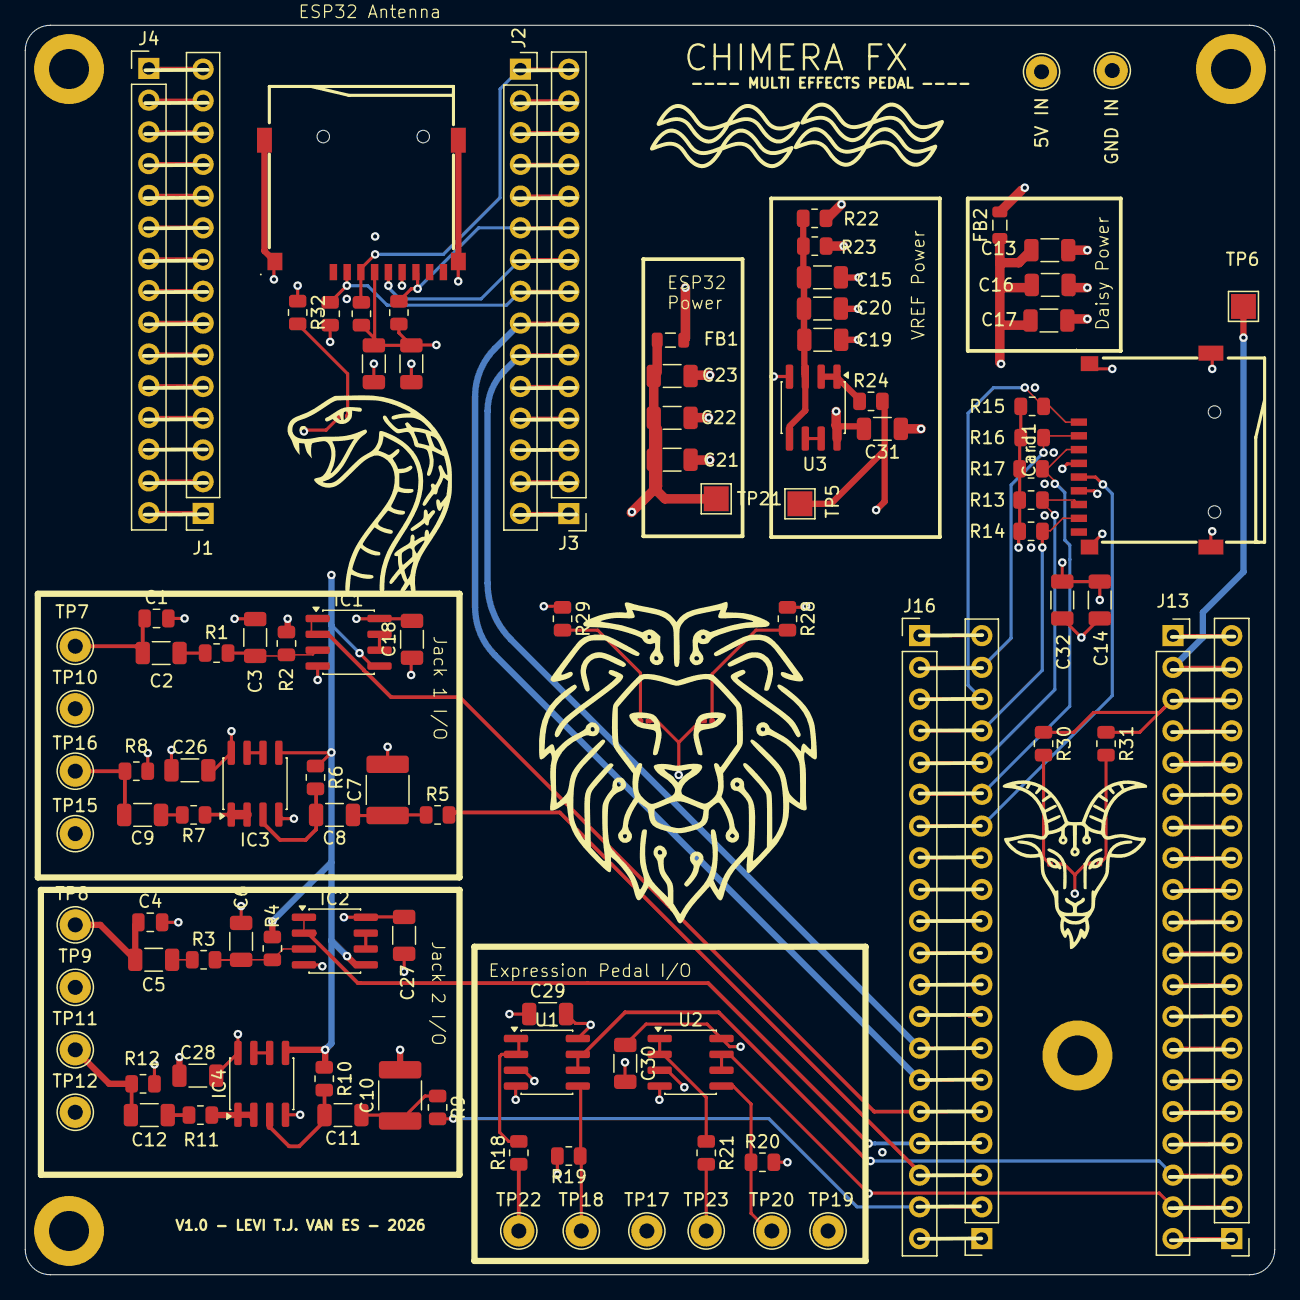
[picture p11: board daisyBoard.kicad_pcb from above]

Board: 4 copper layers, 100.0 x 100.0 mm, 107 parts (0 on the bottom side), 101 nets.

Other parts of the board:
C19: 100u; C_1206_3216Metric

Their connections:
GND: C19.2; also elsewhere on the board
unnamed 95: C19.1; also elsewhere on the board

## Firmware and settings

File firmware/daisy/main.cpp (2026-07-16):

// =============================================================================
// ChimeraMultiFX — Main Entry Point
// =============================================================================
// Effects are created dynamically via UART serial commands.
// No effects are pre-instantiated — the SerialController handles everything.
// =============================================================================
#include "daisy_seed.h"
#include "Router.h"
#include "SerialController.h"

using namespace daisy;

// ==========================================
// Hardware & Global State
// ==========================================
static DaisySeed hw; 
static Router router; // Audio routing engine that manages lanes and effects
static SerialController serial; // UART command interface that allows dynamic control of the router and effects
static UartHandler esp_uart;
static uint8_t esp_uart_rx_dma_buffer[SerialController::UART_RX_DMA_BUFFER_LEN];

void EspUartRxCallback(uint8_t* data,
                       size_t size,
                       void* context,
                       UartHandler::Result result) {
    if (result == UartHandler::Result::OK && context != nullptr) {
        static_cast<SerialController*>(context)->QueueUartBytes(data, size);
    }
}

// ==========================================
// USB CDC Receive Callback
// ==========================================
// Called by libDaisy when bytes arrive over USB serial.
void UsbRxCallback(uint8_t* buf, uint32_t* len) {
    serial.QueueUsbBytes(buf, *len);
}

// ==========================================
// Audio Callback
// ==========================================
void AudioCallback(AudioHandle::InputBuffer in, AudioHandle::OutputBuffer out, size_t size) {
    serial.BeginAudioCallback(size);

    for (size_t i = 0; i < size; i++) {
        auto result = router.Process(in[0][i], in[1][i]);
        out[0][i] = result.out1;
        out[1][i] = result.out2;
    }

    serial.RecordAudioCallback();
}

// ==========================================
// Main
// ==========================================
int main(void) {
    hw.Init();
    hw.SetAudioSampleRate(SaiHandle::Config::SampleRate::SAI_48KHZ);
    float sr = hw.AudioSampleRate();

    // Initialize USB CDC for serial communication
    hw.usb_handle.Init(UsbHandle::FS_INTERNAL);
    System::Delay(500);  // Give USB time to enumerate on the host PC

    UartHandler::Config esp_uart_config;
    esp_uart_config.periph = UartHandler::Config::Peripheral::USART_1;
    esp_uart_config.mode = UartHandler::Config::Mode::TX_RX;
    esp_uart_config.baudrate = 115200;
    esp_uart_config.pin_config.tx = seed::D13; // Physical pin 14 / PB6 / USART1_TX, wire to ESP32 GPIO16 RX
    esp_uart_config.pin_config.rx = seed::D14; // Physical pin 15 / PB7 / USART1_RX, wire from ESP32 GPIO17 TX
    esp_uart.Init(esp_uart_config);

    serial.Init(&router, sr, &hw.usb_handle, &esp_uart);
    serial.StartUartDmaReceive(esp_uart_rx_dma_buffer,
                               sizeof(esp_uart_rx_dma_buffer),
                               EspUartRxCallback,
                               &serial);

    // Register USB receive callback (interrupt-driven)
    hw.usb_handle.SetReceiveCallback(UsbRxCallback, UsbHandle::FS_INTERNAL);

    // Start audio processing
    hw.StartAudio(AudioCallback);

    while (1) {
        serial.ProcessPendingUsb();
        serial.ProcessPendingUart();
        serial.ProcessPendingActions();
    }
}

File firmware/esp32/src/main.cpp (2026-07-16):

#include <Arduino.h>
#include <LittleFS.h>
#include <WebServer.h>
#include <WebSocketsServer.h>
#include "BridgeServer.h"
#include "DaisyBridge.h"
#include "WifiManager.h"

namespace {
WebServer server(80);
WebSocketsServer webSocket(81);
}

void setup() {
	Serial.begin(115200);
	delay(200);
	Serial.println("ChimeraMultiFX bridge boot");
	WifiManager::connect();
	DaisyBridge::begin();
	if (!LittleFS.begin(true)) {
		Serial.println("LittleFS mount failed");
	}
	BridgeServer::setupRoutes(server, webSocket);
	server.begin();
	webSocket.begin();
	Serial.println("HTTP server started on port 80; WebSocket on port 81");
}

void loop() {
	webSocket.loop();
	server.handleClient();
	WifiManager::maintain();
	delay(1);
}

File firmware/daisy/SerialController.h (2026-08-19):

#pragma once
#include "daisy_seed.h"
#include "util/CpuLoadMeter.h"
#include "Router.h"
#include "include/core/SerialTransport.h"
#include "include/core/EffectRegistry.h"
#include "include/core/SerialResponseBuilder.h"

#include <cstring>
#include <cstdio>
#include <cstdlib>
#include <cstdarg>
#include <cmath>

// =============================================================================
// SerialController — Human-readable UART command interface
// =============================================================================
//
// Commands:
//   add <lane> <effect>                      → append effect to lane
//   insert <lane> <slot> <effect>            → insert at position
//   remove <lane> <slot>                     → delete effect
//   swap <lane> <slotA> <slotB>              → swap two effects
//   move <from_lane> <from_slot> <to_lane> <to_slot>
//   set <lane> <slot> <param> <value>        → set effect parameter
//   get <lane> <slot> <param>                → read effect parameter
//   bypass <lane> <slot> <0|1>               → enable/disable effect
//   clear <lane>                             → remove all effects
//   route <lane> <input> <output>            → set lane I/O
//   level <lane> <value>                     → set lane level
//   params <lane> <slot>                     → list effect's param names
//   status                                   → full router state as JSON
//   info                                     → system capabilities as JSON
//   effect <effect>                          → effect parameter metadata as JSON
//   ping                                     → protocol/link test
//   dfu                                      → reboot into STM32 DFU bootloader
//   reset                                    → software-reset the Daisy Seed
//   setpin <pin> <0|1>                       → set GPIO pin high/low
//
// Effect names: distortion, bitcrusher, overdrive, chorus, tremolo, delay, compressor, lowpass
// Input names:  in1, in2, mix, lane0, lane1, lane2, lane3
// Output names: out1, out2, both, none
//
// =============================================================================

class SerialController {
public:
    static constexpr size_t UART_RX_DMA_BUFFER_LEN = 256;
    static constexpr size_t USB_RX_QUEUE_LEN = 512;

    void Init(Router* router,
              float sample_rate,
              daisy::UsbHandle* usb = nullptr,
              daisy::UartHandler* uart = nullptr) {
        router_ = router;
        sample_rate_ = sample_rate;
        usb_ = usb;
        uart_ = uart;
        transport_.Init(usb, uart);
        buf_pos_ = 0;
    }

    // Feed one character at a time (call from main loop)
    void Feed(char c) {
        if (c == '\n' || c == '\r') {
            if (discarding_frame_) {
                discarding_frame_ = false;
                buf_pos_ = 0;
            } else if (buf_pos_ > 0) {
                buf_[buf_pos_] = '\0';
                Execute(buf_);
                buf_pos_ = 0;
            }
        } else if (discarding_frame_) {
            return;
        } else if (buf_pos_ < MAX_CMD_LEN - 1) {
            buf_[buf_pos_++] = c;
        } else {
            framing_error_count_++;
            discarding_frame_ = true;
            buf_pos_ = 0;
        }
    }

    void ProcessPendingActions() {
        if (dfu_requested_) {
            dfu_requested_ = false;
            daisy::System::Delay(250);
            daisy::System::ResetToBootloader(
                daisy::System::BootloaderMode::DAISY_INFINITE_TIMEOUT);
        }
    }

    void ProcessPendingUart() {
        const bool receive_restarted = transport_.MaintainUartReceive();
        const bool receive_overflowed = transport_.TakeRxOverflow();
        if (receive_restarted || receive_overflowed) {
            buf_pos_ = 0;
            discarding_frame_ = false;
        }
        if (receive_overflowed) framing_error_count_++;
        transport_.ProcessPending(HandleTransportByte, this);
    }

    void QueueUartBytes(const uint8_t* data, size_t size) {
        transport_.QueueUartBytes(data, size);
    }

    void QueueUsbBytes(const uint8_t* data, size_t size) {
        for (size_t i = 0; i < size; i++) {
            const uint16_t next = static_cast<uint16_t>((usb_rx_head_ + 1) % USB_RX_QUEUE_LEN);
            if (next == usb_rx_tail_) {
                usb_rx_overflowed_ = true;
                continue;
            }
            usb_rx_queue_[usb_rx_head_] = data[i];
            usb_rx_head_ = next;
        }
    }

    void ProcessPendingUsb() {
        if (usb_rx_overflowed_) {
            usb_rx_tail_ = usb_rx_head_;
            usb_rx_overflowed_ = false;
            framing_error_count_++;
            buf_pos_ = 0;
            discarding_frame_ = false;
        }
        while (usb_rx_tail_ != usb_rx_head_) {
            const char byte = static_cast<char>(usb_rx_queue_[usb_rx_tail_]);
            usb_rx_tail_ = static_cast<uint16_t>((usb_rx_tail_ + 1) % USB_RX_QUEUE_LEN);
            Feed(byte);
        }
    }

    void StartUartDmaReceive(uint8_t* buffer,
                             size_t size,
                             daisy::UartHandler::CircularRxCallbackFunctionPtr callback,
                             void* context) {
        transport_.StartUartDmaReceive(buffer, size, callback, context);
    }

    void BeginAudioCallback(size_t samples) {
        if (samples == 0 || sample_rate_ <= 0.0f) return;
        if (!cpu_load_meter_initialized_) {
            cpu_load_meter_.Init(sample_rate_, static_cast<int>(samples));
            cpu_load_meter_initialized_ = true;
        }
        cpu_load_meter_.OnBlockStart();
    }

    void RecordAudioCallback() {
        if (!cpu_load_meter_initialized_) return;

        cpu_load_meter_.OnBlockEnd();
        const float cpu_usage = cpu_load_meter_.GetAvgCpuLoad() * 100.0f;
        if (!std::isfinite(cpu_usage) || cpu_usage < 0.0f) {
            audio_cpu_usage_hundredths_ = 0;
            return;
        }

        const float rounded_hundredths = (cpu_usage * 100.0f) + 0.5f;
        if (rounded_hundredths >= 4294967295.0f) {
            audio_cpu_usage_hundredths_ = 0xffffffffu;
        } else {
            audio_cpu_usage_hundredths_ = static_cast<uint32_t>(rounded_hundredths);
        }
    }
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

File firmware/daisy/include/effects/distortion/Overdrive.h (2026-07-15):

#pragma once
#include "Effect.h"
#include <cmath>
#include <cstring>

// Asymmetric soft overdrive voiced for guitar rather than a hard mathematical
// clipper.  A gentle bass cut keeps low notes from making the distortion pump,
// while 2x interpolated waveshaping and reconstruction filtering reduce the
// fold-back harmonics that make high-drive digital distortion sound brittle.
class Overdrive : public Effect {
public:
	void Init(float sample_rate) override {
		sample_rate_ = sample_rate;
		drive_ = 4.0f;
		tone_  = 0.55f;
		level_ = 0.8f;
		mix_   = 1.0f;
		input_state_ = 0.0f;
		bass_state_ = 0.0f;
		prev_pre_ = 0.0f;
		aa_state_ = 0.0f;
		tone_state_ = 0.0f;
		post_state_ = 0.0f;
		dc_input_ = 0.0f;
		dc_output_ = 0.0f;
		input_coeff_ = LowPassCoeff(11000.0f, sample_rate_);
		bass_coeff_ = LowPassCoeff(120.0f, sample_rate_);
		smoothing_coeff_ = LowPassCoeff(35.0f, sample_rate_);
		UpdateDrive();
		UpdateToneCoeff();
		drive_gain_smoothed_ = drive_gain_;
		output_trim_smoothed_ = output_trim_;
		bass_cut_smoothed_ = bass_cut_;
		aa_coeff_smoothed_ = aa_coeff_;
		tone_smoothed_ = tone_;
		tone_coeff_smoothed_ = tone_coeff_;
		post_coeff_smoothed_ = post_coeff_;
		level_smoothed_ = level_;
		mix_smoothed_ = mix_;
	}

	float Process(float in) override {
		// Serial controls can change between audio blocks.  Smoothing prevents
		// those steps from becoming audible clicks or zipper noise.
		Smooth(drive_gain_smoothed_, drive_gain_);
		Smooth(output_trim_smoothed_, output_trim_);
		Smooth(bass_cut_smoothed_, bass_cut_);
		Smooth(aa_coeff_smoothed_, aa_coeff_);
		Smooth(tone_smoothed_, tone_);
		Smooth(tone_coeff_smoothed_, tone_coeff_);
		Smooth(post_coeff_smoothed_, post_coeff_);
		Smooth(level_smoothed_, level_);
		Smooth(mix_smoothed_, mix_);

		input_state_ += input_coeff_ * (in - input_state_);
		bass_state_ += bass_coeff_ * (input_state_ - bass_state_);
		float pre = input_state_ - (bass_state_ * bass_cut_smoothed_);
		float midpoint = 0.5f * (prev_pre_ + pre);
		prev_pre_ = pre;

		ShapeOversampled(midpoint);
		float shaped = ShapeOversampled(pre);

		// The low/high blend behaves like a guitar pedal tone control: clockwise
		// restores pick attack without removing the warm low-frequency body.
		tone_state_ += tone_coeff_smoothed_ * (shaped - tone_state_);
		float bright = shaped - tone_state_;
		float voiced = tone_state_ + (bright * (0.35f + (tone_smoothed_ * 1.25f)));
		post_state_ += post_coeff_smoothed_ * (voiced - post_state_);

		// Asymmetric clipping sounds tube-like but creates a small DC component.
		// This blocker removes DC without thinning audible guitar bass.
		float dc_blocked = post_state_ - dc_input_ + (0.995f * dc_output_);
		dc_input_ = post_state_;
		dc_output_ = dc_blocked;
		float wet = dc_blocked * level_smoothed_;

		return (in * (1.0f - mix_smoothed_)) + (wet * mix_smoothed_);
	}

	const char* GetName() const override { return "overdrive"; }
	EffectCategory GetCategory() const override { return EffectCategory::Distortion; }

	void SetParam(const char* name, float value) override {
		if      (strcmp(name, "drive") == 0) SetDrive(value);
		else if (strcmp(name, "tone") == 0)  SetTone(value);
		else if (strcmp(name, "level") == 0) SetLevel(value);
		else if (strcmp(name, "mix") == 0)   SetMix(value);
	}

	float GetParam(const char* name) override {
		if      (strcmp(name, "drive") == 0) return drive_;
		else if (strcmp(name, "tone") == 0)  return tone_;
		else if (strcmp(name, "level") == 0) return level_;
		else if (strcmp(name, "mix") == 0)   return mix_;
		return 0.0f;
	}

	const char* GetParamList() const override { return "drive,tone,level,mix"; }

	int GetParamCount() const override { return 4; }
	bool GetParamInfo(int index, EffectParamInfo& info) const override {
		switch (index) {
			case 0: info = {"drive", "Drive", "", "float", "linear", 1.0f, 16.0f, 4.0f, 0.1f}; return true;
			case 1: info = {"tone", "Tone", "", "float", "linear", 0.0f, 1.0f, 0.55f, 0.01f}; return true;
			case 2: info = {"level", "Level", "", "float", "linear", 0.0f, 2.0f, 0.8f, 0.01f}; return true;
			case 3: info = {"mix", "Mix", "", "float", "linear", 0.0f, 1.0f, 1.0f, 0.01f}; return true;
			default: return false;
		}
	}

	void SetDrive(float drive) { drive_ = Clamp(drive, 1.0f, 16.0f); UpdateDrive(); }
	void SetTone(float tone)   { tone_ = Clamp(tone, 0.0f, 1.0f); UpdateToneCoeff(); }
	void SetLevel(float level) { level_ = Clamp(level, 0.0f, 2.0f); }
	void SetMix(float mix)     { mix_ = Clamp(mix, 0.0f, 1.0f); }

private:
	float LowPassCoeff(float cutoff, float rate) const {
		float x = -2.0f * 3.14159265f * cutoff / rate;
		return Clamp(1.0f - expf(x), 0.001f, 0.95f);
	}

	void UpdateDrive() {
		float normalized = (drive_ - 1.0f) / 15.0f;
		drive_gain_ = 1.0f + (normalized * 9.5f);
		output_trim_ = 1.0f / (1.0f + (normalized * 1.8f));
		bass_cut_ = 0.18f + (normalized * 0.28f);
		aa_coeff_ = LowPassCoeff(10000.0f - (normalized * 2500.0f), sample_rate_ * 2.0f);
	}

	void UpdateToneCoeff() {
		float cutoff = 700.0f + (tone_ * 4800.0f);
		tone_coeff_ = LowPassCoeff(cutoff, sample_rate_);
		post_coeff_ = LowPassCoeff(6800.0f + (tone_ * 3600.0f), sample_rate_);
	}

	float ShapeOversampled(float in) {
		float driven = in * drive_gain_smoothed_;
		float shaped = driven >= 0.0f ? tanhf(driven) : tanhf(driven * 0.78f) * 1.08f;
		aa_state_ += aa_coeff_smoothed_ * ((shaped * output_trim_smoothed_) - aa_state_);
		return aa_state_;
	}

	void Smooth(float& current, float target) {
		current += smoothing_coeff_ * (target - current);
	}

	float sample_rate_ = 48000.0f;
	float drive_ = 6.0f;
	float tone_ = 0.55f;
	float level_ = 0.8f;
	float mix_ = 1.0f;
	float input_state_ = 0.0f;
	float bass_state_ = 0.0f;
	float prev_pre_ = 0.0f;
	float aa_state_ = 0.0f;
	float tone_state_ = 0.0f;
	float post_state_ = 0.0f;
	float dc_input_ = 0.0f;
	float dc_output_ = 0.0f;
	float input_coeff_ = 0.1f;
	float bass_coeff_ = 0.1f;
	float smoothing_coeff_ = 0.01f;
	float aa_coeff_ = 0.1f;
	float aa_coeff_smoothed_ = 0.1f;
	float tone_smoothed_ = 0.55f;
	float tone_coeff_ = 0.1f;
	float post_coeff_ = 0.1f;
	float drive_gain_ = 4.0f;
	float drive_gain_smoothed_ = 4.0f;
	float output_trim_ = 0.8f;
	float output_trim_smoothed_ = 0.8f;
	float bass_cut_ = 0.25f;
	float bass_cut_smoothed_ = 0.25f;
	float tone_coeff_smoothed_ = 0.1f;
	float post_coeff_smoothed_ = 0.1f;
	float level_smoothed_ = 0.8f;
	float mix_smoothed_ = 1.0f;
};

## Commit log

2026-05-21 Add initial project structure and documentation for ChimeraMultiFX
    - Created README.md with project overview, hardware details, and building instructions.
    - Added .gitignore to exclude build artifacts and IDE files.
    - Initialized Makefile and source files for Daisy and ESP32 firmware.
    - Created requirements.txt for Pi Zero software dependencies.
    - Implemented main entry point for Pi Zero synth software.
2026-06-02 Add new models and libraries for voltage regulators and operational amplifiers
    - Created new symbol files for LM7805, LM7812, LM7815, and LM7905 voltage regulators.
    - Added TL072 operational amplifier macromodel subcircuit.
    - Introduced a new library file 'regulators.lib' containing SPICE models for the above regulators.
    - Added reference material for the Terrarium Platform, including a parts list, schematic, wiring diagram, and drill template.
    - Included mechanical design assets for the ChimeraMultiFX pedal.
    - Established a software directory structure with README files for web UI and Raspberry Pi kiosk setup.
    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
    [psu.kicad_pcb, psu.kicad_sch]
2026-06-04 feat: update audio-daisy board schematic and add custom footprint library
    [daisyBoard.kicad_pcb, daisyBoard.kicad_sch, psu.kicad_sch]
2026-06-29 feat: implement effect framework with Delay and Distortion effects
2026-06-30 feat: add new effects including Bitcrusher, TanhDistortion, Chorus, Tremolo, Compressor, LowPass, and Delay; update effect chain in main
2026-07-01 feat: add SerialController for dynamic effect management via UART commands; update main to utilize new controller
2026-07-02 feat: add Daisy Seed firmware findings documentation and improve parameter clamping in effects
2026-07-04 feat: add DFU command for rebooting into STM32 bootloader and process pending actions in main loop
    [SerialController.h, main.cpp]
2026-07-10 feat: enhance Daisy firmware with serial control and add ESP32 bridge documentation
2026-07-10 feat: update Daisy firmware documentation and enhance ESP32 UART bridge functionality
2026-07-14 Final working adjustments to uart protocol
2026-07-15 moved the clamp function back to the Effects parent base class
2026-07-15 added dynamic effect categories throug hte info api endpoint and made the esp32 use this dynamic endpoint
2026-07-15 renamed effects to camel case
2026-07-15 Made uart bridge much more reliable
2026-08-09 Intermediate update
    [JLCPCB.kicad_pcb, daisyBoard.csv, daisyBoard.kicad_pcb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]
2026-08-09 review AI PCB
    [daisyBoard.kicad_pcb, daisyBoard.kicad_sch]
2026-08-10 Updated and assigned JLCPCB parts using JLCPCB toolbox
    [BOM-daisyBoard.csv, daisyBoard.kicad_pcb, daisyBoard.kicad_sch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]
2026-08-13 PCWork Update
    [BOM-daisyBoard.csv, daisyBoard.kicad_pcb, daisyBoard.kicad_sch]
2026-08-16 Added compatible components
    [daisyBoard.kicad_pcb, daisyBoard.kicad_sch]
2026-08-17 updated design and added start for indicator leds on design
    [daisyBoard.kicad_pcb, daisyBoard.kicad_sch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]
2026-08-17 removed grbrs and updated corner design pcb and still need to add led resistors
    [daisyBoard.kicad_pcb, daisyBoard.kicad_sch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]
2026-08-17 added led values
    [daisyBoard.kicad_pcb, daisyBoard.kicad_sch]
2026-08-17 updated missing pcb connection
    [daisyBoard.kicad_pcb]
2026-08-17 connectivtity chagns
    [daisyBoard.kicad_pcb]
2026-08-17 Applied review and updated ground plane and power plane design
    [daisyBoard.kicad_pcb, daisyBoard.kicad_sch]
2026-08-17 added a powerplane ground to even more reduce EMF noise
    [daisyBoard.kicad_pcb]
2026-08-17 added larger ferrite bead in components 600ohm @ 100Mhz
    [daisyBoard.kicad_sch]
2026-08-17 alignment changes
    [daisyBoard.kicad_pcb]
2026-08-17 added some changes and checks adnd did a review
    [daisyBoard.kicad_pcb, daisyBoard.kicad_sch]
2026-08-18 updated TL072 to the H model in order to account ofr the 5V in that is currently lower than the 7V TL072 operating range
    [daisyBoard.kicad_pcb, daisyBoard.kicad_sch]
2026-08-18 moved some pads again
    [daisyBoard.kicad_pcb, daisyBoard.kicad_sch]
2026-08-18 did drc checks fix and connected flaoting pins on op amps
    [daisyBoard.kicad_pcb, daisyBoard.kicad_sch]
2026-08-18 updated some still in pad connections
    [daisyBoard.kicad_pcb, daisyBoard.kicad_sch]
2026-08-18 Moved ESP32 SD to keep out of antenna area
    [daisyBoard.kicad_pcb]
2026-08-18 last review and update of some things. Still need to adress VREF trace length
    [daisyBoard.kicad_pcb, daisyBoard.kicad_sch]
2026-08-18 Changed copper pours to exclude wide area around antenna
    [daisyBoard.kicad_pcb, daisyBoard.kicad_sch]
2026-08-19 added new review and changed VREF to lower capacitance and lower resistors to reduce load time of the circuit to get to VREF
    [daisyBoard-refilled.kicad_pcb, daisyBoard.kicad_pcb]
2026-08-19 fixed all DRC and ERC errors
    [daisyBoard.kicad_pcb, daisyBoard.kicad_sch]
2026-08-22 updated schematic
2026-11-08 updated pin headers adn gerbers
